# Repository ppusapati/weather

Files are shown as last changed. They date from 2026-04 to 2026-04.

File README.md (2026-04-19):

# Weather Station Firmware

## STM32F407 Weather Station — Embedded Rust Firmware

A production-grade weather station firmware written in Rust targeting the **STM32F407VGT6** MCU.
It collects environmental data from multiple sensors and transmits readings over
**WiFi (ATWINC1500), BLE (RN4870), LoRa, UART, MQTT, and HTTP** — with optional
Ethernet (W5500) and Cellular (SIM7600E-H) connectivity.

---

## Architecture Overview

```
┌─────────────────────────────────────────────────────────────┐
│                    APPLICATION LAYER                        │
│  ┌──────────┐ ┌────────────┐ ┌──────────┐ ┌────────────┐  │
│  │Scheduler │ │Data Pipeline│ │  Power   │ │    OTA     │  │
│  │          │ │  & Fusion  │ │  Mgmt    │ │  Updater   │  │
│  └──────────┘ └────────────┘ └──────────┘ └────────────┘  │
├─────────────────────────────────────────────────────────────┤
│                  COMMUNICATION LAYER                        │
│  ┌──────┐ ┌─────┐ ┌──────┐ ┌──────┐ ┌──────┐ ┌────────┐  │
│  │ WiFi │ │ BLE │ │ LoRa │ │ UART │ │ MQTT │ │  HTTP  │  │
│  └──────┘ └─────┘ └──────┘ └──────┘ └──────┘ └────────┘  │
├─────────────────────────────────────────────────────────────┤
│                     DRIVER LAYER                            │
│  ┌───────┐ ┌──────────┐ ┌──────┐ ┌──────┐ ┌───────────┐  │
│  │BME280 │ │Wind Speed│ │ Rain │ │  UV  │ │   Light   │  │
│  │Temp/  │ │& Dir     │ │Gauge │ │Index │ │  (BH1750) │  │
│  │Hum/Pr │ │(AS5600)  │ │(Tip) │ │SI1145│ │           │  │
│  └───────┘ └──────────┘ └──────┘ └──────┘ └───────────┘  │
├─────────────────────────────────────────────────────────────┤
│                 HARDWARE ABSTRACTION                        │
│  ┌──────┐ ┌──────┐ ┌──────┐ ┌──────┐ ┌──────┐ ┌───────┐  │
│  │ I2C  │ │ SPI  │ │ ADC  │ │ GPIO │ │ UART │ │ Timer │  │
│  └──────┘ └──────┘ └──────┘ └──────┘ └──────┘ └───────┘  │
├─────────────────────────────────────────────────────────────┤
│                   STM32F407 HARDWARE                        │
│  ARM Cortex-M4F @ 168 MHz · 192KB SRAM · 1MB Flash        │
└─────────────────────────────────────────────────────────────┘
```

## MCU Selection — STM32F407VGT6

| Criterion | STM32F407VGT6 |
|---|---|
| CPU | ARM Cortex-M4F @ 168 MHz (with FPU) |
| RAM | 192 KB SRAM (128 KB + 64 KB CCM) |
| Flash | 1 MB internal |
| WiFi | ATWINC1500 module (SPI3) |
| Bluetooth | RN4870 BLE 5.0 module (USART3) |
| ADC | 3x 12-bit SAR, 16 channels |
| I2C / SPI / UART | 3 / 3 / 4 |
| GPIO | 82 programmable |
| Standby | ~2 µA |
| Temp range | -40°C to +105°C (Industrial) |
| Rust support | `stm32f4xx-hal` + `cortex-m-rt` (mature) |

**Why STM32F407?** Industrial temperature range for outdoor deployment, hardware FPU for
sensor math, three SPI buses for concurrent LoRa/Ethernet/WiFi, dedicated UART for each
communication module, and excellent Rust embedded-hal support. Single-MCU architecture
simplifies firmware (one codebase, one toolchain).

## Sensors

| Sensor | Measures | Interface | Address / Pin |
|---|---|---|---|
| BME280 | Temperature, humidity, pressure | I2C | 0x76 |
| AS5600 | Wind direction (magnetic encoder) | I2C | 0x36 |
| Anemometer | Wind speed (pulse count) | GPIO interrupt | GPIO 4 |
| Rain gauge | Rainfall (tipping bucket) | GPIO interrupt | GPIO 5 |
| SI1145 | UV index | I2C | 0x60 |
| BH1750 | Ambient light (lux) | I2C | 0x23 |

## Communication Channels

| Channel | Protocol | Use Case |
|---|---|---|
| **WiFi** | 802.11n | Primary uplink to cloud/MQTT broker |
| **BLE 5.0** | GATT | Mobile app config & live readings |
| **LoRa** | LoRaWAN (SX1276 via SPI) | Long-range low-power telemetry |
| **UART** | Serial 115200 | Debug console & wired data export |
| **MQTT** | MQTT v3.1.1 over TCP/TLS | Cloud telemetry (over WiFi) |
| **HTTP** | REST JSON API | Local web dashboard + OTA updates |

## Industry Modules

The firmware supports optional industry-specific extensions via Cargo features:

| Feature | Industry | Additional Sensors | Analytics |
|---|---|---|---|
| `agriculture` | Precision Farming | Soil moisture (×2), soil temp, leaf wetness | ET₀, GDD, frost alerts, irrigation scheduling, disease risk, spray windows |
| `solar` | Photovoltaic Monitoring | Pyranometer, panel temp (×2), power meter | Irradiance, yield estimation, peak sun hours, performance ratio, soiling loss, cloud transients |
| `india` | Indian Regional | PM2.5 particulate sensor | Monsoon tracking, IMD heat wave alerts, cyclone detection, NAQI air quality, IST timezone, IN865 LoRa |
| `all-industries` | All | All above | All above |
| `cellular` | Remote Sites | SIM7600E-H LTE modem | Cellular uplink for remote stations |
| `ethernet` | Industrial | W5500 wired Ethernet | Reliable wired connectivity + Modbus TCP |
| `sdcard` | Data Logging | Micro-SD card (SPI2) | FAT32 CSV logging with daily file rotation, GB-scale storage |
| `all-comms` | All Comms | Cellular + Ethernet + SD card | All communication + storage channels |
| `full-system` | Everything | All sensors + all comms | All analytics + SCADA + Cloud |

### Operating Modes

| Mode | Cloud (MQTT/HTTP) | SCADA (Modbus RS485) | Selection |
|---|:---:|:---:|---|
| **Cloud** | Yes | — | DIP 0:0 |
| **SCADA** | Yes | Yes | DIP 0:1 |
| **Hybrid** | Yes | Yes | DIP 1:0 (default) |

```bash
# Build with agriculture module
cargo build --release --features agriculture

# Build with solar module
cargo build --release --features solar

# Build with India regional module
cargo build --release --features india

# Build with all industry modules
cargo build --release --features all-industries

# Build with cellular modem support
cargo build --release --features cellular

# Build with Ethernet support
cargo build --release --features ethernet

# Build with SD card data logging
cargo build --release --features sdcard

# Full system: all industries + all comms
cargo build --release --features full-system
```

See [docs/INDUSTRY_AGRICULTURE.md](docs/INDUSTRY_AGRICULTURE.md),
[docs/INDUSTRY_SOLAR.md](docs/INDUSTRY_SOLAR.md),
[docs/INDUSTRY_INDIA.md](docs/INDUSTRY_INDIA.md), and
[docs/STM32_SCADA.md](docs/STM32_SCADA.md) for detailed documentation.

## Building

```bash
# Install Rust + ARM toolchain
rustup install nightly
rustup target add thumbv7em-none-eabihf
cargo install probe-rs-tools

# Build (base weather station)
cd firmware
cargo build --release --target thumbv7em-none-eabihf

# Flash via SWD (ST-Link V2)
probe-rs run --chip STM32F407VGTx target/thumbv7em-none-eabihf/release/weather-station
```

## Project Structure

```
weather/
├── README.md
├── docs/
│   ├── ARCHITECTURE.md
│   ├── REQUIREMENTS.md
│   ├── API.md
│   ├── HARDWARE.md
│   ├── INDUSTRY_INDIA.md
│   └── diagrams/
│       ├── system_architecture.md
│       ├── circuit_diagram.md
│       ├── communication_flow.md
│       ├── state_machine.md
│       ├── data_pipeline.md
│       └── sequence_diagrams.md
├── firmware/
│   ├── Cargo.toml
│   ├── build.rs
│   ├── .cargo/config.toml
│   ├── memory.x
│   └── src/
│       ├── main.rs
│       ├── config.rs
│       ├── error.rs
│       ├── drivers/
│       │   ├── mod.rs
│       │   ├── bme280.rs
│       │   ├── wind.rs
│       │   ├── rain.rs
│       │   ├── uv.rs
│       │   ├── light.rs
│       │   ├── soil_moisture.rs  (agriculture)
│       │   ├── soil_temp.rs      (agriculture/solar)
│       │   ├── leaf_wetness.rs   (agriculture)
│       │   ├── pyranometer.rs    (solar)
│       │   ├── pm25.rs           (india)
│       │   ├── stm32f407.rs     (MCU HAL + pin map)
│       │   ├── atwinc1500.rs   (WiFi SPI driver)
│       │   └── rn4870.rs       (BLE UART driver)
│       ├── comms/
│       │   ├── mod.rs
│       │   ├── wifi.rs
│       │   ├── ble.rs
│       │   ├── lora.rs
│       │   ├── uart_console.rs
│       │   ├── mqtt.rs
│       │   ├── http.rs
│       │   └── modbus_rtu.rs    (Modbus RS485 slave)
│       ├── core/
│       │   ├── mod.rs
│       │   ├── scheduler.rs
│       │   ├── data_pipeline.rs
│       │   ├── power.rs
│       │   ├── ota.rs
│       │   └── mode_manager.rs  (SCADA/Cloud/Hybrid)
│       ├── industry/
│       │   ├── mod.rs
│       │   ├── agriculture.rs    (agriculture)
│       │   ├── solar.rs          (solar)
│       │   └── india.rs          (india)
│       ├── storage/
│       │   ├── mod.rs
│       │   └── flash.rs
│       └── utils/
│           ├── mod.rs
│           ├── fmt.rs
│           ├── ring_buffer.rs
│           └── crc.rs
└── tests/
    └── integration.rs
```

## License

MIT

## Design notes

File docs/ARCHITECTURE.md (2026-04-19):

# System Architecture

## 1. Overview

The weather station firmware follows a **layered architecture** with strict
dependency rules: upper layers depend on lower layers, never the reverse.

```
┌─────────────────────────────────────────────────────────────────────┐
│ LAYER 4 — APPLICATION                                               │
│                                                                     │
│  Scheduler ──► Data Pipeline ──► Power Manager ──► OTA Updater     │
│       │              │                │                              │
│       ▼              ▼                ▼                              │
├─────────────────────────────────────────────────────────────────────┤
│ LAYER 3 — COMMUNICATION                                             │
│                                                                     │
│  WiFi Manager ──► MQTT Client ──► HTTP Server                      │
│  BLE GATT Server                                                    │
│  LoRa Transceiver (SX1276)                                         │
│  UART Console                                                       │
├─────────────────────────────────────────────────────────────────────┤
│ LAYER 2 — DRIVERS                                                   │
│                                                                     │
│  BME280 │ AS5600 │ Anemometer │ Rain Gauge │ SI1145 │ BH1750      │
├─────────────────────────────────────────────────────────────────────┤
│ LAYER 1 — HAL (stm32f4xx-hal)                                       │
│                                                                     │
│  I2C │ SPI │ ADC │ GPIO │ UART │ Timer │ RTC │ NVS                │
├─────────────────────────────────────────────────────────────────────┤
│ LAYER 0 — HARDWARE                                                  │
│                                                                     │
│  STM32F407VGT6 — ARM Cortex-M4F @ 168 MHz                          │
│  192 KB SRAM (128 KB + 64 KB CCM) + 1 MB Flash                    │
│  ATWINC1500 WiFi (SPI3) · RN4870 BLE (USART3)                     │
└─────────────────────────────────────────────────────────────────────┘
```

## 2. Single-Core Cooperative Scheduling

The STM32F407 runs a cooperative task scheduler on a single Cortex-M4F core.
Tasks are time-sliced by priority, with ISRs handling time-critical pulse counting.

| Task Group | Responsibility |
|---|---|
| **Sensor tasks** | Sensor sampling, data fusion, calibration, alerts |
| **Comms tasks** | WiFi poll, BLE poll, LoRa TX/RX, MQTT, HTTP, UART, Modbus RTU |
| **System tasks** | Power management, OTA updates, watchdog feed, status reporting |

All tasks share a single execution context with cooperative yielding.

## 3. Data Flow

```
Sensors ──► Raw ADC / I2C ──► Driver Layer ──► Calibration & Filtering
    │                                                │
    ▼                                                ▼
GPIO ISRs ──► Pulse Counters ──────────────► Data Pipeline
                                                     │
                                         ┌───────────┼───────────┐
                                         ▼           ▼           ▼
                                      Flash       MQTT/HTTP    BLE/LoRa
                                     Storage      (WiFi)      Broadcast
```

### 3.1 Sampling Schedule

| Sensor | Interval | Method |
|---|---|---|
| BME280 (T/H/P) | 10 s | Polled (I2C) |
| Wind speed | Continuous | GPIO ISR pulse count, computed every 5 s |
| Wind direction | 5 s | Polled (I2C — AS5600 angle register) |
| Rain gauge | Continuous | GPIO ISR tip count, accumulated |
| UV index | 30 s | Polled (I2C) |
| Ambient light | 30 s | Polled (I2C) |

### 3.2 Data Fusion

Raw sensor values go through a pipeline:

1. **Calibration** — Apply per-sensor offset/gain from NVS
2. **Filtering** — Exponential moving average (configurable α)
3. **Validation** — Range checks, stuck-sensor detection
4. **Packaging** — Structured `WeatherReading` with timestamp

## 4. Communication Architecture

### 4.1 Channel Priority & Fallback

```
PRIMARY:   WiFi ──► MQTT Broker ──► Cloud Dashboard
                │
                └──► HTTP REST API (local access)

SECONDARY: BLE GATT ──► Mobile App (config + live data)

TERTIARY:  LoRa ──► LoRaWAN Gateway ──► Network Server

DEBUG:     UART ──► Serial Console (always active)
```

If WiFi is unavailable, data is buffered to flash and LoRa becomes the primary
uplink. BLE remains available for local configuration regardless of WiFi state.

### 4.2 MQTT Topic Structure

```
weather/{device_id}/telemetry      — periodic readings (JSON)
weather/{device_id}/status         — heartbeat, battery, RSSI
weather/{device_id}/alerts         — threshold-triggered alerts
weather/{device_id}/cmd            — remote commands (subscribe)
weather/{device_id}/ota            — OTA control channel
```

### 4.3 BLE GATT Services

| Service UUID | Characteristic | Properties |
|---|---|---|
| `0x181A` (Env Sensing) | Temperature | Read, Notify |
| | Humidity | Read, Notify |
| | Pressure | Read, Notify |
| `0xFFE0` (Custom) | Wind Speed | Read, Notify |
| | Wind Direction | Read, Notify |
| | Rain Accumulation | Read, Notify |
| | UV Index | Read, Notify |
| | Light Level | Read, Notify |
| `0xFFE1` (Config) | Sampling Interval | Read, Write |
| | WiFi SSID | Write |
| | WiFi Password | Write |
| | Device Name | Read, Write |

## 5. Power Management

### 5.1 Operating Modes

| Mode | Current Draw | Duration | Trigger |
|---|---|---|---|
| **Active** | ~170 mA | During sampling + TX | Scheduler wake |
| **Sleep (WFI)** | ~20 mA | Between tasks | Auto after TX |
| **Stop** | ~20 µA | Idle periods | Configurable |
| **Standby** | ~2 µA | Extended idle | Battery < 20% |

### 5.2 Battery Monitoring

- ADC channel monitors battery voltage via resistive divider
- Low-battery threshold triggers deep sleep with LoRa-only wake cycle
- Critical battery (<3.3V) triggers graceful shutdown after final status message

## 6. OTA Update Flow

```
1. Device checks /ota endpoint on boot + every 6 hours
2. Server responds with firmware version + SHA256 hash
3. If newer version → download binary over HTTPS
4. Verify SHA256 → write to OTA partition
5. Set boot partition → reboot
6. New firmware validates → mark as stable
7. Failure → rollback to previous partition
```

## 7. Error Handling Strategy

- **Sensor failure**: Mark channel as degraded, report NaN, continue other sensors
- **WiFi failure**: Buffer data to flash, retry with exponential backoff
- **MQTT failure**: Queue messages (up to 1000), replay on reconnect
- **LoRa failure**: Fall back to store-and-forward
- **Flash full**: Overwrite oldest records (circular buffer)
- **Watchdog**: Hardware WDT resets system if main loop stalls > 30 s

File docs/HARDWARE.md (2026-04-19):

# Hardware Design

## 1. Bill of Materials (BOM)

| # | Component | Part Number | Qty | Interface | Notes |
|---|---|---|-----|---|---|
| 1 | STM32F407VGT6 | STM32F407VGT6 | 1 | — | ARM Cortex-M4F, 1MB Flash, 192KB SRAM |
| 2 | BME280 breakout | GY-BME280 | 1 | I2C | Temp/humidity/pressure |
| 3 | AS5600 magnetic encoder | AS5600-ASOM | 1 | I2C | Wind direction |
| 4 | Anemometer | SEN-15901 | 1 | GPIO | Reed switch, 1 pulse/rev |
| 5 | Rain gauge (tipping bucket) | SEN-15902 | 1 | GPIO | 0.2 mm/tip |
| 6 | SI1145 UV sensor | SI1145-A10-GMR | 1 | I2C | UV/Vis/IR |
| 7 | BH1750 light sensor | BH1750FVI | 1 | I2C | Ambient light |
| 8 | SX1276 LoRa module | RFM95W | 1 | SPI | 868/915 MHz |
| 9 | LiPo battery | — | 1 | — | 3.7V 3000mAh |
| 10 | Solar panel | — | 1 | — | 6V 2W |
| 11 | TP4056 charge controller | TP4056 | 1 | — | USB-C + solar input |
| 12 | AMS1117-3.3 regulator | AMS1117-3.3 | 1 | — | 3.3V LDO |
| 13 | Diode magnet (wind vane) | N52 6mm | 1 | — | For AS5600 |
| 14 | Pull-up resistors | — | 4 | — | 4.7kΩ for I2C |
| 15 | Decoupling caps | — | 6 | — | 100nF ceramic |
| 16 | Voltage divider resistors | — | 2 | — | 100kΩ + 100kΩ for batt |
| 17 | Micro-SD card holder | Molex 5031821852 | 1 | SPI2 | Push-push, CS=PD10, DET=PD11 |
| 18 | SD card decoupling cap | — | 1 | — | 100nF on VCC |
| 19 | SD card detect pull-up | — | 1 | — | 10kΩ pull-up on PD11 |

## 2. Pin Mapping

```
STM32F407 Pin Allocation
═══════════════════════════════════════════════════════════

I2C1 Bus (shared):
  PB7  ──── SDA ──── BME280, AS5600, SI1145, BH1750
  PB6  ──── SCL ──── BME280, AS5600, SI1145, BH1750

SPI1 (LoRa SX1276):
  PA7  ──── MOSI ──── SX1276 MOSI
  PA6  ──── MISO ──── SX1276 MISO
  PA5  ──── SCK  ──── SX1276 SCK
  PA4  ──── CS   ──── SX1276 NSS
  PC4  ──── RST  ──── SX1276 RESET
  PC5  ──── DIO0 ──── SX1276 DIO0 (interrupt)

SPI3 (ATWINC1500 WiFi):
  PB5  ──── MOSI ──── ATWINC1500 MOSI
  PB4  ──── MISO ──── ATWINC1500 MISO
  PB3  ──── SCK  ──── ATWINC1500 SCK
  PE3  ──── CS   ──── ATWINC1500 SSn
  PE4  ──── RST  ──── ATWINC1500 RESET
  PE5  ──── IRQ  ──── ATWINC1500 IRQn (EXTI)
  PE6  ──── EN   ──── ATWINC1500 CHIP_EN

USART3 (RN4870 BLE):
  PB10 ──── TX   ──── RN4870 RX
  PB11 ──── RX   ──── RN4870 TX
  PD8  ──── RST  ──── RN4870 RST
  PD9  ──── STATUS ── RN4870 STATUS

GPIO Interrupts (TIM3):
  PB0  ──── WIND ──── Anemometer pulse (TIM3_CH3)
  PB1  ──── RAIN ──── Rain gauge pulse (TIM3_CH4)

ADC:
  PA0  ──── VBAT ──── Battery voltage (via divider)

USART1 (debug console):
  PA9  ──── TX   ──── Debug header
  PA10 ──── RX   ──── Debug header

USART2 (RS485 Modbus):
  PA2  ──── TX   ──── MAX3485 DI
  PA3  ──── RX   ──── MAX3485 RO
  PA1  ──── DE/RE ─── MAX3485 DE/RE

Status LEDs:
  PD0  ──── LED  ──── Status (green)
  PD1  ──── LED  ──── Error (red)
  PD2  ──── LED  ──── SCADA (amber)

SD Card (SPI2 shared bus, optional):
  PD10 ──── CS   ──── SD card CS (active low)
  PD11 ──── DET  ──── SD card detect (active low = inserted)

Mode DIP Switch:
  PE0  ──── DIP0 ──── Mode bit 0
  PE1  ──── DIP1 ──── Mode bit 1
```

## 3. I2C Address Map

| Device | Address | Bus |
|---|---|-----|
| BME280 | 0x76 | I2C0 |
| AS5600 | 0x36 | I2C0 |
| SI1145 | 0x60 | I2C0 |
| BH1750 | 0x23 | I2C0 |

All four devices on a single I2C bus at 400 kHz (fast mode).
4.7 kΩ pull-ups on SDA and SCL.

## 4. Circuit Schematic (Block Level)

```
                        ┌─────────────────────────────────────┐
                        │          STM32F407VGT6              │
                        │                                     │
   ┌─────────┐   I2C   │  PB7 (SDA) ◄──────────────────────┐  │
   │ BME280  │◄────────►│  PB6 (SCL) ◄────────────────┐   │  │
   │ 0x76    │          │                              │   │  │
   └─────────┘          │  PA7 (MOSI) ────────┐       │   │  │
                        │  PA6 (MISO) ◄───┐   │       │   │  │
   ┌─────────┐   I2C   │  PA5 (SCK)  ─┐  │   │       │   │  │
   │ AS5600  │◄────────►│  PA4 (CS)  ──┐│  │   │       │   │  │
   │ 0x36    │          │  PC4 (RST) ──┐││  │   │       │   │  │
   └─────────┘          │  PC5 (IRQ) ◄─┐│││  │   │       │   │  │
                        │               ││││  │   │       │   │  │
   ┌─────────┐   I2C   │               ▼▼▼▼  ▼   ▼       ▼   ▼  │
   │ SI1145  │◄────────►│         ┌──────────────────────┐    │  │
   │ 0x60    │          │         │     SX1276 (LoRa)   │    │  │
   └─────────┘          │         │     RFM95W Module    │    │  │
                        │         └──────────────────────┘    │  │
   ┌─────────┐   I2C   │                                      │  │
   │ BH1750  │◄────────►│  PB0 ◄──── Anemometer (TIM3_CH3)   │  │
   │ 0x23    │          │  PB1 ◄──── Rain gauge (TIM3_CH4)    │  │
   └─────────┘          │  PA0 ◄──── Battery ADC              │  │
                        │                                      │  │
                        │  PA9  ────► UART TX (debug)          │  │
                        │  PA10 ◄──── UART RX (debug)          │  │
                        │                                      │  │
                        │  PB3-PB5 ──► ATWINC1500 WiFi (SPI3) │  │
                        │  PB10-PB11 ► RN4870 BLE (USART3)    │  │
                        │  PB12-PB15 ► SPI2 (W5500 + SD Card) │  │
                        │  PD10 ─────► SD Card CS              │  │
                        │  PD11 ◄────  SD Card Detect          │  │
                        │                                      │  │
                        └──────────────────────────────────────────┘

Power Supply:
  Solar Panel (6V) ──► TP4056 ──► LiPo 3.7V ──► AMS1117 ──► 3.3V rail
                        │
                     USB-C input
```

## 5. Power Budget

| Component | Active (mA) | Sleep (µA) |
|---|---|---|
| STM32F407 @ 168 MHz | 93 | 2.4 (Stop) |
| ATWINC1500 (WiFi TX) | 120 | 10 |
| RN4870 (BLE) | 15 | 5 |
| BME280 | 0.35 | 0.1 |
| AS5600 | 6.5 | 1.5 |
| SI1145 | 5.0 | 0.5 |
| BH1750 | 0.12 | 0.01 |
| SX1276 (TX) | 120 | 0.2 |
| SX1276 (RX) | 12 | 0.2 |
| Micro-SD Card (write) | 100 | 0.2 |
| **Total (active)** | **~350 mA** | — |
| **Total (standby)** | — | **~18 µA** |

## 6. PCB Design Notes

- 4-layer PCB recommended (signal, ground, power, signal)
- Keep SX1276 antenna trace as 50Ω impedance-matched microstrip
- I2C pull-ups close to STM32F407
- Decoupling caps within 5mm of each IC VCC pin
- Ground pour on all layers
- Keep BME280 thermally isolated from heat-generating components
- Conformal coating for outdoor weather resistance
- IP65-rated enclosure minimum

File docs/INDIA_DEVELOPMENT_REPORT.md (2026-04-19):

# Weather Station System — India Development Report

## Project: STM32F407 Weather Station with India Regional Module
## All costs in INR (1 USD ≈ ₹84)

---

## Table of Contents

1. [Executive Summary](#1-executive-summary)
2. [Development Milestones & Timeline](#2-development-milestones--timeline)
3. [Per-Unit Hardware Costing](#3-per-unit-hardware-costing-inr)
4. [One-Time NRE Costs](#4-one-time-nre-non-recurring-engineering-costs)
5. [Infrastructure & Equipment](#5-infrastructure--equipment)
6. [Human Resources](#6-human-resources)
7. [Certification & Compliance](#7-certification--compliance)
8. [Total Project Budget Summary](#8-total-project-budget-summary)
9. [Volume Pricing & Scale Economics](#9-volume-pricing--scale-economics)
10. [Market Analysis — India](#10-market-analysis--india)
11. [Revenue Model & Financial Projections](#11-revenue-model--financial-projections)
12. [Risk Assessment](#12-risk-assessment)
13. [References & Sources](#13-references--sources)

---

## 1. Executive Summary

This report details the full development plan, costing, infrastructure requirements, and
market opportunity for a production-grade ESP32-S3 weather station system with India-specific
regional analytics — including monsoon tracking, IMD heat wave alerts, NAQI air quality
indexing, tropical cyclone detection, and IST timezone support.

**Key Figures:**

| Metric | Value |
|---|---|
| Total project budget (MVP to pilot) | ₹76.2 Lakhs |
| Per-unit cost (prototype, full build) | ₹48,589 |
| Per-unit cost (100-unit volume, full build) | ₹36,540 |
| Timeline (MVP to pilot deployment) | ~50 weeks |
| India Precision Agriculture TAM | USD 305M (2024) → USD 701M (2033) |
| India Smart Agriculture TAM | USD 714M (2024) → USD 3,838M (2033) |
| Cost advantage vs imported stations | 50–90% lower |

---

## 2. Development Milestones & Timeline

### 2.1 Phase Overview

| Phase | Milestone | Duration | Deliverables |
|---|---|---|---|
| **M1** | Requirements & Design | 4 weeks | System architecture, component selection, schematic review, India-specific requirements (IMD standards, WPC regulations) |
| **M2** | PCB Design & Fabrication | 6 weeks | KiCad schematics, Gerber files, 4-layer PCB prototype (5 units from JLCPCB) |
| **M3** | Firmware Core Development | 8 weeks | Sensor drivers (BME280, AS5600, SI1145, BH1750, anemometer, rain gauge), data pipeline with EMA filtering, MQTT/BLE/LoRa/UART comms, cooperative scheduler |
| **M4** | Industry Module Development | 6 weeks | Agriculture module (ET₀, GDD, frost, irrigation, disease risk), Solar module (irradiance, derating, yield, performance ratio), India module (monsoon, heat wave, cyclone, AQI, IST) |
| **M5** | Integration & Calibration | 4 weeks | 3-point temperature calibration, humidity/pressure/UV/light calibration, sensor stuck-detection tuning, power profiling |
| **M6** | Enclosure & Field Testing | 4 weeks | IP65 enclosure assembly, radiation shield, outdoor deployment, 30-day soak test (monsoon + summer conditions) |
| **M7** | Cloud Dashboard & Mobile App | 6 weeks | MQTT broker (EMQX/Mosquitto), InfluxDB time-series storage, Grafana dashboards, Flutter BLE mobile app for provisioning |
| **M8** | Certification & Compliance | 4 weeks | BIS certification, WPC ETA for IN865 LoRa, EMC testing (NABL-accredited), IP65 validation |
| **M9** | Pilot Deployment | 4 weeks | 10-unit field trial across 3 Indian states (plains, coastal, hill), data validation against IMD reference stations |
| **M10** | Production Readiness | 4 weeks | DFM optimization, volume BOM sourcing (Mouser India/LCSC), contract manufacturer onboarding, QC procedures |
| | **Total** | **~50 weeks** | |

### 2.2 Detailed Milestone Breakdown

#### M1: Requirements & Design (Weeks 1–4)

| Task | Duration | Output |
|---|---|---|
| Market requirements analysis (India agriculture, solar, urban air quality) | 1 week | MRD document |
| IMD standards review (heat wave criteria, monsoon definitions, season classification) | 3 days | Compliance checklist |
| WPC India IN865 LoRa band regulations review | 2 days | Regulatory brief |
| Component selection & supplier identification (Indian distributors) | 1 week | Approved vendor list |
| System architecture design (dual-core allocation, task scheduling) | 1 week | Architecture doc |
| Schematic review & design-for-manufacturing assessment | 1 week | DFM report |

#### M2: PCB Design & Fabrication (Weeks 5–10)

| Task | Duration | Output |
|---|---|---|
| Schematic capture (KiCad) with all modules | 2 weeks | .kicad_sch files |
| PCB layout (4-layer, ENIG finish, impedance-controlled for LoRa) | 2 weeks | Gerber files |
| Design rule check + peer review | 3 days | DRC report |
| Prototype order (JLCPCB, 5 units + stencil) | 2 weeks (lead time) | 5 assembled boards |
| Incoming inspection & first power-on | 3 days | Test report |

#### M3: Firmware Core (Weeks 7–18, overlaps with M2)

| Task | Duration | Output |
|---|---|---|
| HAL bring-up (I2C, SPI, ADC, GPIO, UART, Timer) | 1 week | HAL drivers |
| BME280 driver (compensation formulas, I2C protocol) | 1 week | bme280.rs |
| Wind (anemometer ISR + AS5600 direction) + Rain (tipping bucket ISR) | 1 week | wind.rs, rain.rs |
| UV (SI1145) + Light (BH1750) drivers | 4 days | uv.rs, light.rs |
| Data pipeline (calibration → EMA filter → validation → packaging) | 1 week | data_pipeline.rs |
| Cooperative scheduler (interval-based, 17 task slots) | 4 days | scheduler.rs |
| WiFi + MQTT client (esp-wifi, TLS support, reconnect backoff) | 1 week | wifi.rs, mqtt.rs |
| BLE GATT server (Environmental Sensing + custom services) | 1 week | ble.rs |
| LoRa SX1276 driver (SPI, IN865 frequency) | 1 week | lora.rs |
| Flash storage (circular buffer, wear leveling) + NVS config | 4 days | flash.rs, nvs.rs |
| OTA update manager (HTTP download, dual-partition, rollback) | 3 days | ota.rs |
| Power management (modem/light/deep sleep, battery monitoring) | 3 days | power.rs |

#### M4: Industry Modules (Weeks 15–20, overlaps with M3)

| Module | Duration | Key Analytics |
|---|---|---|
| Agriculture | 2 weeks | ET₀ (Penman-Monteith + Hargreaves fallback), GDD with 5 crop presets, frost risk (4-level), irrigation scheduling (5-level), disease risk (Smith period), spray window |
| Solar | 2 weeks | Irradiance tracking, temperature derating (-0.35%/°C), power estimation, daily yield, peak sun hours, performance ratio, soiling model, cloud transient detection |
| India Regional | 2 weeks | Monsoon onset/break/withdrawal, IMD season classification, heat wave (plains/coastal/hill), apparent temperature (Steadman), discomfort index (Thom), cyclone detection (3h pressure), NAQI AQI (CPCB breakpoints), IST day boundary, IN865 LoRa config |

#### M5–M10: Integration through Production (Weeks 21–50)

See Phase Overview table above. Each phase includes specific quality gates:

- **M5 Gate**: All sensors reading within ±2% of calibration reference
- **M6 Gate**: 30-day outdoor deployment with < 1% data loss
- **M7 Gate**: End-to-end data flow from sensor to dashboard verified
- **M8 Gate**: All certifications obtained
- **M9 Gate**: Pilot data correlates within ±5% of IMD reference stations
- **M10 Gate**: Manufacturing partner delivers 10 units matching prototype spec

---

## 3. Per-Unit Hardware Costing (INR)

### 3.1 Base Station BOM

| Category | Components | USD | INR |
|---|---|-----|-----|
| **MCU & Modules** | ESP32-S3-WROOM-1-N16R8 (₹353) + RFM95W LoRa (₹798) | $13.70 | ₹1,151 |
| **Primary Sensors** | BME280 (₹294), AS5600 (₹235), SI1145 (₹269), BH1750 (₹126), Anemometer SEN-15901 (₹3,780), Rain Gauge SEN-15902 (₹2,100), N52 Magnet (₹168) | $83.00 | ₹6,972 |
| **Power Management** | TP4056 (₹25), DW01A (₹13), FS8205A (₹17), AMS1117-3.3 (₹21), Polyfuse (₹29), Schottky SS14 (₹13), TVS SMAJ5.0A (₹25) | $1.70 | ₹143 |
| **Passives** | 22× resistors 0402 (₹18), 16× capacitors (₹27), 4× LEDs 0603 (₹17), 2× tactile buttons (₹34) | $1.14 | ₹96 |
| **Connectors** | USB-C (₹71), 3× JST 2-pin (₹63), 2× RJ11 (₹202), SMA female (₹210), header (₹13), 6× JST 3-pin (₹151), JST 4-pin (₹29), 12× wire harnesses (₹1,008) | $20.80 | ₹1,747 |
| **Power & Battery** | 18650 LiPo 3000mAh (₹672), holder (₹126), 6V 2W solar panel (₹504), USB-C cable (₹252) | $18.50 | ₹1,554 |
| **RF/Antenna** | 868/IN865 MHz antenna 3dBi (₹378), SMA pigtail (₹168) | $6.50 | ₹546 |
| **Base Station BOM Total** | | **$145.34** | **₹12,209** |

### 3.2 Optional Module BOMs

| Module | Components | USD | INR |
|---|---|-----|-----|
| **Agriculture** | 2× Capacitive soil moisture v2.0 (₹588), DS18B20 waterproof (₹336), Leaf wetness sensor (₹672) | $19.00 | ₹1,596 |
| **Solar** | ML8511 pyranometer breakout (₹546), 2× DS18B20 waterproof (₹672), S0 pulse power meter (₹1,008) | $26.50 | ₹2,226 |
| **India Regional** | PM2.5 sensor GP2Y1010AU0F or PMS5003 (₹1,260) | ~$15.00 | ₹1,260 |

**India PM2.5 Sensor Options (Sourced in India):**

| Sensor | Price (INR) | Source | Notes |
|---|---|---|---|
| GP2Y1010AU0F (Sharp) | ₹450–₹700 | Robu.in, Probots | Analog output, cheapest option |
| PMS5003 (Plantower) | ₹1,000–₹1,500 | DNATechIndia, Amazon.in | Digital, PM1.0/2.5/10, higher accuracy |
| SDS011 (Nova) | ₹1,200–₹1,800 | Probots, AliExpress | Laser-based, ±15% accuracy |
| PMS7003 (Plantower) | ₹1,200–₹1,800 | DNATechIndia | Smaller than PMS5003, same accuracy |

### 3.3 PCB Fabrication & Assembly

| Item | Per Unit (INR) | Batch (5 pcs, INR) | Notes |
|---|---|---|---|
| PCB fabrication (4-layer, ENIG) | ₹1,008 | ₹5,040 | JLCPCB, 150×100mm |
| Solder stencil (framed, reusable) | — | ₹2,100 | One-time |
| SMT assembly | ₹1,512 | ₹8,232 | JLCPCB PCBA, includes setup |
| Shipping (DHL Express) | ₹420 | ₹2,100 | — |
| **Per-board total** | **₹3,494** | | |

**PCB Costs at Volume:**

| Quantity | Per-Board (INR) | Total (INR) | Supplier |
|---|---|---|---|
| 5 pcs (prototype) | ₹1,008 | ₹5,040 | JLCPCB |
| 10 pcs | ₹714 | ₹7,140 | JLCPCB |
| 50 pcs | ₹353 | ₹17,640 | JLCPCB |
| 100 pcs | ₹252 | ₹25,200 | JLCPCB/PCBWay |

### 3.4 Outdoor Station Enclosure & Installation

| Category | Items | INR |
|---|---|-----|
| **Main Enclosure (IP65)** | ABS junction box 150×100×60mm (₹1,008), 4× PG7 cable glands IP68 (₹504), 2× PG9 cable glands IP68 (₹336), Gore-Tex vent plug M12 (₹672), M3 standoffs + screws (₹101), M3 nylon lock nuts (₹34), silicone gasket sealant (₹504) | ₹3,160 |
| **Radiation Shield (DIY)** | 3D-printed PETG/ASA shield ~100g (₹672), UV-stable white spray paint (₹420), M4 stainless mounting hardware (₹252) | ₹1,344 |
| **Mounting Pole & Hardware** | Galvanized steel pole 1.5m 32mm OD (₹1,260), pole ground plate/flange (₹672), 2× stainless U-bolts (₹504), pole weather cap (₹168), anemometer L-bracket (₹672), rain gauge bracket (₹420), UV-resistant cable ties 100-pack (₹336), spiral cable conduit 2m (₹420) | ₹4,452 |
| **Paint & Surface Treatment** | Rust-inhibiting primer (₹672), 2× UV-resistant white topcoat (₹1,008), SS polish/passivation (₹420), anti-seize compound (₹504) | ₹2,604 |
| **Weatherproofing** | Conformal coating Humiseal 1A33 55mL (₹1,848), self-amalgamating tape (₹420), heatshrink assortment (₹336), dielectric grease (₹336), marine silicone sealant (₹672) | ₹3,612 |
| **Solar Panel Mount** | Adjustable tilt bracket aluminium (₹840), stainless screws (₹252), MC4 adapter (₹336) | ₹1,428 |
| **Outdoor Station Total** | | **₹16,600** |

### 3.5 Testing & Calibration

#### Per-Unit Testing Labor

| Test Step | Time (min) | Cost @ ₹2,100/hr (INR) |
|---|---|---|
| Visual inspection | 5 | ₹175 |
| Power-on test | 5 | ₹175 |
| Firmware flash | 3 | ₹105 |
| I2C sensor scan | 5 | ₹175 |
| Temperature calibration (3-point) | 30 | ₹1,050 |
| Humidity calibration (2-point) | 20 | ₹700 |
| Pressure calibration (1-point) | 5 | ₹175 |
| Light sensor calibration | 10 | ₹350 |
| Wind sensor verification | 10 | ₹350 |
| Rain gauge verification | 5 | ₹175 |
| WiFi/BLE connectivity test | 5 | ₹175 |
| LoRa IN865 range test | 10 | ₹350 |
| Battery charging test | 10 | ₹350 |
| Write calibration offsets to NVS | 5 | ₹175 |
| Final QA sign-off | 5 | ₹175 |
| **Base Station Total** | **133 min** | **₹4,607** |

#### Optional Module Calibration (Additional)

| Module | Time (min) | Cost (INR) |
|---|---|---|
| Agriculture (soil moisture 2-point, soil temp, leaf wetness) | 45 | ₹1,575 |
| Solar (pyranometer vs reference, panel temp, power meter pulse) | 55 | ₹1,925 |
| India (PM2.5 zero/span, IST day boundary, NAQI breakpoint verify) | 30 | ₹1,050 |

### 3.6 Packaging, Shipping & Consumables

| Category | Items | Per Unit (INR) |
|---|---|---|
| **Product Packaging** | Corrugated box 400×300×200mm (₹294), inner product box (₹420), PE foam die-cut insert (₹336), anti-static bags (₹42), 3× desiccant packets (₹25), bubble wrap (₹84) | ₹1,201 |
| **Docs & Accessories** | Quick start guide (Hindi/English, A5 color) (₹126), pinout/wiring card laminated (₹42), USB-C cable 1m (₹252), 2× spare PG7 glands (₹252), 4× spare JST PH connectors (₹168), mounting screws assortment (₹168) | ₹1,008 |
| **Shipping (Domestic)** | Ground (3 kg) | ₹500 |
| **Consumables (Per-unit share)** | Solder paste, flux, IPA, Kapton tape, labels, wire, heatshrink (shared across ~10 units) | ₹319 |
| **Packaging & Misc Total** | | **₹3,028** |

### 3.7 Per-Unit Cost Summary

| Configuration | BOM | PCB | Testing | Enclosure | Packaging | **Total** |
|---|-----|-----|---|---|---|---|
| **Base Station** | ₹12,209 | ₹3,494 | ₹4,607 | ₹16,600 | ₹3,028 | **₹39,938** |
| **+ Agriculture** | +₹1,596 | — | +₹1,575 | — | — | **₹43,109** |
| **+ Solar** | +₹2,226 | — | +₹1,925 | — | — | **₹44,089** |
| **+ India Regional** | +₹1,260 | — | +₹1,050 | — | — | **₹42,248** |
| **Full Build (All Modules)** | ₹17,291 | ₹3,494 | ₹9,157 | ₹16,600 | ₹3,028 | **₹49,570** |

---

## 4. One-Time NRE (Non-Recurring Engineering) Costs

### 4.1 Test Equipment

| Equipment | INR | Purpose |
|---|-----|---|
| Digital multimeter (Fluke 107 or equivalent) | ₹2,520 | Voltage, current, continuity |
| USB-C power meter/tester | ₹1,260 | Verify charging current |
| Logic analyzer (8-ch, Saleae-compatible) | ₹1,008 | I2C/SPI/UART debugging |
| USB-UART adapter (CP2102/CH340) | ₹420 | Serial console |
| Hot air rework station (Quick 861DW) | ₹5,040 | SMD rework |
| Soldering iron (TS101/Pinecil) | ₹3,780 | Fine-pitch soldering |
| **Test Equipment Total** | **₹14,028** | |

### 4.2 Calibration Reference Standards

| Reference | INR | Purpose |
|---|-----|---|
| NIST-traceable thermometer (±0.1°C) | ₹3,780 | Temperature reference |
| NIST-traceable hygrometer (±2% RH) | ₹5,460 | Humidity reference |
| UV reference meter (calibrated) | ₹7,140 | SI1145 calibration |
| Lux meter (calibrated, Extech LT300) | ₹2,940 | BH1750 calibration |
| **Calibration Standards Total** | **₹19,320** | |

### 4.3 NRE Summary

| Item | INR |
|---|-----|
| Test equipment | ₹14,028 |
| Calibration reference standards | ₹19,320 |
| Solder stencil (reusable) | ₹2,100 |
| **Total One-Time NRE** | **₹35,448** |

### 4.4 First Unit Total Cost (Including NRE)

| Variant | INR |
|---|-----|
| Base Station + NRE | ₹75,386 |
| Full Build (All Modules) + NRE | ₹85,018 |

---

## 5. Infrastructure & Equipment

### 5.1 Development Lab Setup

| Item | INR | Type | Justification |
|---|-----|---|---|
| Embedded development workstations (2×) | ₹2,00,000 | One-time | Rust cross-compilation, JTAG debugging |
| Digital oscilloscope (Rigol DS1054Z, 4-ch 50MHz) | ₹35,000 | One-time | Signal integrity, SPI/I2C debugging |
| Oscilloscope (Siglent SDS1104X-U, 100MHz upgrade) | ₹80,000 | One-time | LoRa RF debugging, power analysis |
| LoRa gateway (RAK7268C, IN865 band) | ₹25,000 | One-time | IN865 LoRaWAN testing |
| Bench power supply (dual-channel, 30V/5A) | ₹8,000 | One-time | Sensor power profiling |
| 3D printer (Creality Ender-3 V3) | ₹25,000 | One-time | Radiation shield, enclosure prototyping |
| PCB rework & assembly station | ₹30,000 | One-time | Hot air + soldering + microscope |
| Environmental test chamber (temp/humidity, -20 to +60°C) | ₹1,50,000 | One-time | Temperature cycling, humidity soak |
| ESD-safe workbench + mat + wrist straps | ₹15,000 | One-time | ESD protection for assembly |
| **Lab Equipment Total** | **₹5,68,000** | | |

### 5.2 Cloud & Software Infrastructure

| Item | Monthly (INR) | Annual (INR) | Notes |
|---|---|---|---|
| MQTT broker (EMQX Cloud or VPS with Mosquitto) | ₹2,000 | ₹24,000 | 1000 device connections |
| Time-series DB (InfluxDB Cloud or self-hosted) | ₹1,500 | ₹18,000 | 30-day retention at pilot scale |
| Grafana Cloud (dashboards) | ₹500 | ₹6,000 | 10 dashboard panels |
| VPS server (2 vCPU, 4GB RAM, DigitalOcean/Hetzner) | ₹1,500 | ₹18,000 | Backend services, OTA server |
| Domain name + TLS certificate | ₹250 | ₹3,000 | Let's Encrypt / paid cert |
| GitHub/GitLab (team, CI/CD runners) | ₹800 | ₹9,600 | Code hosting, automated builds |
| **Cloud Infrastructure Total** | **₹6,550/mo** | **₹78,600/yr** | |

### 5.3 Field Deployment Equipment

| Item | INR | Qty | Notes |
|---|-----|-----|---|
| Portable WiFi hotspot (Jio/Airtel 4G) | ₹2,000 | 3 | Field provisioning, initial setup |
| Laptop (field deployment, ruggedized) | ₹60,000 | 1 | On-site firmware flash, calibration |
| LoRa range test kit (handheld spectrum analyzer) | ₹15,000 | 1 | IN865 coverage verification |
| Tool kit (weatherproof, field service) | ₹5,000 | 1 | Screwdrivers, pliers, crimpers, cable ties |
| Vehicle/travel budget (3 states, pilot) | ₹1,50,000 | — | Pilot deployment logistics |
| **Field Equipment Total** | **₹2,32,000** | | |

### 5.4 Infrastructure Summary

| Category | INR |
|---|-----|
| Lab equipment & workstations | ₹5,68,000 |
| Cloud & software (Year 1) | ₹78,600 |
| Field deployment equipment | ₹2,32,000 |
| **Infrastructure Grand Total** | **₹8,78,600** |

---

## 6. Human Resources

### 6.1 Core Development Team

| Role | Count | Monthly CTC (INR) | Duration | Total (INR) |
|---|---|---|---|---|
| Embedded Rust Engineer (Lead) | 1 | ₹1,50,000 | 12 months | ₹18,00,000 |
| Embedded Firmware Engineer | 1 | ₹1,00,000 | 10 months | ₹10,00,000 |
| Hardware/PCB Design Engineer | 1 | ₹1,00,000 | 6 months | ₹6,00,000 |
| Full-Stack Developer (Dashboard + Mobile App) | 1 | ₹1,00,000 | 6 months | ₹6,00,000 |
| QA/Test Engineer | 1 | ₹60,000 | 6 months | ₹3,60,000 |
| Field Deployment Technician | 1 | ₹40,000 | 4 months | ₹1,60,000 |
| Project Manager (part-time, 50%) | 0.5 | ₹75,000 | 12 months | ₹4,50,000 |
| **Team Total** | **5.5 FTE** | | | **₹49,70,000** |

### 6.2 Key Skill Requirements

| Role | Required Skills |
|---|---|
| **Embedded Rust Lead** | Rust (no_std), ESP32/Xtensa, embedded-hal, esp-hal, RTOS concepts, I2C/SPI/UART, LoRaWAN, BLE GATT, OTA, power management |
| **Firmware Engineer** | Rust, sensor driver development, DSP (EMA/FIR filters), data validation, circular buffers, flash wear leveling |
| **Hardware Engineer** | KiCad, 4-layer PCB design, impedance control (RF), EMC design, power supply design (LiPo charging, LDO), antenna matching |
| **Full-Stack Developer** | MQTT, InfluxDB/TimescaleDB, Grafana, React/Vue dashboards, Flutter (BLE mobile app), REST APIs |
| **QA Engineer** | Embedded test automation, sensor calibration procedures, environmental testing, regression testing, field validation |

### 6.3 Optional/Contract Resources

| Role | Estimated Cost (INR) | Duration | When Needed |
|---|---|---|---|
| RF/Antenna consultant (IN865 compliance) | ₹1,00,000 | 2 weeks | M8 (Certification) |
| BIS certification consultant | ₹50,000 | 4 weeks | M8 (Certification) |
| Industrial design (enclosure, 3D CAD) | ₹75,000 | 3 weeks | M6 (Enclosure) |
| Technical writer (user manual, Hindi/English) | ₹30,000 | 2 weeks | M9 (Pilot) |
| **Contract Resources Total** | **₹2,55,000** | | |

---

## 7. Certification & Compliance

### 7.1 Required Certifications for India Market

| Certification | Authority | Cost (INR) | Duration | Required For |
|---|---|---|---|---|
| BIS certification (IS 14874/IEC 60945) | Bureau of Indian Standards | ₹2,00,000 | 8–12 weeks | Electronic equipment sale in India |
| WPC ETA (Equipment Type Approval) | Wireless Planning & Coordination Wing, DoT | ₹1,50,000 | 6–8 weeks | IN865 LoRa radio transmission |
| EMC testing (NABL-accredited lab) | NABL-accredited test lab | ₹1,00,000 | 2–3 weeks | EMI/EMC compliance (IS 11454) |
| IP65 ingress protection testing | Third-party test lab | ₹50,000 | 1 week | Weatherproofing validation |
| **Certification Total** | | **₹5,00,000** | | |

### 7.2 Regulatory Compliance Notes

| Requirement | Details |
|---|---|
| **IN865 LoRa Band** | 865.0–867.0 MHz, max 36 dBm EIRP, duty cycle restrictions per WPC guidelines |
| **BIS Compulsory Registration** | Required for electronics sold in India under CRS scheme |
| **E-Waste (EPR)** | Extended Producer Responsibility registration if > 100 units/year |
| **Metrological Standards** | Optional: IS 4904 for meteorological instruments (for government tenders) |
| **Data Privacy** | Compliance with Digital Personal Data Protection Act 2023 for cloud-stored data |

### 7.3 Government Tender Requirements

For selling to ICAR, IMD, state agriculture departments:

| Requirement | Action | Cost |
|---|---|---|
| MSME/Udyam registration | Self-registration | Free |
| GeM (Government e-Marketplace) registration | Online registration | Free |
| ISO 9001:2015 quality management | Third-party audit | ₹1,50,000 |
| Make in India certification | Documentation | ₹25,000 |
| **Government Readiness Total** | | **₹1,75,000** |

---

## 8. Total Project Budget Summary

### 8.1 Development Phase (MVP to Pilot)

| Category | INR | % of Total |
|---|-----|---|
| Human resources (12 months, 5.5 FTE) | ₹49,70,000 | 62.5% |
| Development infrastructure (lab + cloud Year 1) | ₹8,78,600 | 11.0% |
| Prototype hardware (10 full-build units @ ₹49,570) | ₹4,95,700 | 6.2% |
| NRE (test equipment + calibration standards) | ₹35,448 | 0.4% |
| Certification & compliance | ₹5,00,000 | 6.3% |
| Contract resources (RF consultant, BIS, design, writer) | ₹2,55,000 | 3.2% |
| Pilot deployment (10 stations, 3 states, travel) | ₹1,50,000 | 1.9% |
| Contingency (10%) | ₹6,92,475 | 8.7% |
| **Grand Total (MVP to Pilot)** | **₹79,77,223** | **100%** |
| | **~₹80 Lakhs** | |

### 8.2 Budget by Milestone Phase

| Phase | Primary Spend | Cumulative (INR) |
|---|---|---|
| M1: Requirements & Design | Team salary (₹4L), supplier visits | ₹4,50,000 |
| M2: PCB Design & Fabrication | Team (₹6L), PCB order (₹0.5L) | ₹11,00,000 |
| M3: Firmware Core | Team (₹12L), lab equipment (₹5.7L) | ₹28,70,000 |
| M4: Industry Modules | Team (₹9L) | ₹37,70,000 |
| M5: Integration & Calibration | Team (₹6L), NRE (₹0.35L), prototypes (₹5L) | ₹49,05,000 |
| M6: Enclosure & Field Testing | Team (₹4L), enclosures (₹1.7L) | ₹54,75,000 |
| M7: Cloud & App | Team (₹9L), cloud infra (₹0.8L) | ₹64,55,000 |
| M8: Certification | Team (₹4L), certifications (₹5L) | ₹73,55,000 |
| M9: Pilot Deployment | Team (₹2L), travel/logistics (₹1.5L) | ₹77,05,000 |
| M10: Production Readiness | Team (₹2L), contingency applied | ₹79,77,223 |

---

## 9. Volume Pricing & Scale Economics

### 9.1 Per-Unit Cost at Scale (Full Build — All Modules)

| Volume | BOM | PCB/Assembly | Testing | Enclosure | Packaging | **Per Unit** |
|---|-----|---|---|---|---|---|
| 1 unit (prototype) | ₹17,291 | ₹3,494 | ₹9,157 | ₹16,600 | ₹3,028 | **₹49,570** |
| 5 units | ₹17,291 | ₹3,494 | ₹9,157 | ₹16,600 | ₹3,028 | **₹49,570** |
| 10 units | ₹15,562 | ₹2,856 | ₹7,326 | ₹14,940 | ₹2,520 | **₹43,204** |
| 50 units | ₹13,833 | ₹2,100 | ₹5,494 | ₹12,600 | ₹2,100 | **₹36,127** |
| 100 units | ₹12,600 | ₹1,680 | ₹4,200 | ₹11,340 | ₹1,680 | **₹31,500** |
| 500 units | ₹10,500 | ₹1,260 | ₹2,940 | ₹9,240 | ₹1,260 | **₹25,200** |
| 1000 units | ₹9,240 | ₹1,008 | ₹2,100 | ₹8,400 | ₹1,050 | **₹21,798** |

### 9.2 Cost Reduction Strategies

| Strategy | Savings Per Unit | Trade-off |
|---|---|---|
| HASL finish instead of ENIG | ₹672/board | Reduced corrosion resistance |
| 2-layer PCB (drop impedance control) | ₹420/board | Lose LoRa RF performance |
| Commercial-grade ESP32 (drop -I suffix) | ₹126/unit | 0°C lower operating limit |
| Source from LCSC/AliExpress | ₹1,260–₹2,100/unit | Longer lead time, QC risk |
| 3D-print enclosure (PETG/ASA) | ₹1,680 savings | Less IP protection |
| Skip conformal coating | ₹1,848 savings | Reduced outdoor durability |
| DIY assembly (no PCBA service) | ₹1,512/board | Requires skilled technician |
| Bundle anemometer + rain gauge kit | ₹840–₹1,260 savings | Source SparkFun kit |

### 9.3 Suggested Retail Pricing

| Configuration | Per Unit Cost (100) | Suggested MRP (INR) | Margin |
|---|---|---|---|
| Base Station | ₹26,000 | ₹45,000 | 73% |
| Base + Agriculture | ₹29,000 | ₹52,000 | 79% |
| Base + Solar | ₹29,500 | ₹52,000 | 76% |
| Base + India Regional | ₹28,000 | ₹48,000 | 71% |
| Full Build (All Modules) | ₹31,500 | ₹59,000 | 87% |

### 9.4 Price Comparison vs Competition

| Product | Price (INR) | Origin | Our Advantage |
|---|---|---|---|
| Davis Vantage Vue | ₹45,000–₹60,000 | USA (import) | Similar price, we add India module + LoRa |
| Davis Vantage Pro2 | ₹1,20,000–₹2,00,000 | USA (import) | 60–75% cheaper |
| Campbell Scientific CR1000X | ₹5,00,000+ | UK (import) | 90% cheaper, same sensor accuracy class |
| Fasal IoT Kit | ₹15,000–₹25,000 (est.) | India | We add weather station + multi-protocol |
| IMD AWS (government) | ₹3,00,000–₹10,00,000 | Various | 95%+ cheaper, Make in India |
| DIY ESP32 weather station | ₹3,000–₹8,000 | Self-built | We are production-grade, certified |

---

## 10. Market Analysis — India

### 10.1 Addressable Market Size

| Segment | Market Size (2024) | Projected (2033) | CAGR |
|---|---|---|---|
| India Smart Agriculture | USD 714M (₹6,000 Cr) | USD 3,838M (₹32,240 Cr) | 20.5% |
| India Precision Agriculture | USD 305M (₹2,562 Cr) | USD 701M (₹5,888 Cr) | 9.7% |
| India Agritech | USD 974M (₹8,182 Cr) | USD 2,521M (₹21,176 Cr) | 10.6% |
| India IoT Devices | USD 2,886M (₹24,242 Cr) | USD 10,277M (₹86,327 Cr) | 23.2% |
| India IoT (Overall) | USD 49B (₹4,11,600 Cr) | USD 351B (₹29,48,400 Cr) | 19.6% |
| Global Precision Farming | USD 11.72B (₹98,448 Cr) | USD 27.91B (₹2,34,444 Cr) | 13.2% |

### 10.2 Key Market Drivers

| Driver | Impact |
|---|---|
| **India's agricultural workforce** | 43% of workforce, 18% of GDP — massive modernization potential |
| **Government push** | Mission Mausam (₹2,000 Cr), ICAR-GKMS expansion, Smart Cities Mission, Digital Agriculture Mission |
| **Climate vulnerability** | India faces increasing heat waves, erratic monsoons, cyclones — hyperlocal monitoring critical |
| **Air quality crisis** | 14 of world's 20 most polluted cities are in India; Haryana's AQI stations went offline for months in 2025 |
| **Declining sensor costs** | ESP32 + PM2.5 + BME280 total < ₹2,000; democratizes access |
| **LoRa adoption** | IN865 band enables rural deployment without WiFi; TSDSI promoting LoRaWAN |
| **FPO expansion** | 10,000+ Farmer Producer Organizations need data tools; government subsidizing tech adoption |
| **Satellite-to-ground gap** | Pixxel/SatSure provide satellite analytics but need ground-truth weather data for calibration |

### 10.3 Government Opportunity Pipeline

| Programme | Budget/Scale | Weather Station Opportunity |
|---|---|---|
| **Mission Mausam** | ₹2,000 Cr | IMD expanding AWS network; 3D-printed AWS already developed under Make in India |
| **ICAR-GKMS** | 200 DAMUs being equipped | Block-level agro-AWS for weather advisory |
| **PM-AASHA** | Agricultural price support | Weather data needed for yield estimation |
| **PMFBY** (Crop Insurance) | ₹25,000 Cr annually | Hyperlocal weather data for claim validation |
| **Smart Cities Mission** | 100 cities | Urban air quality + weather monitoring networks |
| **National Clean Air Programme** | 131 cities | PM2.5/PM10 monitoring station deployment |
| **Digital Agriculture Mission** | Phase 2 launching | Farm-level digital infrastructure |

### 10.4 Competitive Landscape

#### Direct Competitors

| Competitor | Focus | Funding | Key Product | Strength | Weakness |
|---|---|---|---|---|---|
| **CropIn** | AI crop intelligence SaaS | Multi-round | Cropin Cloud | 30M+ acres digitized, Google Gemini partnership, 350 crops | SaaS only, no hardware |
| **Fasal** | IoT precision horticulture | $17M+ | On-farm sensor + app | Microclimate forecasts, pest prediction, 40% productivity gains | Horticulture-focused, limited crops |
| **AgNext** | Food quality assessment | Series A+ | Qualix | Rapid quality testing (tea, spices, grains) | Post-harvest focus, not field monitoring |
| **DeHaat** | Agri supply chain | $100M+ | Full-stack platform | 1.5M farmer network | Marketplace, not monitoring |
| **WRMS** | Weather risk management | Established | SecuFarm | Income guarantee, crop insurance integration | Enterprise-only |
| **Davis Instruments** | Commercial weather stations | US-based | Vantage Pro2 | Proven reliability, global distribution | Imported, expensive, no India-specific features |
| **Campbell Scientific** | Research-grade AWS | UK-based | CR1000X | Gold standard accuracy | ₹5L+ per station, not accessible |

#### Our Differentiation

| Advantage | Detail |
|---|---|
| **India-first analytics** | Only product with native IMD heat wave thresholds, monsoon onset tracking, NAQI AQI, cyclone detection, and IST timezone — no competitor offers this |
| **50–90% cost reduction** | ₹45K–₹59K vs ₹50K–₹5L+ for imported stations |
| **Multi-protocol communications** | WiFi + BLE + LoRa (IN865) + UART — works in rural India without WiFi via LoRa |
| **Open firmware (Rust)** | Auditable, no vendor lock-in, community-extensible, safety guarantees (no_std Rust) |
| **Make in India** | Domestic manufacturing; aligns with government procurement preferences & GeM |
| **Modular feature flags** | Agriculture, Solar, India modules independently toggleable — pay only for what you need |
| **Embedded Rust** | Memory safety without garbage collection; zero-cost abstractions; no runtime crashes |

### 10.5 Target Customer Segments

| Segment | Count | Avg. Order Size | Total Addressable (INR) | Priority |
|---|---|---|---|---|
| **ICAR KVKs** (Krishi Vigyan Kendras) | 731 centres | 2–5 stations each | ₹10–₹20 Cr | High |
| **State agriculture departments** | 28 states + 8 UTs | 10–50 stations per tender | ₹15–₹75 Cr | High |
| **Farmer Producer Organizations** | 10,000+ registered | 1–3 stations each | ₹45–₹135 Cr | Medium |
| **Agritech startups** (OEM/white-label) | 50+ companies | 50–500 units/year | ₹12–₹150 Cr | High |
| **Solar farms / IPPs** | 70+ GW capacity | 1–5 per 10 MW plant | ₹5–₹25 Cr | Medium |
| **Smart City projects** | 100 cities | 10–100 per city | ₹5–₹60 Cr | Medium |
| **Agricultural universities** | 500+ institutions | 3–10 stations each | ₹7–₹25 Cr | Medium |
| **Tea/coffee estates** | 1,500+ estates | 2–5 stations each | ₹13–₹40 Cr | Medium |
| **Urban municipalities** (air quality) | 131 NCAP cities | 5–50 per city | ₹3–₹40 Cr | Medium |

### 10.6 Go-to-Market Strategy

| Phase | Timeline | Strategy | Target |
|---|---|---|---|
| **Phase 1: Seed** | Months 1–6 | Direct sales to 2–3 ICAR KVKs + 1 state agriculture department | 20 units |
| **Phase 2: Validate** | Months 7–12 | Expand to 5 states, publish field data papers, GeM registration | 80 units |
| **Phase 3: Scale** | Year 2 | OEM partnerships with Fasal/CropIn, government tenders (PMFBY/Mission Mausam) | 200 units |
| **Phase 4: National** | Year 3 | Pan-India distribution, Smart City bids, NCAP air quality tenders | 500+ units |

---

## 11. Revenue Model & Financial Projections

### 11.1 Revenue Streams

| Stream | Description | Margin |
|---|---|---|
| **Hardware sales** | Weather station units (base/full configurations) | 70–87% gross |
| **Cloud SaaS** | Dashboard, alerts, data storage (₹500/station/month) | 85% |
| **Maintenance & calibration** | Annual recalibration, sensor replacement (₹5,000/station/year) | 60% |
| **Custom integration / OEM** | White-label for agritech startups, API licensing | 50–70% |
| **Government tenders** | State/central procurement (higher volume, lower margin) | 40–50% |

### 11.2 Three-Year Financial Projection

| Metric | Year 1 | Year 2 | Year 3 |
|---|---|---|---|
| **Units Sold** | 50 | 200 | 500 |
| **Hardware Revenue** | ₹24,50,000 | ₹94,00,000 | ₹2,36,00,000 |
| **SaaS Revenue** (cumulative stations) | ₹1,50,000 | ₹9,00,000 | ₹27,00,000 |
| **Maintenance Revenue** | ₹1,25,000 | ₹6,25,000 | ₹18,75,000 |
| **Custom/OEM Revenue** | ₹5,00,000 | ₹15,00,000 | ₹30,00,000 |
| **Total Revenue** | **₹32,25,000** | **₹1,24,25,000** | **₹3,11,75,000** |
| | **₹32.25L** | **₹1.24 Cr** | **₹3.12 Cr** |
| **COGS (hardware)** | ₹12,25,000 | ₹38,00,000 | ₹94,50,000 |
| **Gross Profit** | ₹20,00,000 | ₹86,25,000 | ₹2,17,25,000 |
| **Gross Margin** | 62% | 69% | 70% |
| **Operating Expenses** | ₹65,00,000 | ₹75,00,000 | ₹1,10,00,000 |
| **Net Profit / (Loss)** | **(₹45,00,000)** | **₹11,25,000** | **₹1,07,25,000** |
| **Breakeven** | — | **Month 18–20** | — |

### 11.3 Unit Economics (Steady State, Year 3)

| Metric | Value |
|---|---|
| Average selling price (ASP) | ₹47,200 |
| COGS per unit | ₹18,900 |
| Gross margin per unit | ₹28,300 (60%) |
| Lifetime SaaS revenue (3 years) | ₹18,000 |
| Lifetime maintenance revenue (3 years) | ₹15,000 |
| **Customer Lifetime Value (CLV)** | **₹61,300** |

---

## 12. Risk Assessment

### 12.1 Technical Risks

| Risk | Probability | Impact | Mitigation |
|---|---|---|---|
| ESP32-S3 supply shortage | Medium | High | Qualify alternate MCU (ESP32-C6); maintain 3-month buffer stock |
| PM2.5 sensor degradation in harsh Indian conditions | High | Medium | Use PMS5003 with intake filter; schedule sensor replacement at 8000h laser life |
| LoRa IN865 interference in urban areas | Medium | Medium | Adaptive data rate (ADR); fallback to WiFi/BLE |
| Monsoon exposure exceeds IP65 rating | Medium | High | IP67 upgrade option; conformal coating mandatory; silicone-sealed cable glands |
| Sensor accuracy drift over time | Medium | Medium | Annual recalibration service; NVS-stored offsets; self-test routines |

### 12.2 Market & Business Risks

| Risk | Probability | Impact | Mitigation |
|---|---|---|---|
| Government tender delays (6–12 month cycles) | High | High | Diversify into private sector (agritech OEM, plantations) simultaneously |
| Price competition from Chinese imports | Medium | High | Differentiate on India-specific analytics; Make in India preference in tenders |
| CropIn/Fasal building own hardware | Low | High | Pursue OEM/partnership model proactively; open-source builds community moat |
| Slow farmer adoption (tech literacy) | High | Medium | Partner with KVKs for training; multilingual UI (Hindi, Tamil, Telugu, Marathi) |
| Certification delays (BIS/WPC) | Medium | Medium | Start certification process in M6 (parallel with field testing) |

### 12.3 Financial Risks

| Risk | Probability | Impact | Mitigation |
|---|---|---|---|
| Longer runway to breakeven (> 20 months) | Medium | High | Reduce burn rate with contract hires; apply for MEITY/DST grants |
| FX rate fluctuation (components priced in USD) | Medium | Medium | Source from Indian distributors (Probots, Robu); hedge with 3-month purchase commitments |
| Higher customer acquisition cost in B2G | High | Medium | GeM platform reduces CAC; leverage ICAR network |

---

## 13. References & Sources

### Market Research

- [India Smart Agriculture Market — IMARC Group](https://www.imarcgroup.com/india-smart-agriculture-market)
- [India Precision Agriculture Market — IMARC Group](https://www.imarcgroup.com/india-precision-agriculture-market)
- [India Agritech Market — IMARC Group](https://www.imarcgroup.com/india-agritech-market)
- [India AgriTech Precision Farming Market — Research and Markets](https://www.researchandmarkets.com/reports/6211735/india-agritech-precision-farming-market)
- [India Precision Farming Market — Mobility Foresights](https://mobilityforesights.com/product/india-precision-farming-market)
- [Smart Agriculture Market — Straits Research](https://straitsresearch.com/report/smart-agriculture-market)
- [Precision Farming Market — Coherent Market Insights](https://www.coherentmarketinsights.com/industry-reports/precision-farming-market)
- [Agricultural Weather Monitoring Market — Knowledge Sourcing](https://www.knowledge-sourcing.com/report/agricultural-weather-monitoring-market)

### Industry & Startups

- [Agritech Startups India 2025 — Agro Spectrum India](https://agrospectrumindia.com/2025/12/23/startups-that-matter-how-indian-agritech-became-pillar-of-food-security-in-2025.html)
- [Top Agritech Startups in India — GetFarms](https://getfarms.in/agritech-startups-india)
- [Agritech Trends India 2026 — Farmonaut](https://farmonaut.com/asia/agtech-funding-news-top-10-agritech-trends-india-2026)
- [Agritech in India 2025–2030 — India Employer Forum](https://indiaemployerforum.org/world-of-work/agritech-in-india-emerging-careers/)
- [27 Agritech Startups in India — Inc42](https://inc42.com/startups/27-agritech-startups-disrupting-agricultural-landscape-in-india/)
- [Fasal Seed Funding — AgFunder News](https://agfundernews.com/breaking-indias-fasal-raises-1-6m-seed-funding-to-build-out-precision-ag-across-southeast-asia)
- [Space-Tech in Indian Agriculture — Outlook Business](https://www.outlookbusiness.com/start-up/news/how-agriculture-is-propelling-the-growth-of-indias-spacetech-start-ups)

### Government Programmes

- [Mission Mausam 3D-Printed AWS — GKToday](https://www.gktoday.in/india-develops-3d-printed-automatic-weather-stations-under-mission-mausam/)
- [IMD AWS Expansion — PIB](https://www.pib.gov.in/PressReleasePage.aspx?PRID=2214967&reg=3&lang=1)
- [ICAR Agro-AWS at DAMUs — PIB](https://www.pib.gov.in/Pressreleaseshare.aspx?PRID=1706937)

### Technical References

- [IoT AQI Monitoring with ESP32 — Circuit Digest](https://circuitdigest.com/microcontroller-proejcts/iot-based-air-quality-index-monitoring-system-measure-pm25-pm10-co-using-esp32)
- [ESP32 Air Quality Monitoring — Electronics For You](https://www.electronicsforu.com/electronics-projects/esp32-based-air-quality-monitoring-system)
- [PMS5003 PM2.5 Sensor — Amazon India](https://www.amazon.in/Detection-Particle-Concentration-Conditioning-Compatible/dp/B0BHZTCK8J)
- [PMS5003 Sensor — DNATechIndia](https://www.dnatechindia.com/pms5003-pm2.5-air-quality-sensor-buy-in-india.html)
- [SDS011 Sensor — Probots India](https://probots.co.in/nova-pm-sensor-sds011-high-precision-laser-pm2-5-air-quality-detection-sensor.html)
- [CPCB National Air Quality Index — CPCB](https://cpcb.nic.in/AQI_Bulletin.php)

### Component Sourcing (India)

- [Probots.co.in](https://probots.co.in) — Arduino, ESP32, sensors, robotics
- [DNATechIndia.com](https://www.dnatechindia.com) — PM2.5 sensors, development boards
- [Robu.in](https://robu.in) — Electronic components, sensors
- [Amazon.in](https://www.amazon.in) — Consumer electronic components
- [JLCPCB](https://jlcpcb.com) — PCB fabrication & assembly
- [LCSC](https://lcsc.com) — Component sourcing (bulk)
- [Mouser India](https://www.mouser.in) — Industrial-grade components

---

*Document generated: February 2026*
*Project: ESP32-S3 Weather Station with India Regional Module*
*Repository: weather-station-firmware*

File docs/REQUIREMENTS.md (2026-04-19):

# Requirements Specification

## 1. Functional Requirements

### FR-1: Sensor Data Acquisition
- **FR-1.1**: Read temperature (±0.5°C), humidity (±3%), barometric pressure (±1 hPa) from BME280
- **FR-1.2**: Measure wind speed (0–160 km/h, ±2 km/h) via pulse-counting anemometer
- **FR-1.3**: Measure wind direction (0–359°, ±3°) via AS5600 magnetic encoder
- **FR-1.4**: Accumulate rainfall (0.2 mm per tip) via tipping-bucket gauge
- **FR-1.5**: Read UV index (0–15) from SI1145
- **FR-1.6**: Read ambient light (1–65535 lux) from BH1750
- **FR-1.7**: All sensor readings timestamped with RTC (synced via NTP when WiFi available)

### FR-2: Data Processing
- **FR-2.1**: Apply calibration offsets stored in NVS flash
- **FR-2.2**: Filter readings with configurable exponential moving average
- **FR-2.3**: Validate readings against physical range limits
- **FR-2.4**: Compute derived values: heat index, wind chill, dew point
- **FR-2.5**: Generate alerts when readings exceed configurable thresholds

### FR-3: WiFi Communication
- **FR-3.1**: Connect to WPA2 network with credentials stored in NVS
- **FR-3.2**: Auto-reconnect with exponential backoff on disconnection
- **FR-3.3**: Support provisioning via BLE when no WiFi credentials stored

### FR-4: MQTT Telemetry
- **FR-4.1**: Publish readings to MQTT broker at configurable interval (default 30 s)
- **FR-4.2**: Support TLS-encrypted connections
- **FR-4.3**: Buffer messages during disconnection (up to 1000 messages)
- **FR-4.4**: Subscribe to command topic for remote configuration

### FR-5: HTTP REST API
- **FR-5.1**: Serve current readings at `GET /api/v1/current`
- **FR-5.2**: Serve historical data at `GET /api/v1/history?hours=N`
- **FR-5.3**: Accept configuration changes at `POST /api/v1/config`
- **FR-5.4**: Serve OTA firmware upload at `POST /api/v1/ota`
- **FR-5.5**: Serve a minimal status page at `GET /`

### FR-6: BLE Interface
- **FR-6.1**: Advertise Environmental Sensing service (0x181A)
- **FR-6.2**: Support GATT read + notify for all sensor values
- **FR-6.3**: Support GATT write for configuration parameters
- **FR-6.4**: WiFi provisioning via custom BLE characteristic

### FR-7: LoRa Communication
- **FR-7.1**: Transmit compressed readings via SX1276 (SPI)
- **FR-7.2**: Support LoRaWAN Class A operation
- **FR-7.3**: Configurable spreading factor (SF7–SF12)
- **FR-7.4**: Serve as fallback when WiFi unavailable

### FR-8: UART Console
- **FR-8.1**: Output structured log messages at 115200 baud
- **FR-8.2**: Accept diagnostic commands (status, reset, calibrate)
- **FR-8.3**: Support raw data dump mode for debugging

### FR-9: Data Storage
- **FR-9.1**: Store readings in flash as circular buffer (min 7 days at 30 s interval)
- **FR-9.2**: Store configuration in NVS partition
- **FR-9.3**: Store calibration data in NVS partition

### FR-10: OTA Updates
- **FR-10.1**: Check for updates on boot and periodically (6-hour interval)
- **FR-10.2**: Download and verify firmware image (SHA-256)
- **FR-10.3**: Automatic rollback on boot failure

## 2. Non-Functional Requirements

### NFR-1: Performance
- Sensor read cycle completes within 500 ms
- MQTT publish latency < 2 s from reading to broker
- HTTP API response time < 200 ms
- BLE notification latency < 500 ms

### NFR-2: Reliability
- Mean time between failures > 30 days continuous operation
- Graceful degradation: individual sensor failure does not halt system
- Watchdog timer (30 s) prevents permanent hangs
- Data preserved across unexpected reboots

### NFR-3: Power Efficiency
- Active mode current < 200 mA average
- Deep sleep current < 50 µA
- Support solar panel + LiPo battery operation
- Minimum 48-hour operation on 3000 mAh battery (no solar)

### NFR-4: Security
- All WiFi traffic encrypted (WPA2)
- MQTT over TLS (optional, configurable)
- BLE pairing required for write operations
- OTA images cryptographically verified
- No plaintext credentials in firmware binary

### NFR-5: Maintainability
- Modular driver architecture — add sensor without modifying core
- All magic numbers defined as named constants
- Comprehensive error types with context
- Structured logging with severity levels

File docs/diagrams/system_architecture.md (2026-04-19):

# System Architecture Diagram

## Multi-Layer Architecture

```
╔═══════════════════════════════════════════════════════════════════════════╗
║                                                                           ║
║  LAYER 5: CLOUD / EXTERNAL SYSTEMS                                       ║
║  ┌─────────────────┐  ┌─────────────────┐  ┌─────────────────────────┐   ║
║  │  MQTT Broker    │  │  LoRaWAN        │  │  Mobile App (BLE)       │   ║
║  │  (Mosquitto /   │  │  Network Server │  │  iOS / Android          │   ║
║  │   AWS IoT)      │  │  (TTN/Chirp)    │  │                         │   ║
║  └────────┬────────┘  └────────┬────────┘  └────────────┬────────────┘   ║
║           │                    │                         │                ║
╠═══════════╪════════════════════╪═════════════════════════╪════════════════╣
║           │                    │                         │                ║
║  LAYER 4: APPLICATION          │                         │                ║
║  ┌────────┴────────────────────┴─────────────────────────┴────────────┐   ║
║  │                        SCHEDULER                                   │   ║
║  │  ┌──────────────┐  ┌──────────────┐  ┌──────────────────────────┐ │   ║
║  │  │ Sensor Task  │  │ Comms Task   │  │ Maintenance Task         │ │   ║
║  │  │ (high pri)   │  │ (med pri)    │  │ (low priority)          │ │   ║
║  │  │ Period: 5-30s│  │ Event-driven │  │ Period: 6h              │ │   ║
║  │  └──────┬───────┘  └──────┬───────┘  └──────────┬───────────────┘ │   ║
║  │         │                 │                      │                 │   ║
║  │  ┌──────▼───────┐  ┌─────▼────────┐  ┌──────────▼──────────────┐ │   ║
║  │  │Data Pipeline │  │Channel Router│  │ OTA Update Manager      │ │   ║
║  │  │ Calibrate    │  │ Priority:    │  │ Check → Download →      │ │   ║
║  │  │ Filter       │  │ WiFi>LoRa>BLE│  │ Verify → Flash →       │ │   ║
║  │  │ Validate     │  │              │  │ Reboot → Validate       │ │   ║
║  │  │ Package      │  │              │  │                         │ │   ║
║  │  └──────┬───────┘  └──────┬───────┘  └─────────────────────────┘ │   ║
║  │         │                 │                                       │   ║
║  │  ┌──────▼───────┐  ┌─────▼────────┐                              │   ║
║  │  │Alert Engine  │  │Power Manager │                               │   ║
║  │  │ Threshold    │  │ Active       │                               │   ║
║  │  │ monitoring   │  │ Sleep (WFI)  │                               │   ║
║  │  │              │  │ Stop         │                               │   ║
║  │  │              │  │ Standby      │                               │   ║
║  │  └──────────────┘  └──────────────┘                               │   ║
║  └───────────────────────────────────────────────────────────────────┘   ║
║                                                                           ║
╠═══════════════════════════════════════════════════════════════════════════╣
║                                                                           ║
║  LAYER 3: COMMUNICATION                                                   ║
║  ┌──────────┐ ┌──────────┐ ┌──────────┐ ┌──────────┐ ┌──────────────┐   ║
║  │  WiFi    │ │  BLE     │ │  LoRa    │ │  UART    │ │  Protocols   │   ║
║  │  Manager │ │  GATT    │ │  Radio   │ │  Console │ │              │   ║
║  │          │ │  Server  │ │  SX1276  │ │          │ │  ┌────────┐  │   ║
║  │ ┌──────┐ │ │          │ │          │ │ ┌──────┐ │ │  │  MQTT  │  │   ║
║  │ │Reconnect││ │ ┌──────┐ │ │ ┌──────┐ │ │ │Parser│ │ │  │Client │  │   ║
║  │ │Logic │ │ │ │Advert │ │ │ │Packet│ │ │ │Cmd  │ │ │  │        │  │   ║
║  │ └──────┘ │ │ │Engine │ │ │ │Codec │ │ │ │Exec │ │ │  ├────────┤  │   ║
║  │          │ │ └──────┘ │ │ └──────┘ │ │ └──────┘ │ │  │  HTTP  │  │   ║
║  │ ┌──────┐ │ │          │ │          │ │          │ │  │Server  │  │   ║
║  │ │NTP   │ │ │ ┌──────┐ │ │ ┌──────┐ │ │          │ │  │REST API│  │   ║
║  │ │Sync  │ │ │ │Pairing│ │ │ │LoRaWAN│ │ │          │ │  │        │  │   ║
║  │ └──────┘ │ │ └──────┘ │ │ │Stack │ │ │          │ │  └────────┘  │   ║
║  └──────────┘ └──────────┘ │ └──────┘ │ └──────────┘ └──────────────┘   ║
║                             └──────────┘                                  ║
║                                                                           ║
╠═══════════════════════════════════════════════════════════════════════════╣
║                                                                           ║
║  LAYER 2: DRIVERS                                                         ║
║  ┌────────────┐ ┌────────────┐ ┌────────────┐ ┌──────────┐ ┌──────────┐ ║
║  │  BME280    │ │  AS5600    │ │ Anemometer │ │ Rain     │ │ SI1145   │ ║
║  │  Driver    │ │  Driver    │ │ Driver     │ │ Gauge    │ │ Driver   │ ║
║  │            │ │            │ │            │ │ Driver   │ │          │ ║
║  │ read_temp()│ │ read_angle │ │ get_speed()│ │          │ │ read_uv()│ ║
║  │ read_hum() │ │ ()         │ │            │ │get_rain()│ │          │ ║
║  │ read_pres()│ │            │ │  ┌──────┐  │ │          │ │          │ ║
║  │            │ │  ┌──────┐  │ │  │Pulse │  │ │ ┌──────┐ │ │          │ ║
║  │  ┌──────┐  │ │  │Magnet│  │ │  │Count │  │ │ │Tip   │ │ │          │ ║
║  │  │Calib │  │ │  │Offset│  │ │  │ISR   │  │ │ │Count │ │ │          │ ║
║  │  └──────┘  │ │  └──────┘  │ │  └──────┘  │ │ │ISR   │ │ │          │ ║
║  └────────────┘ └────────────┘ └────────────┘ │ └──────┘ │ └──────────┘ ║
║                                                └──────────┘              ║
║  ┌────────────┐                                                          ║
║  │  BH1750    │                                                          ║
║  │  Driver    │                                                          ║
║  │ read_lux() │                                                          ║
║  └────────────┘                                                          ║
║                                                                           ║
╠═══════════════════════════════════════════════════════════════════════════╣
║                                                                           ║
║  LAYER 1: HAL (stm32f4xx-hal)                                             ║
║  ┌────────┐ ┌────────┐ ┌────────┐ ┌────────┐ ┌────────┐ ┌────────────┐ ║
║  │  I2C   │ │  SPI   │ │  ADC   │ │  GPIO  │ │  UART  │ │  Timers    │ ║
║  │ Master │ │ Master │ │ 12-bit │ │ In/Out │ │ Serial │ │  HW Timer  │ ║
║  │ 400kHz │ │ 10MHz  │ │ SAR    │ │ IRQ    │ │ 115200 │ │  Watchdog  │ ║
║  └────────┘ └────────┘ └────────┘ └────────┘ └────────┘ │  RTC       │ ║
║                                                          └────────────┘ ║
║                                                                           ║
╠═══════════════════════════════════════════════════════════════════════════╣
║                                                                           ║
║  LAYER 0: HARDWARE                                                        ║
║  ┌───────────────────────────────────────────────────────────────────────┐ ║
║  │  STM32F407VGT6 — ARM Cortex-M4F @ 168 MHz (Industrial -40/+105°C)    │ ║
║  │  192 KB SRAM (128 KB + 64 KB CCM) · 1 MB Flash                      │ ║
║  │  ATWINC1500 WiFi (SPI3) · RN4870 BLE (USART3)                       │ ║
║  │  W5500 Ethernet + SD Card (SPI2, optional) · SIM7600 (UART4, opt)  │ ║
║  │  82 GPIO · 16 ADC channels · 3 I2C · 3 SPI · 4 UART                │ ║
║  └───────────────────────────────────────────────────────────────────────┘ ║
║                                                                           ║
╚═══════════════════════════════════════════════════════════════════════════╝
```

## Memory Layout

```
Flash (1 MB) — STM32F407VGT6
┌───────────────────────┐ 0x08000000
│ Sector 0-3 (64 KB)    │  ← Firmware (active)
├───────────────────────┤ 0x08010000
│ Sector 4 (64 KB)      │  ← Data storage (circular buffer)
├───────────────────────┤ 0x08020000
│ Sectors 5-7 (384 KB)  │  ← Firmware continued
├───────────────────────┤ 0x08080000
│ Sectors 8-11 (512 KB) │  ← OTA staging (bank 2)
└───────────────────────┘ 0x08100000

SRAM (192 KB)
┌───────────────────────┐ 0x20000000
│ Stack (8 KB)          │
├───────────────────────┤
│ Heap (48 KB)          │
│  ├─ Ring Buffers      │
│  ├─ MQTT buffers      │
│  ├─ HTTP buffers      │
│  └─ Driver state      │
├───────────────────────┤
│ Static Data (~16 KB)  │
│  ├─ Config            │
│  ├─ Current readings  │
│  └─ Sensor state      │
├───────────────────────┤ 0x20020000
│ CCM RAM (64 KB)       │  ← DMA-inaccessible, stack/scratch
└───────────────────────┘ 0x20030000
```

## Interrupt Priority Map

```
Priority 1 (Highest): Watchdog Timer
Priority 2:           GPIO ISR (wind pulse, rain tip)
Priority 3:           SPI DMA complete (LoRa)
Priority 4:           I2C transaction complete
Priority 5:           UART RX
Priority 6 (Lowest):  Software timer callbacks
```

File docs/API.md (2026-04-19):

# API Reference

## 1. MQTT Topics

### 1.1 Telemetry (Publish)

**Topic**: `weather/{device_id}/telemetry`
**QoS**: 1
**Interval**: Configurable (default 30 s)

```json
{
  "timestamp": "2026-02-26T14:30:00Z",
  "temperature_c": 23.5,
  "humidity_pct": 65.2,
  "pressure_hpa": 1013.25,
  "wind_speed_kmh": 12.3,
  "wind_direction_deg": 225,
  "rain_mm_hour": 0.4,
  "rain_mm_total": 12.6,
  "uv_index": 3.2,
  "light_lux": 45000,
  "heat_index_c": 24.1,
  "dew_point_c": 16.8,
  "wind_chill_c": null
}
```

### 1.2 Status (Publish)

**Topic**: `weather/{device_id}/status`
**QoS**: 1
**Interval**: 60 s

```json
{
  "timestamp": "2026-02-26T14:30:00Z",
  "uptime_s": 86400,
  "battery_v": 3.85,
  "battery_pct": 72,
  "wifi_rssi_dbm": -45,
  "free_heap_bytes": 180000,
  "flash_used_pct": 34,
  "firmware_version": "1.0.0",
  "sensor_status": {
    "bme280": "ok",
    "wind": "ok",
    "rain": "ok",
    "uv": "ok",
    "light": "degraded"
  }
}
```

### 1.3 Alerts (Publish)

**Topic**: `weather/{device_id}/alerts`
**QoS**: 2

```json
{
  "timestamp": "2026-02-26T14:30:00Z",
  "alert_type": "threshold_exceeded",
  "sensor": "wind_speed",
  "value": 95.2,
  "threshold": 90.0,
  "unit": "km/h",
  "message": "High wind speed alert"
}
```

### 1.4 Commands (Subscribe)

**Topic**: `weather/{device_id}/cmd`
**QoS**: 1

```json
{
  "command": "set_interval",
  "params": {
    "telemetry_interval_s": 15
  }
}
```

Supported commands:
| Command | Description |
|---|---|
| `set_interval` | Change telemetry interval |
| `reboot` | Restart device |
| `calibrate` | Trigger sensor calibration |
| `status` | Request immediate status report |
| `sleep` | Enter deep sleep for N seconds |
| `factory_reset` | Erase NVS and reboot |

## 2. HTTP REST API

### 2.1 GET /api/v1/current

Returns the latest sensor readings.

**Response** (200):
```json
{
  "timestamp": "2026-02-26T14:30:00Z",
  "temperature_c": 23.5,
  "humidity_pct": 65.2,
  "pressure_hpa": 1013.25,
  "wind_speed_kmh": 12.3,
  "wind_direction_deg": 225,
  "rain_mm_hour": 0.4,
  "rain_mm_total": 12.6,
  "uv_index": 3.2,
  "light_lux": 45000
}
```

### 2.2 GET /api/v1/history

Returns historical readings.

**Query params**:
- `hours` (optional, default=1): Number of hours of history
- `resolution` (optional, default=auto): `raw`, `1min`, `5min`, `15min`, `1hour`

**Response** (200):
```json
{
  "from": "2026-02-26T13:30:00Z",
  "to": "2026-02-26T14:30:00Z",
  "resolution": "5min",
  "count": 12,
  "readings": [ ... ]
}
```

### 2.3 GET /api/v1/status

Returns device status.

### 2.4 POST /api/v1/config

Update device configuration.

**Request body**:
```json
{
  "telemetry_interval_s": 15,
  "mqtt_broker": "mqtt.example.com",
  "mqtt_port": 8883,
  "alerts": {
    "wind_speed_kmh": 90.0,
    "temperature_high_c": 40.0,
    "temperature_low_c": -10.0
  }
}
```

### 2.5 POST /api/v1/ota

Upload firmware binary for OTA update.

**Content-Type**: `application/octet-stream`
**Header**: `X-Firmware-SHA256: <hex digest>`

**Response** (202):
```json
{
  "status": "accepted",
  "message": "Firmware update in progress, device will reboot"
}
```

### 2.6 GET /

Minimal HTML status page showing current readings and device info.

## 3. BLE GATT Profile

### 3.1 Environmental Sensing Service (UUID: 0x181A)

| Characteristic | UUID | Type | Properties |
|---|---|---|---|
| Temperature | 0x2A6E | sint16 (0.01°C) | Read, Notify |
| Humidity | 0x2A6F | uint16 (0.01%) | Read, Notify |
| Pressure | 0x2A6D | uint32 (0.1 Pa) | Read, Notify |

### 3.2 Custom Weather Service (UUID: 0000FFE0-0000-1000-8000-00805F9B34FB)

| Characteristic | UUID | Type | Properties |
|---|---|---|---|
| Wind Speed | FFE0-0001 | uint16 (0.1 km/h) | Read, Notify |
| Wind Direction | FFE0-0002 | uint16 (degrees) | Read, Notify |
| Rain Accum | FFE0-0003 | uint16 (0.1 mm) | Read, Notify |
| UV Index | FFE0-0004 | uint16 (0.1) | Read, Notify |
| Light Level | FFE0-0005 | uint32 (lux) | Read, Notify |
| All Readings | FFE0-00FF | JSON blob | Read, Notify |

### 3.3 Configuration Service (UUID: 0000FFE1-0000-1000-8000-00805F9B34FB)

| Characteristic | UUID | Type | Properties |
|---|---|---|---|
| Sampling Rate | FFE1-0001 | uint16 (seconds) | Read, Write |
| WiFi SSID | FFE1-0010 | UTF-8 string | Write |
| WiFi Password | FFE1-0011 | UTF-8 string | Write |
| Device Name | FFE1-0020 | UTF-8 string | Read, Write |
| WiFi Status | FFE1-0030 | uint8 (enum) | Read, Notify |

## 4. UART Console Commands

Baud: 115200, 8N1

| Command | Description | Example |
|---|---|---|
| `status` | Print device status | `> status` |
| `reading` | Print latest readings | `> reading` |
| `config get <key>` | Read config value | `> config get interval` |
| `config set <key> <val>` | Write config value | `> config set interval 15` |
| `calibrate <sensor>` | Run calibration | `> calibrate bme280` |
| `reset` | Soft reset | `> reset` |
| `factory-reset` | Erase NVS + reset | `> factory-reset` |
| `dump <sensor> <count>` | Raw data dump | `> dump bme280 100` |
| `lora send <msg>` | Manual LoRa transmit | `> lora send test` |
| `wifi scan` | Scan WiFi networks | `> wifi scan` |
| `help` | Show command list | `> help` |

## 5. LoRa Packet Format

Compact binary format to minimize airtime:

```
Byte 0:     Packet type (0x01 = telemetry)
Byte 1-2:   Device ID (uint16)
Byte 3-6:   Timestamp (uint32, epoch seconds)
Byte 7-8:   Temperature (int16, ×100 °C)
Byte 9-10:  Humidity (uint16, ×100 %)
Byte 11-14: Pressure (uint32, ×100 Pa)
Byte 15-16: Wind speed (uint16, ×10 km/h)
Byte 17-18: Wind direction (uint16, degrees)
Byte 19-20: Rain total (uint16, ×10 mm)
Byte 21:    UV index (uint8, ×10)
Byte 22-23: Light (uint16, lux, capped 65535)
Byte 24:    Battery % (uint8)
Byte 25-26: CRC16
Total: 27 bytes
```

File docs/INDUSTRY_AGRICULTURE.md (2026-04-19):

# Agriculture Industry Module

## Overview

The agriculture module extends the base weather station with crop-focused
sensors and analytics for precision farming. Enabled with `--features agriculture`.

```bash
cargo build --release --features agriculture
```

## Additional Sensors

| # | Component | Part Number | Interface | Purpose |
|---|---|---|---|---|
| 1 | Capacitive soil moisture (shallow) | v2.0 | ADC (GPIO7) | Root zone moisture (10–15 cm) |
| 2 | Capacitive soil moisture (deep) | v2.0 | ADC (GPIO18) | Root zone moisture (30–40 cm) |
| 3 | DS18B20 waterproof probe | DS18B20 | 1-Wire (GPIO16) | Soil temperature |
| 4 | Leaf wetness sensor | SEN-LWS | ADC (GPIO17) | Surface moisture detection |

### Pin Mapping (Agriculture Extension)

```
STM32F407 Additional Pins (Agriculture)
═══════════════════════════════════════════════════════════

ADC (Soil Moisture):
  PC2 (ADC1_CH12) ──── Soil Moisture Shallow (capacitive)
  PC3 (ADC1_CH13) ──── Soil Moisture Deep (capacitive)

1-Wire (Soil Temperature):
  GPIO 16 ──── DATA ──── DS18B20 (4.7kΩ pull-up to 3.3V)

ADC (Leaf Wetness):
  GPIO 17 ──── ADC ──── Leaf Wetness Sensor
```

### Circuit Diagram (Agriculture Extension)

```
         3.3V
          │
          ├──── 4.7kΩ ────┐
          │                │
          │         ┌──────┴──────┐
          ├────────►│ DS18B20     │
          │    VCC  │ Waterproof  │
          │         │ Probe       │
   GPIO16 ◄────────┤ DATA        │
          │         │ (1-Wire)    │
     GND ─┤────────►│ GND         │
          │         └─────────────┘
          │
          │     ┌─────────────────────┐
          ├────►│ Capacitive Soil     │
          │ VCC │ Moisture v2.0       │
   GPIO7  ◄────┤ AOUT (shallow)      │
     GND ─┤────►│ GND                │
          │     └─────────────────────┘
          │
          │     ┌─────────────────────┐
          ├────►│ Capacitive Soil     │
          │ VCC │ Moisture v2.0       │
   GPIO18 ◄────┤ AOUT (deep)         │
     GND ─┤────►│ GND                │
          │     └─────────────────────┘
          │
          │     ┌─────────────────────┐
          ├────►│ Leaf Wetness        │
          │ VCC │ Sensor (resistive)  │
   GPIO17 ◄────┤ AOUT                │
     GND ──────►│ GND                │
                └─────────────────────┘
```

## Analytics Features

### 1. Evapotranspiration (ET₀)

Reference evapotranspiration calculated using the FAO Penman-Monteith equation.
Falls back to Hargreaves-Samani when solar radiation data is unavailable.

**Inputs**: Air temperature, humidity, wind speed, solar radiation, pressure
**Output**: ET₀ in mm/day

```
MQTT topic: weather/{device_id}/agriculture
Field: "et0_mm_day"
```

### 2. Growing Degree Days (GDD)

Accumulated thermal units for crop phenology staging.

```
GDD_daily = max(0, (T_max + T_min) / 2 - T_base)
```

Supported crop base temperatures:
| Crop | T_base (°C) |
|---|---|
| Corn | 10.0 |
| Wheat | 0.0 |
| Rice | 10.0 |
| Soybean | 10.0 |
| Cotton | 15.6 |

Configurable via `gdd_base_temp_c` in RuntimeConfig or BLE.

### 3. Frost Alerts

Multi-level frost risk assessment considering temperature and humidity:

| Level | Condition | Action |
|---|---|---|
| **None** | T > 5°C | Normal operation |
| **Watch** | T approaching frost threshold | Advisory notification |
| **Warning** | T ≤ 2°C (adjusted for humidity) | MQTT + BLE alert |
| **Critical** | T ≤ 0°C | High-priority alert |

Low humidity (< 50%) increases radiative frost risk by adding a 1.5°C offset.

### 4. Irrigation Scheduling

Soil moisture-based irrigation recommendations:

```
┌─────────────────────────────────────────────────────────┐
│ Soil Moisture Profile                                   │
│                                                         │
│ 100% ─── Saturation ──────────────────────────────────  │
│  35% ─── Field Capacity ──── Irrigation Stop ────────  │
│  23% ─── Management Allowable Depletion ── Monitor ──  │
│  15% ─── Wilting Point ──── Irrigate Immediately ────  │
│   0% ─── Oven Dry ───────────────────────────────────  │
└─────────────────────────────────────────────────────────┘
```

| Status | Moisture Range | Recommendation |
|---|---|---|
| FieldCapacity | ≥ 35% | No irrigation needed |
| Adequate | 23–35% | Normal |
| MonitorClosely | 19–23% | Plan irrigation |
| IrrigateRecommended | 15–19% | Start irrigation |
| IrrigateCritical | ≤ 15% | Irrigate immediately |

### 5. Disease Risk Index

Smith period-based fungal disease prediction model (0–100 scale):

- **Temperature factor**: Bell curve centered at 20°C (10–30°C range)
- **Wetness factor**: Risk escalates after 6+ hours continuous leaf wetness
- Risk ≥ 80 triggers a warning alert

### 6. Spray Window Assessment

Evaluates suitability for pesticide/herbicide application:

| Condition | Assessment |
|---|---|
| Rain > 0.5 mm/hr | Poor |
| Wind > 20 km/h | Poor |
| Temp < 5°C + calm | Poor (inversion) |
| Wind 12–20 km/h | Marginal |
| Wind < 12 km/h, no rain | Good |

## MQTT Topics

```
weather/{device_id}/agriculture       — Agriculture sensor data + analytics (JSON)
weather/{device_id}/alerts/industry   — Frost, irrigation, disease alerts
```

### Agriculture Payload Example

```json
{
  "soil_moisture_shallow_pct": 28.5,
  "soil_moisture_deep_pct": 35.2,
  "soil_temp_c": 18.3,
  "leaf_wetness_pct": 45.0,
  "leaf_wet_duration_min": 120,
  "et0_mm_day": 4.2,
  "gdd_accumulated": 1250.5,
  "gdd_today": 12.3,
  "frost_risk": "None",
  "irrigation": "Adequate",
  "disease_risk_index": 25,
  "spray_window": "Good"
}
```

## Power Budget Addition

| Component | Active (mA) | Sleep (µA) |
|---|---|---|
| Soil moisture sensor ×2 | 8.0 | 0 (switched) |
| DS18B20 | 1.5 | 0.75 |
| Leaf wetness sensor | 0.2 | 0 (switched) |
| **Subtotal** | **~10 mA** | **~1 µA** |

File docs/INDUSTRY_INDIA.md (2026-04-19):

# India Regional Module

## Overview

The India module extends the base weather station with region-specific analytics
tailored to the Indian subcontinent. It provides IMD-aligned seasonal classification,
monsoon onset/withdrawal tracking, heat wave alerts using official IMD criteria,
tropical cyclone detection, NAQI-based air quality indexing, and IST timezone support
for daily aggregations. Enabled with `--features india`.

```bash
cargo build --release --features india
```

## Features

| Feature | Description |
|---|---|
| **Monsoon tracking** | Onset/break/withdrawal detection using consecutive rain-day analysis |
| **IMD season classification** | Winter, Pre-Monsoon, SW Monsoon, Post-Monsoon |
| **Heat wave alerts** | IMD criteria for plains, coastal, and hill regions |
| **Apparent temperature** | Steadman's feels-like temperature model |
| **Cyclone risk detection** | 3-hour pressure tendency + wind speed analysis |
| **NAQI air quality** | PM2.5-based National Air Quality Index (CPCB breakpoints) |
| **Indian crop GDD** | Rice, wheat, sugarcane, tea, jute base temperatures |
| **IST timezone** | UTC+05:30 day boundary for daily aggregations |
| **IN865 LoRa band** | 865–867 MHz ISM band compliance for India |

## Industrial-Grade Component Specifications

All components are selected for industrial temperature range (-40°C to +85°C)
and harsh outdoor deployment with IP65+ enclosure, conformal coating, and TVS
protection on all external I/O lines.

### Base Station Components

| # | Component | Industrial Part Number | Temp Range | Notes |
|---|---|---|---|---|
| 1 | MCU | ESP32-S3-WROOM-1-N16R8**I** | -40°C to +85°C | Industrial "I" suffix |
| 2 | Temp/Hum/Press | Bosch BME280 | -40°C to +85°C | Automotive-qualified avail. |
| 3 | Wind Direction | AS5600-ASOM | -40°C to +85°C | Industrial magnetic encoder |
| 4 | UV Sensor | SI1145-A10-GMR | -40°C to +85°C | UV/ALS/proximity |
| 5 | Light Sensor | BH1750FVI-TR | -40°C to +85°C | Ambient light sensor |
| 6 | LoRa Radio | Semtech SX1276 | -40°C to +85°C | ISM transceiver |
| 7 | Voltage Regulator | TPS63020DSJR | -40°C to +85°C | Wide-input buck-boost |
| 8 | TVS Protection | TPD4E05U06DQAR | -40°C to +125°C | All external I/O |
| 9 | Conformal Coating | Dow Corning 1-2577 | -65°C to +200°C | Salt-spray resistant |

### Enclosure & Environmental Protection

| Specification | Value |
|---|---|
| IP Rating | IP65 (minimum), IP67 recommended |
| Material | UV-stabilized polycarbonate |
| Mounting | Stainless steel 304 pole mount |
| Cable Glands | IP68 rated, M12 connectors |
| Lightning | MOV surge protector on antenna + power |
| Grounding | Dedicated earth lug, bonded to mast |
| Operating Temp | -40°C to +85°C (electronics) |
| Humidity | 0–100% RH (conformal coated) |

## Additional Sensors (India Extension)

| # | Component | Part Number | Interface | Purpose | Temp Range |
|---|---|---|---|---|---|
| 1 | PM2.5 particulate sensor | GP2Y1014AU0F | ADC (GPIO21) | Air quality monitoring | -10°C to +65°C |

### Pin Mapping (India Extension)

```
ESP32-S3 Additional Pins (India)
═══════════════════════════════════════════════════════════

ADC (Air Quality):
  GPIO 21 ──── ADC ──── PM2.5 Sensor (analog output)
```

### Circuit Diagram (India Extension)

```
         3.3V
          │
          ├──── 150Ω ────┐
          │               │
          │        ┌──────┴──────────┐
          ├───────►│ GP2Y1014AU0F   │
          │   VCC  │ PM2.5 Dust     │
          │        │ Sensor          │
   GPIO21 ◄───────┤ Vo (analog)     │
          │        │                 │
          │   LED ─┤ LED drive       │
     GND ─┤───────►│ GND            │
          │        └─────────────────┘
          │
          ├──── 220µF cap to GND (LED pulse smoothing)
```

### PM2.5 Driver — Industrial Features

The PM2.5 driver implements production-grade signal acquisition:

| Feature | Description |
|---|---|
| **LED pulse timing** | 320 µs pulse, ADC sample at 280 µs per GP2Y1014AU0F datasheet |
| **Multi-sample averaging** | 10 samples with trimmed-mean outlier rejection |
| **Warm-up enforcement** | 10-second minimum after power-on before readings accepted |
| **NaN/infinity guards** | All inputs and outputs validated for finite values |
| **Fault detection** | 5 consecutive out-of-range readings triggers sensor error |
| **EMA filtering** | Exponential moving average (α=0.2) for trend smoothing |
| **Calibration API** | Runtime-adjustable baseline and sensitivity from NVS |

## Analytics Features

### 1. IMD Season Classification

Automatic season detection based on month:

| Season | Months | Description |
|---|---|---|
| Winter | Jan–Feb | Cold, dry season |
| Pre-Monsoon | Mar–May | Hot, dry with thunderstorms |
| SW Monsoon | Jun–Sep | Primary rainy season |
| Post-Monsoon | Oct–Dec | Retreating monsoon, northeast winds |

### 2. Monsoon Tracking

Monitors rainfall patterns to detect monsoon lifecycle phases:

| Phase | Detection Criteria |
|---|---|
| **PreMonsoon** | Before onset (< 5 consecutive rain days in Jun–Sep) |
| **Active** | ≥ 5 consecutive days with rainfall ≥ 2.5 mm |
| **Break** | Dry spell after established onset |
| **Retreat** | October after active monsoon |
| **Off** | Outside monsoon season |

**Tracked metrics:**
- Consecutive rain days (threshold: 5 days at ≥ 2.5 mm/day)
- Accumulated monsoon rainfall (mm)
- Daily rainfall total (reset at IST midnight)

### 3. Heat Wave Alerts (IMD Criteria)

Region-specific thresholds per India Meteorological Department:

| Region | Heat Wave (°C) | Severe Heat Wave (°C) |
|---|---|---|
| Plains | ≥ 40.0 | ≥ 45.0 |
| Coastal | ≥ 37.0 | ≥ 41.0 |
| Hill | ≥ 30.0 | ≥ 34.0 |

Configurable via `india_region` in RuntimeConfig.

**Additional heat metrics:**
- **Apparent Temperature** — Steadman's model combining temperature, humidity, and wind
- **Discomfort Index** — Thom's DI for thermal comfort assessment

### 4. Tropical Cyclone Risk Detection

3-hour pressure tendency monitoring for early cyclone warning:

| Level | Pressure Drop (3h) | Wind Speed | Action |
|---|---|---|---|
| **None** | < 3 hPa | — | Normal |
| **Watch** | ≥ 3 hPa | Any | Advisory |
| **Warning** | ≥ 5 hPa | ≥ 60 km/h | MQTT + BLE alert |
| **Severe** | ≥ 8 hPa | ≥ 90 km/h | Critical alert |

Pressure is sampled every processing interval into an 18-slot circular buffer
covering a 3-hour window.

### 5. NAQI Air Quality Index

PM2.5-based NAQI calculation using CPCB (Central Pollution Control Board) breakpoints:

| Category | PM2.5 (µg/m³) | AQI Range |
|---|---|---|
| Good | 0–30 | 0–50 |
| Satisfactory | 31–60 | 51–100 |
| Moderate | 61–90 | 101–200 |
| Poor | 91–120 | 201–300 |
| Very Poor | 121–250 | 301–400 |
| Severe | 250+ | 401–500 |

AQI ≥ 401 (Severe) triggers a critical alert.

### 6. Indian Crop GDD

Growing Degree Day accumulation with Indian crop base temperatures:

| Crop | T_base (°C) |
|---|---|
| Rice (Kharif) | 10.0 |
| Wheat (Rabi) | 0.0 |
| Sugarcane | 12.0 |
| Tea | 7.0 |
| Jute | 15.0 |

Configurable via `india_gdd_base_temp_c` in RuntimeConfig.

### 7. IST Timezone Support

Daily aggregations (rainfall, GDD, min/max temperature) reset at IST midnight
(UTC+05:30) rather than UTC midnight, matching Indian agricultural and
meteorological conventions.

```
IST offset: +05:30 (19800000 ms from UTC)
```

### 8. LoRa IN865 Band

For LoRaWAN deployments in India, the module configures the IN865 ISM band:

| Parameter | Value |
|---|---|
| Frequency | 865.0625 MHz |
| Band | 865–867 MHz |
| Max EIRP | 36 dBm (per WPC India) |

## MQTT Topics

```
weather/{device_id}/india              — India regional data + analytics (JSON)
weather/{device_id}/alerts/industry    — Heat wave, cyclone, AQI, monsoon alerts
```

### India Payload Example

```json
{
  "season": "SouthwestMonsoon",
  "monsoon_phase": "Active",
  "consecutive_rain_days": 8,
  "monsoon_rainfall_mm": 342.5,
  "daily_rainfall_mm": 28.3,
  "heat_wave": "None",
  "apparent_temp_c": 34.2,
  "discomfort_index": 29.8,
  "cyclone_risk": "None",
  "pressure_tendency_3h_hpa": -0.5,
  "aqi_naqi": 156,
  "aqi_category": "Moderate",
  "gdd_accumulated": 850.0,
  "gdd_today": 15.2
}
```

### Alert Examples

```json
{
  "severity": "Critical",
  "category": "heat_wave",
  "message": "SEVERE HEAT WAVE: dangerous conditions, take precautions",
  "timestamp_ms": 1719500000000
}
```

```json
{
  "severity": "Warning",
  "category": "cyclone",
  "message": "Cyclone warning: rapid pressure drop with high winds",
  "timestamp_ms": 1719500000000
}
```

```json
{
  "severity": "Info",
  "category": "monsoon",
  "message": "Monsoon onset detected: sustained rainfall pattern identified",
  "timestamp_ms": 1719500000000
}
```

## Configuration

### Runtime Config Fields (NVS-persisted)

| Field | Type | Default | Description |
|---|---|---|---|
| `india_region` | IndiaRegion | Plains | Region type for heat wave thresholds |
| `india_gdd_base_temp_c` | f32 | 10.0 | GDD base temperature for crop |
| `india_crop_type` | String | "" | Crop name (for display) |

### Compile-time Constants

| Constant | Value | Description |
|---|---|---|
| `PM25_SENSOR_ADC_PIN` | GPIO 21 | PM2.5 sensor analog input |
| `INDIA_PROCESS_INTERVAL_MS` | 30,000 | Analytics processing interval |
| `IST_OFFSET_MS` | 19,800,000 | UTC+05:30 in milliseconds |
| `LORA_FREQUENCY_IN865_HZ` | 865,062,500 | IN865 LoRa center frequency |
| `INDIA_MONSOON_ONSET_RAIN_MM` | 2.5 | Min daily rainfall for rain-day |
| `INDIA_MONSOON_ONSET_DAYS` | 5 | Consecutive rain days for onset |

## Power Budget Addition

| Component | Active (mA) | Sleep (µA) |
|---|---|---|
| PM2.5 sensor (GP2Y1014AU0F) | 20.0 | 0 (switched) |
| **Subtotal** | **~20 mA** | **~0 µA** |

Note: The PM2.5 sensor is power-switched and only activated during sampling
(~10 ms per reading) to minimize average power consumption.

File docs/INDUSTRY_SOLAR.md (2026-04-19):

# Solar Energy Industry Module

## Overview

The solar module extends the base weather station with photovoltaic (PV)
performance monitoring and analytics. Enabled with `--features solar`.

```bash
cargo build --release --features solar
```

## Additional Sensors

| # | Component | Part Number | Interface | Purpose |
|---|---|---|---|---|
| 1 | Pyranometer / Solar sensor | ML8511 / SP-110 | ADC (GPIO7) | Global Horizontal Irradiance |
| 2 | DS18B20 (panel front) | DS18B20 | 1-Wire (GPIO16) | Panel front surface temperature |
| 3 | DS18B20 (panel back) | DS18B20 | 1-Wire (GPIO19) | Panel back-of-module temperature |
| 4 | Power meter (optional) | — | GPIO20 (pulse) | Grid-tie inverter output |

### Pin Mapping (Solar Extension)

```
STM32F407 Additional Pins (Solar)
═══════════════════════════════════════════════════════════

ADC (Pyranometer):
  PC2 (ADC1_CH12) ──── ML8511 / SP-110 Analog Output

1-Wire (Panel Temperature):
  GPIO 16 ──── DATA ──── DS18B20 #1 (panel front, 4.7kΩ pull-up)
  GPIO 19 ──── DATA ──── DS18B20 #2 (panel back, 4.7kΩ pull-up)

GPIO (Power Meter):
  GPIO 20 ──── PULSE ── Inverter kWh meter (10kΩ pull-up)
```

### Circuit Diagram (Solar Extension)

```
         3.3V
          │
          │     ┌─────────────────────┐
          ├────►│ ML8511 / SP-110     │
          │ VCC │ Pyranometer         │
   GPIO7  ◄────┤ OUT (analog)        │
          │     │ EN ─── 3.3V         │
     GND ─┤────►│ GND                │
          │     └─────────────────────┘
          │
          ├──── 4.7kΩ ────┐
          │                │
          │         ┌──────┴──────┐
          ├────────►│ DS18B20 #1  │
          │    VCC  │ Panel Front │
   GPIO16 ◄────────┤ DATA        │
     GND ─┤────────►│ GND         │
          │         └─────────────┘
          │
          ├──── 4.7kΩ ────┐
          │                │
          │         ┌──────┴──────┐
          ├────────►│ DS18B20 #2  │
          │    VCC  │ Panel Back  │
   GPIO19 ◄────────┤ DATA        │
     GND ─┤────────►│ GND         │
          │         └─────────────┘
          │
          ├──── 10kΩ ─────┐
          │                │
   GPIO20 ◄────────────────┤
          │         ┌──────┴──────┐
          │         │ kWh Meter   │
          │         │ Pulse Out   │
     GND ─┤────────►│ COM         │
          │         └─────────────┘
          │
```

### Pyranometer Mounting

```
         ☀️ Sun
          │
          │   ┌─────────────────┐
          │   │  ML8511 Sensor  │  ← Mount level, facing sky
          │   │  (upward facing)│     No shadows 360°
          │   └────────┬────────┘     Height: above panel plane
                       │
                 Mounting pole
```

## Analytics Features

### 1. Solar Irradiance Tracking

Global Horizontal Irradiance (GHI) measured by pyranometer:

```
ADC → Voltage (mV) → Irradiance (W/m²)

  voltage_mv = (raw / 4095) × 3300
  delta_mv   = voltage_mv - baseline_mv
  irradiance = (delta_mv / cal_mv_per_unit) × 10  [W/m²]
```

Range: 0–1500 W/m², EMA filtered (α = 0.5).

### 2. Temperature Derating

Panel power output decreases as panel temperature exceeds STC (25°C):

```
derating = 1.0 - (T_panel - 25°C) × |temp_coeff| / 100

Default temp_coeff: -0.35 %/°C (typical crystalline silicon)
```

| Panel Temp | Derating Factor | Power Loss |
|---|---|---|
| 25°C (STC) | 1.000 | 0% |
| 35°C | 0.965 | 3.5% |
| 45°C | 0.930 | 7.0% |
| 55°C | 0.895 | 10.5% |
| 65°C | 0.860 | 14.0% |
| 75°C | 0.825 | 17.5% |

### 3. Estimated Power Output

```
P_est = P_rated × (GHI / 1000) × derating × (1 - soiling%) × η_inverter
```

Where:
- `P_rated`: Panel nameplate watts-peak (configurable)
- `GHI`: Current irradiance in W/m²
- `derating`: Temperature derating factor
- `soiling%`: Estimated dust/dirt loss
- `η_inverter`: Inverter efficiency (default 0.96)

### 4. Daily Energy Yield

Integrated power over time:

```
E_daily = Σ(P_est × Δt)  [Wh]
```

Accumulated every sample interval and reported via MQTT.

### 5. Peak Sun Hours (PSH)

Equivalent hours of 1000 W/m² irradiance:

```
PSH = Σ(GHI / 1000 × Δt)  [hours]
```

Typical values: 3–7 PSH/day depending on location and season.

### 6. Performance Ratio

Ratio of actual output to theoretical maximum:

```
PR = P_actual / (P_rated × GHI / 1000)
```

| PR Range | Interpretation |
|---|---|
| 0.80–0.90 | Excellent (new/clean system) |
| 0.70–0.80 | Good (normal operation) |
| 0.50–0.70 | Degraded (investigate) |
| < 0.50 | Poor (shading/fault/soiling) |

### 7. Soiling Loss Estimation

Dust accumulation model based on days since last rain:

```
soiling_loss_pct = min(days_since_rain × 0.1%, 3.0%)
```

Rain > 1 mm/hr resets the counter (natural panel washing).

### 8. Cloud Transient Detection

Detects rapid irradiance changes (> 200 W/m² between samples) caused by
passing clouds. Logged for grid stability analysis.

### 9. Sky Condition Classification

| Irradiance | Classification |
|---|---|
| < 10 W/m² | Night |
| 10–200 W/m² | Overcast |
| 200–600 W/m² | Partly Cloudy |
| > 600 W/m² | Clear |

## MQTT Topics

```
weather/{device_id}/solar          — Real-time solar analytics (JSON)
weather/{device_id}/solar/daily    — Daily summary report (JSON)
weather/{device_id}/alerts/industry — Panel temp, performance, soiling alerts
```

### Solar Payload Example

```json
{
  "irradiance_w_m2": 850.0,
  "panel_temp_front_c": 42.5,
  "panel_temp_back_c": 38.2,
  "estimated_power_w": 312.8,
  "daily_yield_wh": 1850.5,
  "peak_sun_hours": 3.2,
  "temp_derating_factor": 0.939,
  "soiling_loss_pct": 0.5,
  "performance_ratio": 0.82,
  "sky_condition": "Clear",
  "inverter_efficiency": 0.96
}
```

### Daily Summary Payload

```json
{
  "total_yield_wh": 2850.0,
  "peak_power_w": 380.5,
  "peak_irradiance_w_m2": 1050.0,
  "peak_sun_hours": 5.2,
  "avg_performance_ratio": 0.78,
  "max_panel_temp_c": 55.3,
  "temp_loss_wh": 285.0,
  "soiling_loss_wh": 14.2,
  "cloud_transients": 12
}
```

## Alerts

| Alert | Severity | Condition |
|---|---|---|
| Panel overheating | Warning | Panel temp > 75°C |
| Low performance | Warning | PR < 0.5 at GHI > 200 W/m² |
| Soiling | Info | Estimated loss > 2% |

## Power Budget Addition

| Component | Active (mA) | Sleep (µA) |
|---|---|---|
| ML8511 pyranometer | 0.3 | 0.1 |
| DS18B20 ×2 | 3.0 | 1.5 |
| Pulse counter | 0.01 | 0 |
| **Subtotal** | **~3.3 mA** | **~1.6 µA** |

## Installation Notes

- Mount pyranometer horizontally with unobstructed sky view (no shadows)
- DS18B20 probes: adhere front probe to panel glass, back probe behind backsheet
- Use weatherproof cable glands for all sensor wiring
- Keep ESP32-S3 module shaded (avoid self-heating from direct sun)
- For multi-string systems, deploy one weather station per orientation/tilt group

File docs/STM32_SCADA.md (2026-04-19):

# STM32F407 + SCADA/Cloud/Hybrid Operating Modes

## Overview

The weather station uses a single-MCU architecture with the **STM32F407VGT6**
handling all sensor acquisition, SCADA (Modbus RS485), and cloud connectivity
via external modules: ATWINC1500 (WiFi), RN4870 (BLE), W5500 (Ethernet),
SIM7600E-H (Cellular).

```bash
# SCADA + all industry modules
cargo build --release --features all-industries

# Full system (all features + all comms)
cargo build --release --features full-system
```

## Architecture

```
┌─────────────────────────────────────────────────────────────────────┐
│                    STM32F407VGT6 (Single MCU)                       │
│              ARM Cortex-M4F @ 168 MHz, -40/+105°C                   │
│              1 MB Flash / 192 KB SRAM / Hardware FPU                │
├─────────────────────────────────────────────────────────────────────┤
│ SPI1 ─── SX1276 LoRa (PA4-PA7, PC4, PC5)                           │
│ SPI2 ─── W5500 Ethernet + SD Card (PB12-PB15, PD3/PD4, PD10/PD11) │
│ SPI3 ─── ATWINC1500 WiFi (PB3-PB5, PE3-PE6)                        │
│ USART2 ── MAX3485 RS485 Modbus (PA2, PA3, PA1)                     │
│ USART3 ── RN4870 BLE (PB10, PB11, PD8, PD9)                       │
│ UART4 ── SIM7600E-H Cellular (PC10, PC11) [optional]               │
│ USART1 ── Debug Console (PA9, PA10)                                 │
│ I2C1 ─── Sensors: BME280, AS5600, SI1145, BH1750 (PB6, PB7)       │
└─────────┬───────────────────────────────────────────────────────────┘
          │
          │ USART2 (RS485)
          │
    ┌─────┴─────┐         ┌───────────────┐
    │  MAX3485   │─── A ───┤               │
    │  RS485     │─── B ───┤  SCADA / PLC  │
    │  Xcvr      │─── GND ─┤  Master       │
    └───────────┘         └───────────────┘
```

## Operating Modes

Three operating modes selectable via DIP switch or software configuration:

| Mode | DIP (PE1:PE0) | Cloud (MQTT/HTTP) | SCADA (Modbus RS485) | Use Case |
|---|:---:|:---:|:---:|---|
| **Cloud** | 0:0 | Yes | — | Standard IoT deployment |
| **SCADA** | 0:1 | — | Yes | Air-gapped industrial |
| **Hybrid** | 1:0 | Yes | Yes | Full capability |

### Cloud Mode
- ATWINC1500 handles WiFi, MQTT, HTTP connectivity
- RN4870 provides BLE for mobile app configuration
- LoRa available for long-range backup
- Standard IoT deployment

### SCADA Mode
- Modbus RTU slave on RS485 bus
- All weather data exposed as Modbus registers
- No internet/cloud connectivity — fully air-gapped
- Ideal for integration with existing SCADA/PLC systems
- Up to 32 devices on single RS485 bus

### Hybrid Mode (Default)
- Both cloud and SCADA active simultaneously
- ATWINC1500/W5500 publishes to MQTT/HTTP
- Modbus RTU responds to SCADA master queries
- Maximum observability and integration flexibility

## Modbus Register Map

### Input Registers (Read-Only, FC 0x04)

| Address | Description | Unit | Scale |
|---|---|---|---|
| 30001 | Temperature | °C × 100 | i16 |
| 30002 | Humidity | % × 100 | u16 |
| 30003 | Pressure (high) | hPa × 100 | u32 |
| 30004 | Pressure (low) | | |
| 30005 | Wind Speed | km/h × 100 | u16 |
| 30006 | Wind Direction | degrees | u16 |
| 30007 | Rain Rate | mm/h × 100 | u16 |
| 30008 | Rain Accumulation | mm × 100 | u16 |
| 30009 | UV Index | index × 100 | u16 |
| 30010 | Light (high) | lux | u32 |
| 30011 | Light (low) | | |
| 30012 | Heat Index | °C × 100 | i16 |
| 30013 | Dew Point | °C × 100 | i16 |
| 30014 | Wind Chill | °C × 100 | i16 |
| 30015 | Battery Voltage | mV | u16 |
| 30016 | Battery Percentage | % | u16 |
| 30017 | PM2.5 (India) | µg/m³ × 10 | u16 |
| 30018 | AQI NAQI (India) | index | u16 |
| 30019 | Soil Moisture Shallow | % × 100 | u16 |
| 30020 | Soil Moisture Deep | % × 100 | u16 |
| 30021 | Soil Temperature | °C × 100 | i16 |
| 30022 | Solar Irradiance | W/m² × 10 | u16 |
| 30023 | Panel Temperature | °C × 100 | i16 |
| 30024 | Est. Solar Power | W × 10 | u16 |

### Holding Registers (R/W, FC 0x03/0x06/0x10)

| Address | Description | Range | Default |
|---|---|---|---|
| 40001 | Slave Address | 1–247 | 1 |
| 40002 | Baud Rate Code | 0=2400, 1=9600, 2=19200, 3=38400 | 1 |
| 40003 | Sensor Read Interval | 1–3600 s | 10 |
| 40004 | Operating Mode | 0=Cloud, 1=SCADA, 2=Hybrid | 2 |
| 40005 | Temp Cal Offset | °C × 100 | 0 |
| 40006 | Humidity Cal Offset | % × 100 | 0 |
| 40007 | Pressure Cal Offset | hPa × 100 | 0 |
| 40008 | GDD Base Temp | °C × 100 | 1000 |
| 40009 | India Region | 0=Plains, 1=Coastal, 2=Hill | 0 |
| 40010 | Device ID | 0–65535 | 1 |

### Discrete Inputs (Read-Only, FC 0x02)

| Address | Description |
|---|---|
| 10001 | Heat Wave Active |
| 10002 | Severe Heat Wave |
| 10003 | Cyclone Watch |
| 10004 | Cyclone Warning |
| 10005 | Cyclone Severe |
| 10006 | AQI Severe |
| 10007 | Frost Warning |
| 10008 | Sensor Fault |

## STM32F407 Pin Assignment

| Pin | Function | Connected To |
|-----|---|---|
| PB6 | I2C1_SCL | BME280, AS5600, SI1145, BH1750 |
| PB7 | I2C1_SDA | (shared bus) |
| PA5 | SPI1_SCK | SX1276 LoRa |
| PA6 | SPI1_MISO | SX1276 LoRa |
| PA7 | SPI1_MOSI | SX1276 LoRa |
| PA4 | SPI1_NSS | SX1276 CS |
| PC4 | GPIO | SX1276 RST |
| PC5 | GPIO (EXTI) | SX1276 DIO0 |
| PA2 | USART2_TX | MAX3485 DI |
| PA3 | USART2_RX | MAX3485 RO |
| PA1 | GPIO | MAX3485 DE/RE |
| PA9 | USART1_TX | Debug header |
| PA10 | USART1_RX | Debug header |
| PB10 | USART3_TX | RN4870 RX |
| PB11 | USART3_RX | RN4870 TX |
| PA0 | ADC1_CH0 | Battery divider |
| PC1 | ADC1_CH11 | PM2.5 sensor |
| PB0 | TIM3_CH3 | Wind speed pulse |
| PB1 | TIM3_CH4 | Rain gauge pulse |
| PE0 | GPIO (input) | Mode DIP bit 0 |
| PE1 | GPIO (input) | Mode DIP bit 1 |
| PD0 | GPIO (output) | Status LED (green) |
| PD1 | GPIO (output) | Error LED (red) |
| PD2 | GPIO (output) | SCADA LED (amber) |
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

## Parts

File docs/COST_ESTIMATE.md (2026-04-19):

# Weather Station — Comprehensive Cost Estimate

> **Date**: 2026-02-28 | **Rev**: 1.0 | **Currency**: USD
> **Basis**: Single unit prototype pricing. Volume discounts noted where applicable.

---

## 1. Electronic Components (Bill of Materials)

### 1.1 Microcontroller & Modules

| Ref | Component | Qty | Unit Price | Extended | Supplier |
|-----|---|-----|---|---|---|
| U1 | ESP32-S3-WROOM-1-N16R8I (Industrial) | 1 | $4.20 | $4.20 | Mouser |
| U8 | RFM95W-868S2 LoRa Module (SX1276) | 1 | $9.50 | $9.50 | Mouser |
| | **Subtotal — MCU & Modules** | | | **$13.70** | |

### 1.2 Sensors — Primary

| Ref | Component | Qty | Unit Price | Extended | Supplier |
|-----|---|-----|---|---|---|
| U4 | BME280 Temp/Humidity/Pressure | 1 | $3.50 | $3.50 | Mouser |
| U5 | AS5600-ASOM Magnetic Encoder (wind dir) | 1 | $2.80 | $2.80 | Mouser |
| U6 | SI1145-A10-GMR UV/IR/Vis Light | 1 | $3.20 | $3.20 | DigiKey |
| U7 | BH1750FVI-TR Ambient Light | 1 | $1.50 | $1.50 | Mouser |
| — | Anemometer SEN-15901 (wind speed) | 1 | $45.00 | $45.00 | SparkFun |
| — | Rain Gauge SEN-15902 (tipping bucket) | 1 | $25.00 | $25.00 | SparkFun |
| — | N52 Diametric Magnet 6mm (for AS5600) | 1 | $2.00 | $2.00 | Amazon |
| | **Subtotal — Primary Sensors** | | | **$83.00** | |

### 1.3 Sensors — Agriculture Module (Optional)

| Ref | Component | Qty | Unit Price | Extended | Supplier |
|-----|---|-----|---|---|---|
| — | Capacitive Soil Moisture Sensor v2.0 | 2 | $3.50 | $7.00 | Amazon |
| — | DS18B20 Waterproof Probe (soil temp) | 1 | $4.00 | $4.00 | Amazon |
| — | Leaf Wetness Sensor (resistive) | 1 | $8.00 | $8.00 | DigiKey |
| | **Subtotal — Agriculture Sensors** | | | **$19.00** | |

### 1.4 Sensors — Solar Module (Optional)

| Ref | Component | Qty | Unit Price | Extended | Supplier |
|-----|---|-----|---|---|---|
| — | ML8511 Pyranometer Breakout | 1 | $6.50 | $6.50 | SparkFun |
| — | DS18B20 Waterproof Probe (panel front) | 1 | $4.00 | $4.00 | Amazon |
| — | DS18B20 Waterproof Probe (panel back) | 1 | $4.00 | $4.00 | Amazon |
| — | S0 Pulse Power Meter Interface | 1 | $12.00 | $12.00 | — |
| | **Subtotal — Solar Sensors** | | | **$26.50** | |

### 1.5 Power Management ICs

| Ref | Component | Qty | Unit Price | Extended | Supplier |
|-----|---|-----|---|---|---|
| U2 | TP4056 LiPo Charger IC (SOIC-8) | 1 | $0.30 | $0.30 | LCSC |
| U2A | DW01A-G Battery Protection IC | 1 | $0.15 | $0.15 | LCSC |
| Q1 | FS8205A Dual MOSFET | 1 | $0.20 | $0.20 | LCSC |
| U3 | AMS1117-3.3 LDO Regulator | 1 | $0.25 | $0.25 | LCSC |
| F1 | MF-MSMF050-2 Polyfuse 500mA (1206) | 1 | $0.35 | $0.35 | Bourns |
| D1 | SS14 Schottky Diode (solar protection) | 1 | $0.15 | $0.15 | LCSC |
| D2 | SMAJ5.0A TVS Diode (USB ESD) | 1 | $0.30 | $0.30 | LCSC |
| | **Subtotal — Power ICs** | | | **$1.70** | |

### 1.6 Passive Components

| Ref | Component | Qty | Unit Price | Extended | Supplier |
|-----|---|-----|---|---|---|
| R1-R12 | Resistors, 0402, various values | 22 | $0.01 | $0.22 | LCSC |
| C1-C5 | Capacitors, 0402/0805, various | 16 | $0.02 | $0.32 | LCSC |
| D3-D6 | LEDs 0603 (Red/Green/Blue/Green) | 4 | $0.05 | $0.20 | LCSC |
| SW1-SW2 | PTS645 Tactile Buttons (6mm) | 2 | $0.20 | $0.40 | C&K |
| | **Subtotal — Passives** | | | **$1.14** | |

### 1.7 Connectors

| Ref | Component | Qty | Unit Price | Extended | Supplier |
|-----|---|-----|---|---|---|
| J1 | USB4105-GF-A USB-C Receptacle | 1 | $0.85 | $0.85 | DigiKey |
| J2-J3, J15 | JST B2B-PH-K-S 2-pin | 3 | $0.25 | $0.75 | JST |
| J4-J5 | RJ11 4P4C Amphenol 54601-908LF | 2 | $1.20 | $2.40 | Amphenol |
| J6 | SMA Female Edge Mount 132289 | 1 | $2.50 | $2.50 | Amphenol |
| J7 | Pin Header 1x04 2.54mm | 1 | $0.15 | $0.15 | Generic |
| J8-J11, J13-J14 | JST B3B-PH-K-S 3-pin | 6 | $0.30 | $1.80 | JST |
| J12 | JST B4B-PH-K-S 4-pin | 1 | $0.35 | $0.35 | JST |
| — | JST PH crimped wire harnesses (matching) | 12 | $1.00 | $12.00 | — |
| | **Subtotal — Connectors** | | | **$20.80** | |

### 1.8 Power Supply & Battery

| Component | Qty | Unit Price | Extended | Supplier |
|---|-----|---|---|---|
| 18650 LiPo Battery 3000mAh (protected cell) | 1 | $8.00 | $8.00 | Amazon |
| 18650 Battery Holder (PCB or wired) | 1 | $1.50 | $1.50 | Amazon |
| Solar Panel 6V 2W (110x136mm) | 1 | $6.00 | $6.00 | Amazon |
| USB-C Cable (1m, for programming/charging) | 1 | $3.00 | $3.00 | — |
| **Subtotal — Power** | | | **$18.50** | |

### 1.9 RF/Antenna

| Component | Qty | Unit Price | Extended | Supplier |
|---|-----|---|---|---|
| LoRa 868/915MHz Antenna (SMA, 3dBi) | 1 | $4.50 | $4.50 | Amazon |
| SMA Pigtail cable (if needed) | 1 | $2.00 | $2.00 | — |
| **Subtotal — Antenna** | | | **$6.50** | |

### BOM Cost Summary

| Category | Base Station | + Agriculture | + Solar | Full Build |
|---|---|---|---|---|
| MCU & Modules | $13.70 | $13.70 | $13.70 | $13.70 |
| Primary Sensors | $83.00 | $83.00 | $83.00 | $83.00 |
| Agriculture Sensors | — | $19.00 | — | $19.00 |
| Solar Sensors | — | — | $26.50 | $26.50 |
| Power ICs | $1.70 | $1.70 | $1.70 | $1.70 |
| Passives | $1.14 | $1.14 | $1.14 | $1.14 |
| Connectors | $20.80 | $20.80 | $20.80 | $20.80 |
| Power & Battery | $18.50 | $18.50 | $18.50 | $18.50 |
| Antenna/RF | $6.50 | $6.50 | $6.50 | $6.50 |
| **BOM Total** | **$145.34** | **$164.34** | **$171.84** | **$190.84** |

---

## 2. PCB Design & Fabrication

### 2.1 PCB Design (One-Time NRE)

| Item | Cost | Notes |
|---|---|---|
| Schematic capture (KiCad) | $0 | Done in-house (this project) |
| PCB layout (4-layer, impedance-controlled) | $0 | Done in-house (this project) |
| Design rule check (DRC) | $0 | KiCad automated |
| Gerber/drill file generation | $0 | KiCad export |
| **Subtotal — PCB Design** | **$0** | In-house, no external cost |

> **Note**: If outsourcing PCB layout to a professional designer:
> - 4-layer board, 100x80mm, ~54 components = **$300–$600** one-time
> - Impedance-controlled layout adds ~$100–$200

### 2.2 PCB Fabrication

| Parameter | Specification | Cost Impact |
|---|---|---|
| Board size | 100 x 80mm | — |
| Layers | 4 | Higher than 2-layer |
| Material | FR4 Tg170 | +$5 vs standard FR4 |
| Finish | ENIG | +$8 vs HASL |
| Impedance control | 50ohm + 90ohm | +$10 per order |
| Min trace/space | 0.15mm/0.15mm | Standard capability |

| Quantity | Per-Board Cost | Total | Supplier |
|---|---|---|---|
| 5 pcs (prototype) | $12.00 | $60.00 | JLCPCB |
| 10 pcs | $8.50 | $85.00 | JLCPCB |
| 50 pcs | $4.20 | $210.00 | JLCPCB |
| 100 pcs | $3.00 | $300.00 | JLCPCB/PCBWay |

### 2.3 Solder Stencil

| Item | Cost | Notes |
|---|---|---|
| Steel stencil (framed, 0.12mm) | $25.00 | Reusable for all boards |
| Frameless stencil | $8.00 | Budget option |

### 2.4 PCB Assembly (SMT)

| Option | Per-Board | Setup Fee | Notes |
|---|---|---|---|
| Hand assembly (DIY) | $0 | $0 | Requires hot air station + stencil |
| JLCPCB SMT Assembly (5 pcs) | $18.00 | $8.00 | Basic parts from LCSC stock |
| PCBWay Assembly (5 pcs) | $22.00 | $30.00 | Extended parts library |
| Professional PCBA (10+ pcs) | $15.00 | $50.00 | Full turnkey |

### PCB Cost Summary (Prototype — 5 boards)

| Item | Cost |
|---|---|
| PCB fabrication (5 pcs, 4-layer ENIG) | $60.00 |
| Solder stencil (framed) | $25.00 |
| SMT assembly (5 pcs, JLCPCB) | $98.00 |
| Shipping (DHL Express) | $25.00 |
| **PCB Total (5 prototypes)** | **$208.00** |
| **Per-board PCB cost** | **$41.60** |

---

## 3. Testing & Calibration

### 3.1 Test Equipment (One-Time Investment)

| Equipment | Cost | Notes |
|---|---|---|
| Digital multimeter (basic) | $30.00 | Voltage, current, continuity |
| USB-C power meter/tester | $15.00 | Verify charging current |
| Logic analyzer (8-ch, Saleae clone) | $12.00 | I2C/SPI/UART debugging |
| USB-UART adapter (CP2102/CH340) | $5.00 | Serial console access |
| Hot air rework station | $60.00 | SMD rework & repair |
| Soldering iron (Pinecil/TS100) | $45.00 | Fine-pitch hand soldering |
| **Subtotal — Test Equipment** | **$167.00** | One-time purchase |

> If already equipped, skip this section. These are basic maker/lab tools.

### 3.2 Calibration Reference Standards

| Item | Cost | Notes |
|---|---|---|
| NIST-traceable thermometer (±0.1°C) | $45.00 | Temperature reference |
| NIST-traceable hygrometer (±2% RH) | $65.00 | Humidity reference |
| Barometric reference (local airport METAR) | $0 | Free public data |
| UV reference meter | $85.00 | SI1145 calibration |
| Lux meter (calibrated) | $35.00 | BH1750 calibration |
| Anemometer reference (or lookup table) | $0 | Manufacturer-provided curve |
| **Subtotal — Calibration Standards** | **$230.00** | One-time purchase |

### 3.3 Per-Unit Testing & Calibration Labor

| Test Step | Time (min) | Cost @$25/hr | Notes |
|---|---|---|---|
| Visual inspection (AOI check) | 5 | $2.08 | Solder joints, components |
| Power-on test (3.3V rail, current) | 5 | $2.08 | USB-C power, LED check |
| Firmware flash (esptool) | 3 | $1.25 | Flash via USB-C |
| I2C sensor scan & verify | 5 | $2.08 | All 4 sensor addresses |
| Temperature calibration (3-point) | 30 | $12.50 | 0°C, 25°C, 50°C reference |
| Humidity calibration (2-point) | 20 | $8.33 | 33% and 75% salt solutions |
| Pressure calibration (1-point) | 5 | $2.08 | Compare to local METAR |
| Light sensor calibration | 10 | $4.17 | BH1750 + SI1145 vs reference |
| Wind sensor verification | 10 | $4.17 | Pulse counting, direction sweep |
| Rain gauge verification | 5 | $2.08 | Tip counter check |
| WiFi/BLE connectivity test | 5 | $2.08 | Scan, connect, data transfer |
| LoRa range test (basic) | 10 | $4.17 | TX/RX packet exchange |
| Battery charging test | 10 | $4.17 | Charge current, protection cutoff |
| Write calibration offsets to NVS | 5 | $2.08 | Store per-unit cal data |
| Final QA sign-off | 5 | $2.08 | Log serial number, pass/fail |
| **Total per unit** | **133 min** | **$54.84** | ~2.2 hours |

### 3.4 Agriculture Module Calibration (Optional)

| Test Step | Time (min) | Cost @$25/hr |
|---|---|---|
| Soil moisture sensor calibration (wet/dry) | 20 | $8.33 |
| Soil temperature probe verification | 10 | $4.17 |
| Leaf wetness threshold tuning | 15 | $6.25 |
| **Agriculture cal total** | **45 min** | **$18.75** |

### 3.5 Solar Module Calibration (Optional)

| Test Step | Time (min) | Cost @$25/hr |
|---|---|---|
| Pyranometer calibration (outdoor reference) | 30 | $12.50 |
| Panel temperature probe verification (x2) | 15 | $6.25 |
| Power meter pulse verification | 10 | $4.17 |
| **Solar cal total** | **55 min** | **$22.92** |

### Testing & Calibration Cost Summary

| Item | One-Time | Per-Unit |
|---|---|---|
| Test equipment | $167.00 | — |
| Calibration standards | $230.00 | — |
| Base station testing & cal | — | $54.84 |
| Agriculture module cal | — | $18.75 |
| Solar module cal | — | $22.92 |
| **Total (base)** | **$397.00** | **$54.84** |
| **Total (full build)** | **$397.00** | **$96.51** |

---

## 4. Outdoor Station Enclosure & Fabrication

### 4.1 Main Electronics Enclosure

| Item | Cost | Notes |
|---|---|---|
| IP65 ABS junction box (150x100x60mm) | $12.00 | Gewiss GW44205 or equivalent |
| IP67 upgrade (polycarbonate, clear lid) | $18.00 | If transparent lid needed |
| PG7 cable glands (IP68) | 4 x $1.50 = $6.00 | Sensor cables |
| PG9 cable glands (IP68) | 2 x $2.00 = $4.00 | Power/antenna cables |
| Gore-Tex vent plug (M12) | $8.00 | Pressure equalization |
| M3 brass standoffs 8mm + screws | 4 x $0.30 = $1.20 | PCB mounting |
| M3 nylon lock nuts + washers | 4 x $0.10 = $0.40 | Anti-vibration |
| Silicone gasket sealant (tube) | $6.00 | Extra sealing on lid |
| **Subtotal — Main Enclosure** | **$37.60** | IP65 version |
| **Subtotal — Main Enclosure (IP67)** | **$43.60** | Polycarbonate upgrade |

### 4.2 Sensor Radiation Shield (Stevenson Screen)

| Item | Cost | Notes |
|---|---|---|
| 3D-printed radiation shield (PETG/ASA) | $8.00 | Material cost, ~100g filament |
| Commercial radiation shield (Davis 7714) | $25.00 | Professional option |
| UV-stable white spray paint (if 3D printed) | $5.00 | Krylon UV-resistant |
| M4 stainless mounting hardware | $3.00 | Bolts, nuts, washers |
| **Subtotal — Radiation Shield (DIY)** | **$16.00** | |
| **Subtotal — Radiation Shield (commercial)** | **$28.00** | |

### 4.3 Mounting Pole & Hardware

| Item | Cost | Notes |
|---|---|---|
| Galvanized steel pole (1.5m, 32mm OD) | $15.00 | Main mounting mast |
| Pole ground plate / flange mount | $8.00 | Base mounting |
| U-bolts for enclosure mounting (stainless) | 2 x $3.00 = $6.00 | Box to pole |
| Pole cap / weather cap | $2.00 | Top seal |
| Anemometer mounting arm (L-bracket, SS) | $8.00 | Extend from pole top |
| Rain gauge mounting bracket | $5.00 | Level mount, clear of obstructions |
| Cable ties (UV-resistant, black) | $4.00 | Pack of 100 |
| Cable conduit / spiral wrap (2m) | $5.00 | Outdoor cable protection |
| **Subtotal — Mounting** | **$53.00** | |

### 4.4 Painting & Surface Treatment

| Item | Cost | Notes |
|---|---|---|
| Primer spray (metal, rust-inhibiting) | $8.00 | For pole and brackets |
| UV-resistant white topcoat spray (x2 cans) | $12.00 | Reflective, weatherproof |
| Stainless steel polish / passivation | $5.00 | For SS hardware |
| Anti-seize compound (small tube) | $6.00 | Threaded connections |
| **Subtotal — Paint & Treatment** | **$31.00** | |

### 4.5 Weatherproofing & Sealing

| Item | Cost | Notes |
|---|---|---|
| Conformal coating (Humiseal 1A33, 55mL) | $22.00 | PCB protection spray |
| Self-amalgamating tape (for SMA connector) | $5.00 | Waterproof RF connection |
| Heat shrink tubing assortment | $4.00 | Wire splice protection |
| Dielectric grease (small tube) | $4.00 | Connector waterproofing |
| Marine-grade silicone sealant | $8.00 | External cable entry sealing |
| **Subtotal — Weatherproofing** | **$43.00** | |

### 4.6 Solar Panel Mounting

| Item | Cost | Notes |
|---|---|---|
| Adjustable tilt bracket (small, aluminum) | $10.00 | Solar panel angle adjustment |
| Stainless mounting screws for panel | $3.00 | — |
| MC4 to bare wire adapter (if panel uses MC4) | $4.00 | Solar panel connection |
| **Subtotal — Solar Mount** | **$17.00** | |

### Outdoor Station Cost Summary

| Category | Cost |
|---|---|
| Main enclosure (IP65) | $37.60 |
| Radiation shield (DIY) | $16.00 |
| Mounting pole & hardware | $53.00 |
| Painting & surface treatment | $31.00 |
| Weatherproofing & sealing | $43.00 |
| Solar panel mounting | $17.00 |
| **Outdoor Station Total** | **$197.60** |

---

## 5. Packaging, Shipping & Miscellaneous

### 5.1 Product Packaging (Per Unit)

| Item | Cost | Notes |
|---|---|---|
| Corrugated shipping box (outer, 400x300x200mm) | $3.50 | Double-wall, sturdy |
| Inner product box (custom printed, optional) | $5.00 | Branded packaging |
| PE foam insert (die-cut, protective) | $4.00 | Custom cutouts for components |
| Anti-static bags (for PCB + cables) | $0.50 | ESD protection |
| Desiccant packets (x3) | $0.30 | Moisture protection |
| Bubble wrap / air pillows (void fill) | $1.00 | Shock protection |
| Cable wrap / velcro ties | $0.50 | Tidy cable management |
| **Subtotal — Packaging** | **$14.80** | Per unit |

### 5.2 Documentation & Accessories (Per Unit)

| Item | Cost | Notes |
|---|---|---|
| Quick start guide (printed, color, A5) | $1.50 | Folded insert |
| Pinout / wiring diagram card | $0.50 | Laminated reference card |
| USB-C cable (1m) | $3.00 | For charging/programming |
| Spare cable glands (2x PG7) | $3.00 | Replacement |
| Spare JST PH connectors (4-pack) | $2.00 | Pre-crimped pigtails |
| Mounting screws assortment bag | $2.00 | SS screws, nuts, washers |
| **Subtotal — Docs & Accessories** | **$12.00** | Per unit |

### 5.3 Shipping Costs

| Destination | Weight (~3 kg) | Cost |
|---|---|---|
| Domestic (US, ground) | 3 kg | $12.00 |
| Domestic (US, express) | 3 kg | $25.00 |
| International (standard) | 3 kg | $35.00 |
| International (express) | 3 kg | $55.00 |

### 5.4 Miscellaneous / Consumables

| Item | Cost | Notes |
|---|---|---|
| Solder paste (10g syringe, SAC305) | $8.00 | Shared across builds |
| Flux (rosin pen) | $5.00 | Shared |
| IPA cleaning (500mL bottle) | $6.00 | PCB cleaning |
| Kapton tape | $4.00 | Masking during conformal coat |
| Label printer labels (serial numbers) | $3.00 | QR code + serial |
| Wire (22AWG silicone, 5 colors, 5m each) | $8.00 | Wiring harnesses |
| Heatshrink assortment | $4.00 | Wire protection |
| **Subtotal — Consumables** | **$38.00** | Shared across ~10 units |
| **Per-unit consumables** | **$3.80** | |

### Packaging & Misc Cost Summary (Per Unit)

| Category | Cost |
|---|---|
| Product packaging | $14.80 |
| Documentation & accessories | $12.00 |
| Shipping (domestic ground) | $12.00 |
| Consumables (per-unit share) | $3.80 |
| **Packaging & Misc Total** | **$42.60** |

---

## 6. Grand Total Summary

### Per-Unit Cost Breakdown (Prototype, 1–5 units)

| Category | Base Station | Full Build (Agri+Solar) |
|---|---|---|
| **Electronic Components (BOM)** | $145.34 | $190.84 |
| **PCB Fabrication & Assembly** | $41.60 | $41.60 |
| **Testing & Calibration** | $54.84 | $96.51 |
| **Outdoor Station & Enclosure** | $197.60 | $197.60 |
| **Packaging, Shipping & Misc** | $42.60 | $42.60 |
| | | |
| **TOTAL PER UNIT** | **$481.98** | **$569.15** |

### One-Time Costs (NRE / Setup)

| Item | Cost |
|---|---|
| Test equipment | $167.00 |
| Calibration reference standards | $230.00 |
| Solder stencil (reusable) | $25.00 |
| **Total One-Time NRE** | **$422.00** |

### True Cost for First Unit

| | Base | Full Build |
|---|---|---|
| Per-unit cost | $481.98 | $569.15 |
| One-time NRE | $422.00 | $422.00 |
| **First Unit Total** | **$903.98** | **$991.15** |

### Volume Pricing Estimate

| Volume | Per-Unit (Base) | Per-Unit (Full) | Notes |
|---|---|---|---|
| 1 unit | $903.98 | $991.15 | Includes NRE |
| 5 units | $566.38 | $653.55 | NRE amortized |
| 10 units | $524.18 | $611.35 | PCB cost drops ~30% |
| 50 units | $420.00 | $500.00 | BOM volume discounts ~15% |
| 100 units | $360.00 | $435.00 | Assembly line efficiency |

> Volume pricing assumes bulk component discounts, amortized NRE, and
> assembly efficiency gains. Actual pricing depends on supplier MOQs
> and assembly partner rates.

---

## 7. Cost Optimization Opportunities

| Opportunity | Savings | Trade-off |
|---|---|---|
| Use HASL finish instead of ENIG | $8/board | Reduced corrosion resistance |
| 2-layer PCB (remove impedance control) | $5/board | Lose LoRa performance |
| Commercial-grade ESP32 (drop -I suffix) | $1.50/unit | 0°C lower limit |
| Source sensors from LCSC/AliExpress | $15–25/unit | Longer lead time, QC risk |
| 3D-print enclosure (PETG/ASA) | $20 savings | Less IP protection |
| Skip conformal coating | $22 savings | Reduced outdoor durability |
| DIY assembly (no PCBA service) | $18/board | Requires soldering skill |
| Bundle anemometer + rain gauge kit | $10–15 savings | Buy weather instrument kit |

---

*This estimate is based on single-unit / small-batch prototype pricing as of
February 2026. Prices may vary by supplier, region, and order timing. All costs
are estimates and should be verified with supplier quotes before procurement.*

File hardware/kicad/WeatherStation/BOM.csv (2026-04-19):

Reference | Value | Footprint | Qty | Description | Manufacturer | MPN | Supplier | Notes
U12 | ATWINC1500-MR210PB | Package_DFN_QFN:QFN-28_5x5mm | 1 | WiFi 802.11 b/g/n Module, SPI, Integrated TCP/IP, -40/+85C | Microchip | ATWINC1500-MR210PB | Mouser | SPI3 (PB3-PB5), CS=PE3, RST=PE4, IRQ=PE5, CHIP_EN=PE6
U13 | RN4870-I/RM | Module:RN4870 | 1 | BLE 5.0 Module, UART, Integrated GATT, -40/+85C | Microchip | RN4870-I/RM130 | Mouser | USART3 (PB10/PB11), RST=PD8, STATUS=PD9, On-module antenna
U14 | W5500 | Package_QFP:LQFP-48_7x7mm_P0.5mm | 1 | Hardwired TCP/IP Ethernet Controller, SPI, 8 sockets, -40/+85C | WIZnet | W5500 | Mouser | SPI2 (PB12-PB15), RST=PD3, INT=PD4, 25MHz crystal
U15 | SIM7600E-H | Module:SIM7600 | 1 | LTE Cat-4 Cellular Module, UART, 150Mbps DL, -40/+85C | SIMCom | SIM7600E-H | Mouser | UART4 (PC10/PC11), PWRKEY=PD5, STATUS=PD6, DTR=PD7, RI=PE2
U16 | TPS7A2033DGNR | Package_TO_SOT_SMD:SOT-23-5 | 1 | 3.3V to 3.8V LDO for SIM7600, 2A max | Texas Instruments | TPS7A2033DGNR | Mouser | 3.8V output for SIM7600 VBAT, 2A peak current capable
U2 | TP4056 | Package_SO:SOIC-8_3.9x4.9mm_P1.27mm | 1 | LiPo Battery Charger IC, 500mA | Nanjing Top Power | TP4056 | LCSC | Set RPROG=2.2k for 500mA charge current
U2A | DW01A | Package_SO:SOT-23-6 | 1 | Battery Protection IC (OVP/UVP/OCP) | Fortune Semi | DW01A-G | LCSC | Paired with FS8205A dual MOSFET
Q1 | FS8205A | Package_SO:SOT-23-6 | 1 | Dual N-MOSFET for battery protection | Fortune Semi | FS8205A | LCSC | Use with DW01A for Li-ion protection
U3 | AMS1117-3.3 | Package_TO_SOT_SMD:SOT-223-3_TabPin2 | 1 | 3.3V LDO Regulator, 1A, LDO | AMS | AMS1117-3.3 | LCSC | Dropout 1.1V typical. Input cap 10uF, output 22uF
U4 | BME280 | Package_LGA:Bosch_BME280_LGA-8_2.5x2.5mm | 1 | Temp/Humidity/Pressure Sensor, I2C 0x76 | Bosch Sensortec | BME280 | Mouser | Accuracy: +/-1C, +/-3%RH, +/-1hPa
U5 | AS5600 | Package_SO:SOIC-8_3.9x4.9mm_P1.27mm | 1 | 12-bit Magnetic Rotary Encoder, I2C 0x36 | ams-OSRAM | AS5600-ASOM | Mouser | Requires diametrically magnetized magnet on vane shaft
U6 | SI1145 | Package_DFN_QFN:QFN-10-1EP_3x3mm_P0.6mm | 1 | UV Index / IR / Visible Light Sensor, I2C 0x60 | Silicon Labs | SI1145-A10-GMR | DigiKey | Digital output, built-in ADC
U7 | BH1750FVI | Package_SO:SOIC-8_3.9x4.9mm_P1.27mm | 1 | Ambient Light Sensor, I2C 0x23, 1-65535 lux | ROHM | BH1750FVI-TR | Mouser | 16-bit digital output, auto-ranging
U8 | SX1276 | Module:RFM95W | 1 | LoRa Transceiver Module 868/915MHz, SPI | Semtech/HopeRF | RFM95W-868S2 | Mouser | SX1276 based, +20dBm TX, -148dBm RX sensitivity
J1 | USB-C | Connector_USB:USB_C_Receptacle_GCT_USB4105 | 1 | USB Type-C Receptacle, 16-pin | GCT | USB4105-GF-A | DigiKey | CC1/CC2 with 5.1k pulldown for UFP/sink
J2 | JST_PH_2P | Connector_JST:JST_PH_B2B-PH-K_1x02_P2.00mm_Vertical | 1 | Solar Panel Input, 6V max | JST | B2B-PH-K-S |  | Polarity: Pin1=V+, Pin2=GND
J3 | JST_PH_2P | Connector_JST:JST_PH_B2B-PH-K_1x02_P2.00mm_Vertical | 1 | 18650 LiPo Battery Connector | JST | B2B-PH-K-S |  | Polarity: Pin1=V+, Pin2=GND. Use protected cell.
J4 | RJ11_4P4C | Connector_RJ:RJ11_Amphenol_54601 | 1 | Anemometer Connector (wind speed) | Amphenol | 54601-908LF |  | Reed switch type, 2 active pins
J5 | RJ11_4P4C | Connector_RJ:RJ11_Amphenol_54601 | 1 | Rain Gauge Connector (tipping bucket) | Amphenol | 54601-908LF |  | Reed switch type, 2 active pins
J6 | SMA_Edge | Connector_Coaxial:SMA_Amphenol_132289_EdgeMount | 1 | LoRa Antenna SMA Female, 50ohm | Amphenol | 132289 | Mouser | Edge mount, maintain 50ohm trace to U8
J7 | Header_1x04 | Connector_PinHeader_2.54mm:PinHeader_1x04_P2.54mm_Vertical | 1 | UART Debug Header (TX/RX/3V3/GND) | Generic |  |  | Pin1=TX, Pin2=RX, Pin3=3V3, Pin4=GND
J8 | JST_PH_3P | Connector_JST:JST_PH_B3B-PH-K_1x03_P2.00mm_Vertical | 1 | Soil Moisture Sensor (shallow) — Agriculture | JST | B3B-PH-K-S |  | V+/GND/SIG, Capacitive type
J9 | JST_PH_3P | Connector_JST:JST_PH_B3B-PH-K_1x03_P2.00mm_Vertical | 1 | Soil Moisture Sensor (deep) — Agriculture | JST | B3B-PH-K-S |  | V+/GND/SIG, Capacitive type
J10 | JST_PH_3P | Connector_JST:JST_PH_B3B-PH-K_1x03_P2.00mm_Vertical | 1 | Soil Temperature DS18B20 — Agriculture | JST | B3B-PH-K-S |  | V+/GND/DATA, Waterproof probe
J11 | JST_PH_3P | Connector_JST:JST_PH_B3B-PH-K_1x03_P2.00mm_Vertical | 1 | Leaf Wetness Sensor — Agriculture | JST | B3B-PH-K-S |  | V+/GND/SIG, Resistive type
J12 | JST_PH_4P | Connector_JST:JST_PH_B4B-PH-K_1x04_P2.00mm_Vertical | 1 | Pyranometer ML8511 — Solar | JST | B4B-PH-K-S |  | V+/GND/OUT/EN, Shares GPIO7 with J8
J13 | JST_PH_3P | Connector_JST:JST_PH_B3B-PH-K_1x03_P2.00mm_Vertical | 1 | Panel Temp Front DS18B20 — Solar | JST | B3B-PH-K-S |  | V+/GND/DATA, Epoxy-mount to panel front
J14 | JST_PH_3P | Connector_JST:JST_PH_B3B-PH-K_1x03_P2.00mm_Vertical | 1 | Panel Temp Back DS18B20 — Solar | JST | B3B-PH-K-S |  | V+/GND/DATA on GPIO19
J15 | JST_PH_2P | Connector_JST:JST_PH_B2B-PH-K_1x02_P2.00mm_Vertical | 1 | Power Meter Pulse Input — Solar | JST | B2B-PH-K-S |  | SIG/GND, S0 pulse interface
D1 | SS14 | Diode_SMD:D_SMA | 1 | Schottky Diode, 40V 1A — Solar input protection | Vishay | SS14-E3/61T |  | Low Vf for solar efficiency
D2 | SMAJ5.0A | Diode_SMD:D_SMA | 1 | TVS Diode, 5V — USB ESD protection | Littelfuse | SMAJ5.0A |  | Bidirectional preferred for USB
D3 | LED_Red | LED_SMD:LED_0603_1608Metric | 1 | Charging Indicator LED | Generic |  |  | With 1k series resistor
D4 | LED_Green | LED_SMD:LED_0603_1608Metric | 1 | Charge Complete / Standby LED | Generic |  |  | With 1k series resistor
D5 | LED_Blue | LED_SMD:LED_0603_1608Metric | 1 | Power On Indicator, 3V3 rail | Generic |  |  | With 1k series resistor
D6 | LED_Green | LED_SMD:LED_0603_1608Metric | 1 | Status LED on GPIO2 | Generic |  |  | With 330R series resistor
R1 | 5.1k | Resistor_SMD:R_0402_1005Metric | 2 | USB-C CC1/CC2 pulldown (UFP) | Generic |  | LCSC | 0402, 1%, 0.1W
R2 | 2.2k | Resistor_SMD:R_0402_1005Metric | 1 | TP4056 RPROG — sets 500mA charge | Generic |  | LCSC | 0402, 1%, 0.1W
R3 | 10k | Resistor_SMD:R_0402_1005Metric | 1 | ATWINC1500 CHIP_EN pull-up | Generic |  | LCSC | 0402, 5%, 0.1W
R4 | 10k | Resistor_SMD:R_0402_1005Metric | 1 | RN4870 RST pull-up | Generic |  | LCSC | 0402, 5%, 0.1W
R5 | 330 | Resistor_SMD:R_0402_1005Metric | 1 | Status LED current limiter (GPIO2) | Generic |  | LCSC | 0402, 5%, 0.1W
R6 | 1k | Resistor_SMD:R_0402_1005Metric | 4 | LED series resistors (D3-D5 + spare) | Generic |  | LCSC | 0402, 5%, 0.1W
R7 | 100k | Resistor_SMD:R_0402_1005Metric | 2 | Battery voltage divider (100k/100k) | Generic |  | LCSC | 0402, 1%, 0.1W
R8 | 4.7k | Resistor_SMD:R_0402_1005Metric | 2 | I2C SDA/SCL pull-up resistors | Generic |  | LCSC | 0402, 5%, 0.1W
R9 | 10k | Resistor_SMD:R_0402_1005Metric | 3 | GPIO pull-ups (wind/rain/power pulse) | Generic |  | LCSC | 0402, 5%, 0.1W
R10 | 4.7k | Resistor_SMD:R_0402_1005Metric | 2 | 1-Wire pull-ups (soil temp + panel temp) | Generic |  | LCSC | 0402, 5%, 0.1W
R11 | 100 | Resistor_SMD:R_0402_1005Metric | 2 | UART TX/RX series protection | Generic |  | LCSC | 0402, 5%, 0.1W
R12 | 10k | Resistor_SMD:R_0402_1005Metric | 1 | Leaf wetness pull-down | Generic |  | LCSC | 0402, 5%, 0.1W
C1 | 10uF | Capacitor_SMD:C_0805_2012Metric | 2 | ATWINC1500 3V3 decoupling + AMS1117 input | Generic |  | LCSC | 0805, 16V, X5R
C2 | 100nF | Capacitor_SMD:C_0402_1005Metric | 14 | IC decoupling caps (ATWINC1500 x2 + RN4870 x1 + W5500 x4 + sensors x4 + misc x3) | Generic |  | LCSC | 0402, 16V, X7R
C3 | 22uF | Capacitor_SMD:C_0805_2012Metric | 1 | AMS1117 output cap | Generic |  | LCSC | 0805, 10V, X5R
C4 | 1uF | Capacitor_SMD:C_0402_1005Metric | 2 | AS5600 decoupling + spare | Generic |  | LCSC | 0402, 16V, X7R
C5 | 10uF | Capacitor_SMD:C_0805_2012Metric | 1 | TP4056 input cap | Generic |  | LCSC | 0805, 16V, X5R
SW1 | BOOT | Button_SMD:SW_SPST_PTS645 | 1 | Boot button (GPIO0 to GND) | C&K | PTS645SM43SMTR92LFS |  | Tactile, 6mm
SW2 | RESET | Button_SMD:SW_SPST_PTS645 | 1 | Reset button (EN to GND) | C&K | PTS645SM43SMTR92LFS |  | Tactile, 6mm
F1 | 500mA | Fuse_SMD:Fuse_1206_3216Metric | 1 | Polyfuse / Resettable fuse, USB input | Bourns | MF-MSMF050-2 |  | Holds 500mA, trips 1A
H1-H4 | MountingHole_M3 | MountingHole:MountingHole_3.2mm_M3_Pad_Via | 4 | M3 mounting holes at corners |  |  |  | Use M3 brass standoffs, 8mm
FID1-FID3 | Fiducial | Fiducial:Fiducial_1mm_Mask2mm | 3 | PCB fiducial marks for P&P alignment
U10 | STM32F407VGT6 | Package_QFP:LQFP-100_14x14mm_P0.5mm | 1 | ARM Cortex-M4F MCU, 168MHz, 1MB Flash, 192KB SRAM, Industrial -40/+105C | ST Microelectronics | STM32F407VGT6 | Mouser/DigiKey | Industrial temp range, FPU, 3x ADC, 6x USART
U11 | MAX3485ESA+ | Package_SO:SOIC-8_3.9x4.9mm_P1.27mm | 1 | RS485 Transceiver, Half-Duplex, 10Mbps, 3.3V, Industrial -40/+85C | Maxim/Analog Devices | MAX3485ESA+ | Mouser | Low-power, auto-direction via DE/RE
Y1 | 8MHz | Crystal:Crystal_SMD_HC49-SD | 1 | 8 MHz HSE Crystal for STM32F407 | Abracon | ABM3B-8.000MHZ-10-1-U-T | Mouser | 18pF load, ±10ppm, -40/+85C
J16 | Phoenix_MC_4P | Connector_Phoenix_MC:PhoenixContact_MC_01x04_G_3.5mm | 1 | RS485 Bus Connector, 4-pin pluggable terminal block | Phoenix Contact | 1844210 | Mouser | Pin1=A, Pin2=B, Pin3=GND, Pin4=Shield
J18 | SMA_Edge | Connector_Coaxial:SMA_Amphenol_132289_EdgeMount | 1 | WiFi Antenna SMA Female, 50ohm (ATWINC1500) | Amphenol | 132289 | Mouser | Edge mount, 50ohm trace to U12
J19 | RJ45_Magjack | Connector_RJ:RJ45_Amphenol_RJHSE-5380 | 1 | RJ45 with Integrated Magnetics (W5500 Ethernet) | Amphenol | RJHSE-5380 | Mouser | 10/100 Ethernet, integrated transformer
J20 | Nano_SIM | Connector:SIM_Nano_Molex_78800 | 1 | Nano-SIM Card Holder, Push-Push | Molex | 78800-0001 | Mouser | For SIM7600 cellular module
J21 | SMA_Edge | Connector_Coaxial:SMA_Amphenol_132289_EdgeMount | 1 | LTE Antenna SMA Female, 50ohm (SIM7600) | Amphenol | 132289 | Mouser | Edge mount, 50ohm trace to U15
D10 | SMBJ6.0CA | Diode_SMD:D_SMB | 1 | TVS Diode, 6V Bidirectional — RS485 bus protection | Littelfuse | SMBJ6.0CA | Mouser | Protects MAX3485 A/B lines
R22 | 120 | Resistor_SMD:R_0402_1005Metric | 1 | RS485 Bus Termination Resistor | Generic |  | LCSC | 0402, 1%, 0.1W
R20 | 10k | Resistor_SMD:R_0402_1005Metric | 1 | STM32 NRST Pull-up | Generic |  | LCSC | 0402, 5%, 0.1W
R21 | 10k | Resistor_SMD:R_0402_1005Metric | 1 | STM32 BOOT0 Pull-down (boot from flash) | Generic |  | LCSC | 0402, 5%, 0.1W
R23-R24 | 100 | Resistor_SMD:R_0402_1005Metric | 2 | RN4870 UART Series Protection Resistors | Generic |  | LCSC | 0402, 5%, 0.1W
R25-R26 | 10k | Resistor_SMD:R_0402_1005Metric | 2 | Mode DIP Switch Pull-down Resistors | Generic |  | LCSC | 0402, 5%, 0.1W
C20-C21 | 20pF | Capacitor_SMD:C_0402_1005Metric | 2 | HSE Crystal Load Caps | Generic |  | LCSC | 0402, 50V, C0G/NP0
C22 | 100nF | Capacitor_SMD:C_0402_1005Metric | 4 | STM32 VDD Decoupling (×4) | Generic |  | LCSC | 0402, 16V, X7R
C23 | 4.7uF | Capacitor_SMD:C_0805_2012Metric | 1 | STM32 VDD Bulk Cap | Generic |  | LCSC | 0805, 16V, X5R
C24 | 100nF | Capacitor_SMD:C_0402_1005Metric | 1 | STM32 NRST Filter Cap | Generic |  | LCSC | 0402, 16V, X7R
C25 | 100nF | Capacitor_SMD:C_0402_1005Metric | 1 | MAX3485 VCC Decoupling | Generic |  | LCSC | 0402, 16V, X7R
SW3 | MODE_DIP | Switch_SMD:SW_DIP_SPSTx02_Slide_6.7x6.64mm_W8.61mm_P2.54mm | 1 | 2-Position DIP Switch — Operating Mode Select | C&K | SDA02H1SBD | DigiKey | SW1: SCADA/Cloud, SW2: Hybrid
Y2 | 25MHz | Crystal:Crystal_SMD_HC49-SD | 1 | 25 MHz Crystal for W5500 Ethernet Controller | Abracon | ABM3B-25.000MHZ-10-1-U-T | Mouser | 18pF load, ±10ppm, -40/+85C
C26-C27 | 18pF | Capacitor_SMD:C_0402_1005Metric | 2 | W5500 Crystal Load Caps | Generic |  | LCSC | 0402, 50V, C0G/NP0
C28 | 10uF | Capacitor_SMD:C_0805_2012Metric | 1 | ATWINC1500 bulk decoupling | Generic |  | LCSC | 0805, 16V, X5R
C29 | 4.7uF | Capacitor_SMD:C_0805_2012Metric | 1 | RN4870 bulk decoupling | Generic |  | LCSC | 0805, 16V, X5R
C30 | 10uF | Capacitor_SMD:C_0805_2012Metric | 1 | W5500 bulk decoupling | Generic |  | LCSC | 0805, 16V, X5R
C31 | 100uF | Capacitor_SMD:C_1206_3216Metric | 1 | SIM7600 VBAT bulk cap | Generic |  | LCSC | 1206, 10V, X5R
C32 | 470uF | Capacitor_Tantalum_SMD:CP_EIA-7343-31_Kemet-D | 1 | SIM7600 VBAT bulk cap (peak current) | Generic |  | LCSC | 7343, 6.3V, Tantalum
J22 | Micro_SD | Connector:MicroSD_Molex_5031821852 | 1 | Micro-SD Card Holder, Push-Push, -25/+85C | Molex | 5031821852 | Mouser | SPI2 shared bus, CS=PD10, DET=PD11 (active low)
C38 | 100nF | Capacitor_SMD:C_0402_1005Metric | 1 | SD card VCC decoupling | Generic |  | LCSC | 0402, 16V, X7R
R27 | 10k | Resistor_SMD:R_0402_1005Metric | 1 | SD card detect pull-up (PD11) | Generic |  | LCSC | 0402, 5%, 0.1W

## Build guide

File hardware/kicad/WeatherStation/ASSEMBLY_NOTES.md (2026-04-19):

# Weather Station PCB — Assembly & Manufacturing Notes

## PCB Specifications

| Parameter | Value |
|---|---|
| Board Dimensions | 100mm x 80mm |
| Layer Count | 4 |
| Stackup | Signal / GND / Power / Signal |
| Thickness | 1.6mm |
| Material | FR4 Tg170 |
| Copper Weight | 1oz (35um) all layers |
| Surface Finish | ENIG (for outdoor corrosion resistance) |
| Solder Mask | Green, both sides |
| Silkscreen | White, both sides |
| Min Trace/Space | 0.15mm / 0.15mm |
| Min Drill | 0.3mm (laser via), 0.4mm (mechanical) |
| Impedance Control | Yes (50ohm LoRa, 90ohm USB diff) |
| IPC Class | 2 (Standard) |
| UL Rating | UL 94V-0 |

## Single-MCU Architecture: STM32F407VGT6

### MCU Selection

| Parameter | Value |
|---|---|
| MCU | STM32F407VGT6 (LQFP-100) |
| Core | ARM Cortex-M4F @ 168 MHz |
| Flash | 1 MB |
| SRAM | 192 KB (128 KB + 64 KB CCM) |
| Temp Range | -40°C to +105°C (Industrial) |
| FPU | Single-precision hardware FPU |

### Communication Modules

| Module | Interface | Function |
|---|---|---|
| ATWINC1500-MR210PB | SPI3 (PB3-PB5) | WiFi 802.11 b/g/n, integrated TCP/IP |
| RN4870-I/RM | USART3 (PB10/PB11) | BLE 5.0, integrated GATT |
| W5500 | SPI2 (PB12-PB15) | Ethernet 10/100, 8 TCP sockets [optional] |
| SIM7600E-H | UART4 (PC10/PC11) | LTE Cat-4 cellular, 150 Mbps [optional] |
| Micro-SD Card | SPI2 (shared, CS=PD10) | FAT32 data logging, GB-scale storage [optional] |

### Firmware Flashing

| Method | Tool | Command |
|---|---|---|
| SWD (ST-Link) | probe-rs | `probe-rs run --chip STM32F407VGTx` |
| SWD (ST-Link) | cargo-flash | `cargo flash --chip STM32F407VGTx --release` |
| SWD (ST-Link) | OpenOCD | `openocd -f interface/stlink.cfg -f target/stm32f4x.cfg` |

> **BOOT0 pin** must be LOW for normal flash boot. Pull-down resistor R21 (10k) ensures this.
> For DFU boot (USB), drive BOOT0 HIGH during reset.

### Mitigation for Outdoor Deployment

| Risk | Mitigation |
|---|---|
| Water ingress | IP65+ ABS enclosure with cable glands |
| Condensation | Conformal coating (Humiseal 1A33) on PCB |
| UV degradation | UV-stabilized enclosure, no direct sun on PCB |
| Temperature extremes | STM32F407 industrial -40/+105°C rating |
| Lightning/surge | TVS diodes on all external connectors |
| Corrosion | ENIG finish + conformal coating |
| Vibration | M3 standoffs with lock washers, strain relief on cables |

## Layer Stackup Detail

```
┌─────────────────────────────────────────┐
│  F.SilkS   — Component labels          │
│  F.Mask    — Solder mask (green)        │
│  F.Cu      — Top copper (signal)  35um  │  ← Components side
│  Prepreg   — 0.2mm FR4                  │
│  In1.Cu    — GND plane (solid)    35um  │  ← Unbroken ground reference
│  Core      — 1.065mm FR4                │
│  In2.Cu    — Power plane          35um  │  ← 3V3 pour + VBAT island
│  Prepreg   — 0.2mm FR4                  │
│  B.Cu      — Bottom copper (signal)35um │  ← Connectors, some passives
│  B.Mask    — Solder mask (green)        │
│  B.SilkS   — Bottom labels             │
└─────────────────────────────────────────┘
Total: 1.6mm
```

## Critical Layout Rules

### Antenna Keep-Out Zone
- **ATWINC1500 WiFi antenna**: 30mm x 12mm keep-out near SMA connector J18
- **RN4870 BLE antenna**: 15mm x 8mm keep-out around on-module chip antenna
- **Constraint**: No copper on ANY layer (including ground planes) in keep-out zones
- No components within these zones

### LoRa RF Trace
- 50-ohm controlled impedance from SX1276 RFIO pin to SMA connector
- Trace width: calculate based on stackup (approx 0.28mm for 50ohm on 0.2mm prepreg)
- Keep ground plane continuous under RF trace
- Surround SMA pad with ground stitching vias (0.3mm drill, 0.6mm ring, 1mm spacing)
- PI matching network between SX1276 and antenna

### USB Differential Pair
- 90-ohm differential impedance
- Route on top layer with ground reference on In1.Cu
- Keep pair tightly coupled, match lengths within 0.1mm
- Avoid crossing splits in reference plane

### Power Distribution
- In2.Cu: Main 3V3 copper pour covering >80% of board
- VBAT island on In2.Cu for battery-direct components only
- Decoupling caps within 3mm of every IC power pin
- Use thermal relief on ground vias under exposed pads

## Assembly Sequence

1. **Solder Paste** — Stencil print (0.12mm thickness)
2. **Place SMD Bottom** — If any bottom-side components
3. **Reflow Bottom** — Peak 245°C, SAC305
4. **Place SMD Top** — All ICs and passives
5. **Reflow Top** — Peak 245°C, SAC305
6. **Place THT** — Connectors (JST-PH, RJ11, SMA, pin headers)
7. **Wave/Selective Solder** — THT components
8. **Manual** — Communication modules (ATWINC1500, RN4870), USB-C
9. **Clean** — IPA wash to remove flux residue
10. **Inspect** — AOI + visual inspection
11. **Program** — Flash firmware via SWD (ST-Link V2) or UART header
12. **Test** — Functional test (see test procedure below)
13. **Conformal Coat** — Humiseal 1A33, avoid connectors and antenna

## Functional Test Procedure

```
1. Visual inspection — no shorts, missing components, tombstones
2. Power-on test:
   a. Connect USB-C, verify 3.3V rail (U3 output) = 3.30V ±0.05V
   b. Verify charge LED (D3) illuminates with battery connected
   c. Measure current draw: ~60mA idle (WiFi off), ~160mA (WiFi active)
3. Firmware flash:
   a. Connect ST-Link V2 to SWD header (SWDIO, SWCLK, GND, 3.3V)
   b. Flash via probe-rs: probe-rs run --chip STM32F407VGTx target/release/weather-station
4. Sensor check:
   a. I2C scan: should find 0x76 (BME280), 0x36 (AS5600), 0x60 (SI1145), 0x23 (BH1750)
   b. Read temperature (should be ~25°C room temp)
   c. Read pressure (should be ~1013 hPa at sea level)
5. Communication check:
   a. WiFi: scan for APs, verify connection
   b. BLE: scan from phone, verify GATT advertisement
   c. LoRa: transmit test packet, verify on receiver
   d. UART: connect terminal at 115200 baud, verify console output
6. GPIO check:
   a. Trigger anemometer input — verify pulse count
   b. Trigger rain gauge input — verify tip count
   c. Toggle status LED — verify GPIO2 output
7. Industry connector check (if populated):
   a. Agriculture: verify ADC readings on GPIO7, GPIO17, GPIO18
   b. Agriculture: verify 1-Wire on GPIO16
   c. Solar: verify ADC on GPIO7, 1-Wire on GPIO16/GPIO19
   d. Solar: verify pulse input on GPIO20
8. SD card check (if J22 populated):
   a. Insert FAT32-formatted micro-SD card
   b. Verify card detect (PD11 goes low)
   c. Verify SPI2 communication at 400 kHz init, then 25 MHz normal
   d. Verify /weather/ directory creation and CSV file write
   e. Remove card, verify PD11 goes high and firmware falls back to flash
```

## Enclosure Recommendations

| Parameter | Specification |
|---|---|
| Material | ABS or polycarbonate, UV-stabilized |
| IP Rating | IP65 minimum (IP67 preferred) |
| Size | 150mm x 100mm x 60mm (internal) |
| Color | White or light gray (minimize solar heating) |
| Mounting | DIN rail or wall mount with stainless hardware |
| Cable Entry | PG7/PG9 cable glands (IP68) for sensor cables |
| Ventilation | Gore-Tex vent plug (allows pressure equalization, blocks water) |
| Temperature | -40°C to +85°C rated |

## Conformal Coating Map

```
  ┌──────────────────────────────────┐
  │ ████ COAT ████  ░░NO COAT░░     │  ← ATWINC1500/RN4870 antenna zones: NO COAT
  │ ████████████████████████████████ │
  │ ████ STM32F407 ████ COAT  █████ │  ← MCU: COAT
  │ ████████████████████████████████ │
  │ █ LoRa █  ████████  █ Sensors █ │
  │ █ COAT █  ████████  █  COAT   █ │
  │ ████████  ████████  ███████████ │
  │ ░░SMA░░  ████████  ░░░░░░░░░░░ │  ← SMA: NO COAT
  │ █ Power █  ██████  ░Connectors░ │  ← JST/RJ11: NO COAT
  │ █ COAT  █  ██████  ░░NO COAT ░░ │
  │ ░░BAT░░  ░░USB-C░░  ░░UART░░░░ │  ← All edge connectors: NO COAT
  └──────────────────────────────────┘

  ████ = Apply conformal coating
  ░░░░ = Mask off (no coating)
```

## Ordering Checklist

- [ ] Verify STM32F407VGT6 industrial temp variant in BOM
- [ ] Verify ATWINC1500, RN4870, W5500, SIM7600 in BOM
- [ ] Verify 4-layer stackup specified in fabrication notes
- [ ] Verify impedance control requested (50ohm + 90ohm)
- [ ] Verify ENIG surface finish specified
- [ ] Verify Tg170 FR4 specified
- [ ] Generate Gerber files (RS-274X format)
- [ ] Generate drill files (Excellon format)
- [ ] Generate pick-and-place file (CSV with X/Y/Rotation)
- [ ] Include IPC-D-356 netlist for e-test
- [ ] Review DFM report from fabricator before ordering

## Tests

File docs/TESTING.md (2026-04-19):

# Testing Guide

## Test Architecture

The firmware uses a dual testing strategy:

1. **Host-side unit tests** — Run on `x86_64`, test pure logic (CRC, filters, validation, derived values)
2. **On-target integration tests** — Run on STM32F407 hardware, test I2C/SPI/GPIO interactions

## Running Host Tests

```bash
cd firmware
cargo test --target x86_64-unknown-linux-gnu
```

This runs tests in:
- `utils/crc.rs` — CRC-16 computation and verification
- `tests/integration.rs` — Data pipeline, validation, derived values, filtering, battery

## Test Categories

### CRC Tests (`utils/crc.rs`)
- Empty input produces init value (0xFFFF)
- Known test vector: `"123456789"` → `0x29B1`
- Round-trip verify/reject

### Data Validation Tests (`tests/integration.rs`)
- Temperature within/outside BME280 range (-40 to 85 C)
- Humidity clamping (0-100%)
- Pressure validation (300-1100 hPa)
- NaN/infinity rejection

### Derived Value Tests
- Heat index: only computed when T >= 27 C and H >= 40%
- Dew point: Magnus formula, rejects H <= 0%
- Wind chill: only when T < 10 C and wind > 4.8 km/h

### EMA Filter Tests
- First sample passes through unfiltered
- Subsequent samples are smoothed
- Alpha = 1.0 means no filtering

### Battery Voltage Tests
- Full charge (4.2V) → 100%
- Empty (3.0V) → 0%
- Below minimum → clamped to 0%

## Adding New Tests

Add host-testable functions with `#[cfg(test)]`:

```rust
#[cfg(test)]
mod tests {
    use super::*;

    #[test]
    fn test_my_function() {
        assert_eq!(my_function(input), expected);
    }
}
```

For integration tests, add to `tests/integration.rs`.

## On-Target Testing

For hardware integration testing on the STM32F407:

1. Connect ST-Link V2 via SWD header
2. Flash test firmware: `probe-rs run --chip STM32F407VGTx target/release/weather-station`
3. Observe serial output for sensor readings (USART1 @ 115200)
4. Use UART console commands:
   - `status` — Check all sensor statuses
   - `reading` — View current sensor values
   - `calibrate temp <offset>` — Verify calibration pipeline

## CI Integration

The CI pipeline runs:
1. `cargo fmt --check` — Formatting verification
2. `cargo clippy -- -D warnings` — Lint checks
3. `cargo test --target x86_64-unknown-linux-gnu` — Host tests
4. `cargo build --release` — Full release build

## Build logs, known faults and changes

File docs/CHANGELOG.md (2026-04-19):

# Changelog

All notable changes to this project will be documented in this file.

The format is based on [Keep a Changelog](https://keepachangelog.com/en/1.1.0/).

## [2.1.0] - 2026-03-15

### Added — SD Card Storage
- **SD card data logging** (`--features sdcard`): micro-SD card on SPI2 shared bus (CS=PD10, DET=PD11)
- FAT32 CSV logger with daily file rotation (`/weather/YYYY-MM-DD.csv`)
- 512-byte sector-aligned write buffer with 60s periodic flush
- Automatic fallback to internal flash when SD card is not inserted
- New `FlushSdCard` scheduler task for periodic buffer flushing
- Updated BOM with micro-SD card holder (Molex 5031821852), decoupling cap, detect pull-up
- `sdcard` feature added to `all-comms` and `full-system` feature groups

## [2.0.0] - 2026-03-15

### Changed — Single-MCU Architecture
- **BREAKING**: Migrated from dual-MCU (ESP32-S3 + STM32F407) to single-MCU (STM32F407VGT6 only)
- Replaced ESP32-S3 built-in WiFi with **ATWINC1500** module on SPI3
- Replaced ESP32-S3 built-in BLE with **RN4870** module on USART3
- Added optional **W5500 Ethernet** on SPI2 (`--features ethernet`)
- Added optional **SIM7600E-H Cellular** on UART4 (`--features cellular`)
- Removed ESP32-S3 bridge protocol (USART3 now used for RN4870 BLE)
- Removed `stm32` feature flag — STM32F407 is now the only target
- Changed toolchain: `esp-hal` → `stm32f4xx-hal`, `esp-alloc` → `embedded-alloc`
- Changed target: `xtensa-esp32s3-none-elf` → `thumbv7em-none-eabihf`
- Changed flashing: `esptool` → `probe-rs` / `cargo-flash` via SWD
- Changed power modes: Modem/Light/Deep sleep → Sleep (WFI) / Stop / Standby
- Reduced heap from 384 KB to 48 KB (STM32 SRAM constraint)
- Updated KiCad schematics, BOM, and symbol library for new modules
- Updated all documentation to reflect single-MCU architecture

## [0.2.0] - 2026-02-27

### Added — Industry Modules
- **Agriculture module** (`--features agriculture`):
  - Sensor drivers: capacitive soil moisture (dual-depth), DS18B20 soil temperature, leaf wetness
  - Evapotranspiration (ET₀) — FAO Penman-Monteith with Hargreaves-Samani fallback
  - Growing Degree Days (GDD) — configurable base temperature for 5 crop types
  - Frost alerts — multi-level (Watch/Warning/Critical) with humidity-adjusted radiative frost
  - Irrigation scheduling — soil moisture depletion model (field capacity to wilting point)
  - Disease risk index — Smith period model (leaf wetness duration × temperature)
  - Spray window assessment — wind, rain, and temperature inversion detection
- **Solar module** (`--features solar`):
  - Sensor drivers: ML8511 pyranometer, DS18B20 panel temperature (front/back)
  - Solar irradiance tracking (GHI) with ADC-to-W/m² calibration
  - Temperature derating — panel power loss from overheating (-0.35%/°C above STC)
  - Estimated power output — incorporates irradiance, derating, soiling, inverter efficiency
  - Daily energy yield integration (Wh) and peak sun hours (PSH) accumulation
  - Performance ratio — actual vs theoretical power ratio with daily averaging
  - Soiling loss estimation — days-since-rain accumulation model, rain auto-reset
  - Cloud transient detection — rapid irradiance change alerting
  - Sky condition classification (Clear/PartlyCloudy/Overcast/Night)
  - Daily summary reports (total yield, peak power, cloud transients)
- Cargo feature flags: `agriculture`, `solar`, `all-industries`
- Industry-specific MQTT topics and alert publishing
- Industry sensor status tracking in `SensorStatusMap`
- Industry hardware documentation with circuit diagrams and pin mappings
- Scheduler dynamically adds industry tasks based on enabled features

## [0.1.0] - 2026-02-27

### Added
- Initial firmware implementation for weather station
- **Sensors**: BME280 (temperature/humidity/pressure), AS5600 (wind direction), anemometer (wind speed), tipping bucket rain gauge, SI1145 (UV), BH1750 (ambient light)
- **Communication channels**: WiFi, BLE 5.0 GATT, LoRa SX1276, MQTT v3.1.1, HTTP REST API, UART serial console
- **Data pipeline**: 7-stage processing (acquisition, calibration, EMA filtering, validation, stuck sensor detection, derived values, packaging)
- **Derived values**: Heat index (Rothfusz regression), dew point (Magnus formula), wind chill
- **Power management**: 4 modes (active, modem sleep, light sleep, deep sleep) with LiPo battery monitoring and solar charging support
- **OTA updates**: Dual A/B partition scheme with SHA-256 verification and automatic rollback
- **Flash storage**: Circular buffer with CRC-16 integrity checks for offline data buffering
- **BLE provisioning**: WiFi credential configuration via BLE characteristic writes
- **UART console**: Interactive debug commands (status, reading, config, calibrate, dump, reset)
- **Documentation**: Architecture guide, hardware design, API reference, requirements, circuit diagrams, state machines, sequence diagrams, data pipeline diagrams
- **Tests**: Host-side unit tests for CRC, data validation, derived values, EMA filtering, battery voltage

### Quality Improvements
- Extracted shared `HeaplessWriter` formatter to `utils/fmt.rs` with `format_heapless!` macro
- Replaced all silent `let _ = Result` patterns with explicit error logging
- Added SAFETY documentation for all unsafe blocks
- Replaced 20+ magic numbers with named constants in `config.rs`
- Fixed `unwrap()` calls with `unwrap_or_default()` for robustness
- Aligned power consumption figures between architecture and hardware docs

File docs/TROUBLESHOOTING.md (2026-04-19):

# Troubleshooting

## Sensor Issues

### BME280 not responding
- **Symptom**: `SensorStatus::NotFound` for BME280, temperature/humidity/pressure all `None`
- **Check**: I2C address (0x76 vs 0x77 — some breakouts use 0x77 with SDO pulled high)
- **Check**: I2C pull-ups (4.7k on SDA/SCL)
- **Check**: Wiring — SDA to PB7, SCL to PB6
- **Fix**: If address is 0x77, update `BME280_ADDR` in `config.rs`

### BME280 stuck sensor detection
- **Symptom**: `SensorStatus::Degraded` for BME280
- **Cause**: Sensor returns identical values for 10+ consecutive reads
- **Check**: Sensor may be in a fault state — power cycle the sensor
- **Check**: BME280 may be in sleep mode — verify forced-mode trigger

### Wind speed always zero
- **Symptom**: `wind_speed_kmh` is always `Some(0.0)`
- **Check**: Anemometer reed switch wiring to PB0 (TIM3_CH3)
- **Check**: 10k pull-up resistor on PB0
- **Check**: GPIO interrupt configuration (rising edge)
- **Test**: Manually trigger the reed switch, check pulse counter via UART `reading` command

### Wind direction stuck at one value
- **Symptom**: `wind_dir_deg` doesn't change when vane rotates
- **Check**: AS5600 I2C communication (address 0x36)
- **Check**: Diode magnet placement and rotation axis alignment
- **Check**: AS5600 `MagnetStatus` — should report `MagnetDetected`

### Rain gauge over-counting
- **Symptom**: Rain accumulation increasing without rain
- **Cause**: Electrical noise on PB1 causing false triggers
- **Fix**: Add hardware debounce (100nF cap across reed switch)
- **Fix**: Check software debounce interval in rain gauge driver

### UV readings saturated
- **Symptom**: `uv_index` always at maximum (15.0)
- **Check**: SI1145 coefficient registers — must be written during init
- **Check**: Sensor orientation (must face upward, no obstruction)

## SD Card Issues

### SD card not detected
- **Symptom**: "No SD card inserted" in log, firmware falls back to flash storage
- **Check**: Card is fully inserted into micro-SD holder (J22)
- **Check**: PD11 detect pin — should go LOW when card is inserted
- **Check**: R27 (10kΩ pull-up) on PD11 is populated
- **Check**: Card is FAT32 formatted (SDXC cards with exFAT are not supported)

### SD card init fails
- **Symptom**: "SD card init failed" in log
- **Check**: SPI2 bus connections (PB13 SCK, PB14 MISO, PB15 MOSI, PD10 CS)
- **Check**: C38 (100nF) decoupling cap on SD card VCC
- **Check**: Card is not write-protected
- **Note**: Init uses 400 kHz SPI clock; if SPI2 bus is noisy, check signal integrity

### SD card write errors
- **Symptom**: "SD store failed" in log, data falls back to flash
- **Check**: Card has free space (FAT32 max 32 GB partition)
- **Check**: `/weather/` directory exists (created automatically on init)
- **Check**: SPI2 bus sharing with W5500 — verify CS toggling is correct
- **Recovery**: Remove card, format as FAT32, re-insert

## Communication Issues

### WiFi won't connect
- **Check**: SSID and password via UART `wifi status` command
- **Check**: WiFi signal strength — station may be too far from AP
- **Check**: 2.4 GHz only (ATWINC1500 does not support 5 GHz)
- **Retry**: WiFi uses exponential backoff (2s, 4s, 8s... up to 30s)
- **Max retries**: 5 attempts before `WifiState::Failed`
- **Recovery**: Power cycle or send BLE provisioning with new credentials

### MQTT publish failures
- **Symptom**: `MQTT publish failed` in serial log
- **Check**: Broker address and port in runtime config
- **Check**: WiFi is connected first (`wifi status`)
- **Check**: Broker authentication credentials
- **Note**: Failed messages are buffered to flash and replayed on reconnect

### BLE not discoverable
- **Check**: RN4870 BLE module is powered and RST pin (PD8) released
- **Check**: Device name in runtime config
- **Fix**: Some phones require clearing BLE cache after firmware update

### LoRa no acknowledgement
- **Check**: Frequency setting matches regional band (868 MHz EU, 915 MHz US)
- **Check**: Spreading factor and bandwidth match gateway settings
- **Check**: Antenna connection to SX1276 module
- **Check**: TX power setting (default 14 dBm)

## Power Issues

### Battery draining fast
- **Check**: Power mode via UART `status` command
- **Check**: WiFi reconnect loop (constant retries drain battery)
- **Fix**: If WiFi is unavailable, firmware should fall back to LoRa-only mode
- **Expected**: ~250 mA active, ~2 µA standby

### Won't enter deep sleep
- **Check**: Battery percentage — deep sleep triggers below 20%
- **Check**: Active WiFi connections prevent deep sleep
- **Check**: Pending OTA update blocks deep sleep

### Solar charging not working
- **Check**: Solar panel voltage (should be ~6V in direct sunlight)
- **Check**: TP4056 charge LED indicators
- **Check**: USB-C is disconnected (some TP4056 boards conflict with dual input)

## Flash Storage Issues

### "Flash store failed" errors
- **Check**: Flash partition is properly initialized
- **Check**: Available space via UART `status` command
- **Note**: Circular buffer overwrites oldest records when full

### Data corruption after power loss
- **Check**: CRC verification errors in flash records
- **Recovery**: The circular buffer skips corrupted records automatically
- **Prevention**: Ensure clean shutdown via deep sleep rather than hard power cut

## Build Issues

### Compilation fails with missing target
```bash
rustup target add thumbv7em-none-eabihf  # ARM Cortex-M4F target
cargo install probe-rs-tools  # Flashing tools
```

### Linker errors about memory
- **Check**: `memory.x` flash/RAM regions match STM32F407 (1 MB Flash, 128 KB RAM, 64 KB CCM)
- **Check**: HEAP_SIZE in `config.rs` (default 48 KB)
- **Fix**: Reduce binary size with `opt-level = "z"` and `lto = true`

## UART Console Commands

Use these for live diagnostics:

| Command | Description |
|---|---|
| `status` | Show all sensor statuses, WiFi, battery |
| `reading` | Display current weather reading |
| `config` | Show runtime configuration |
| `calibrate <sensor> <offset>` | Set calibration offset |
| `wifi status` | Show WiFi connection details |
| `dump` | Dump flash storage records |
| `reset` | Restart firmware |

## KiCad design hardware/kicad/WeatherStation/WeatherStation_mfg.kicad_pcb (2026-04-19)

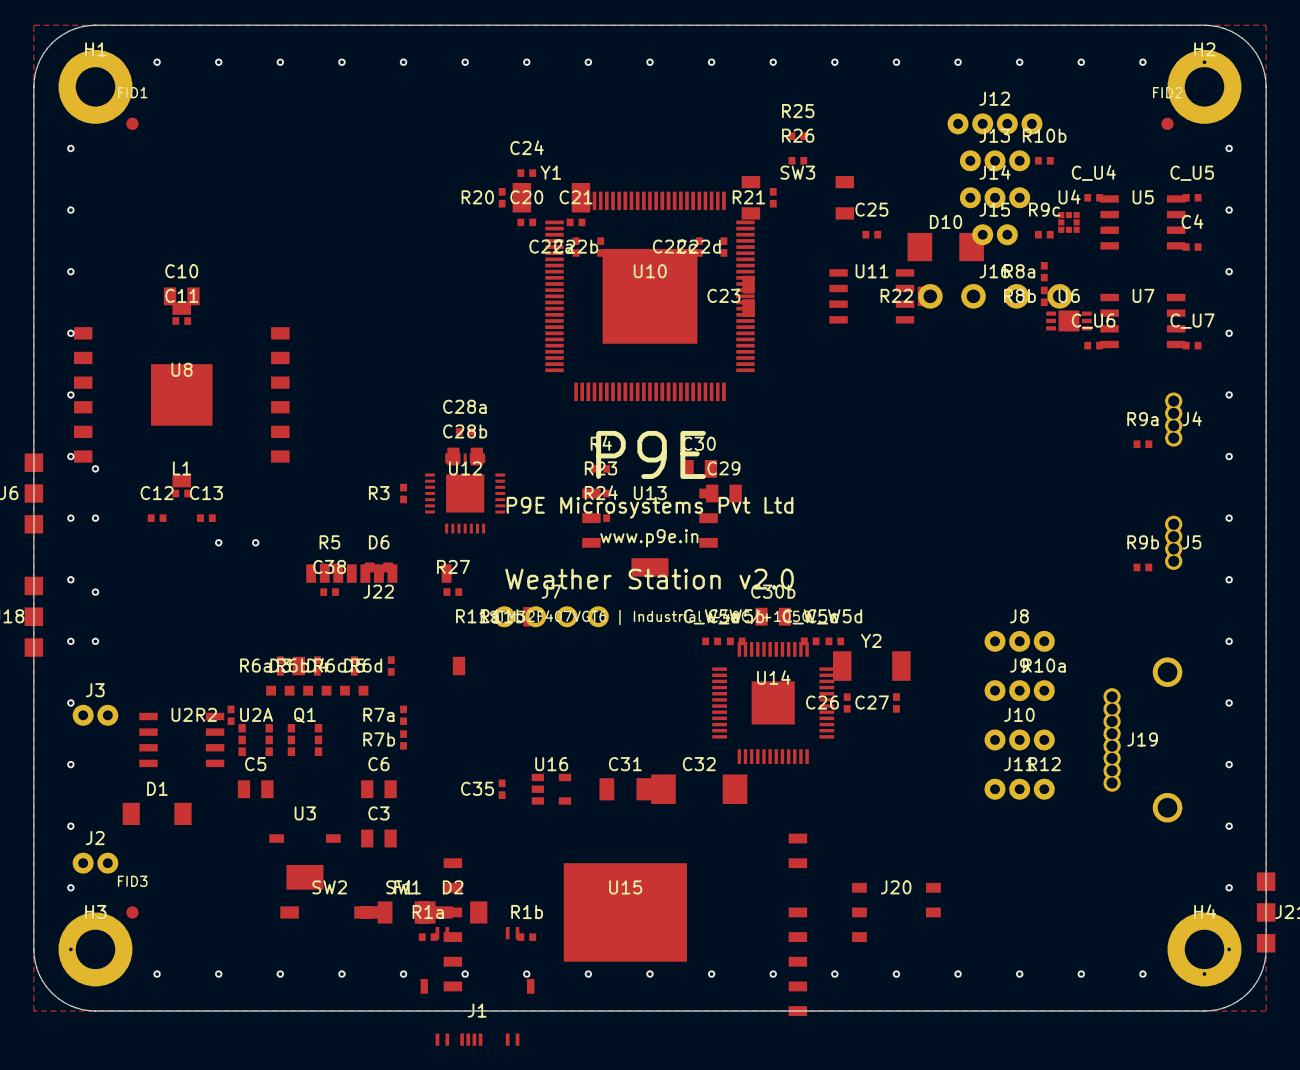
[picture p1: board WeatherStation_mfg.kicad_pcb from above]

Board: 4 copper layers, 100.0 x 80.0 mm, 124 parts (0 on the bottom side), 76 nets, no tracks yet.

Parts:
C3: 22uF; C_0805_2012Metric
C4, C35: 1uF; C_0402_1005Metric
C5, C6, C10, C28b, C30, C30b: 10uF; C_0805_2012Metric
C11, C22a, C22b, C22c, C22d, C24, C25, C28a, C38: 100nF; C_0402_1005Metric
C12: 1.5pF; C_0402_1005Metric
C13: 3.3pF; C_0402_1005Metric
C20, C21: 20pF; C_0402_1005Metric
C23, C29: 4.7uF; C_0805_2012Metric
C26, C27: 18pF; C_0402_1005Metric
C31: 100uF; C_1206_3216Metric
C32: 470uF; CP_EIA-7343-31_Kemet-D
C_U4, C_U5, C_U6, C_U7: 100nF; C_0402_1005Metric
C_W5a, C_W5b, C_W5c, C_W5d: 100nF; C_0402_1005Metric
D1: SS14; D_SMA
D2: SMAJ5.0A; D_SMA
D3: LED_Red; LED_0603_1608Metric
D4, D6: LED_Green; LED_0603_1608Metric
D5: LED_Blue; LED_0603_1608Metric
D10: SMBJ6.0CA; D_SMB
F1: 500mA; Fuse_1206_3216Metric
FID1, FID2, FID3: Fiducial; Fiducial_1mm_Mask2mm
H1, H2, H3, H4: MountingHole_M3; MountingHole_3.2mm_M3_Pad_Via
J1: USB-C; USB_C_Receptacle_GCT_USB4105
J2: SOLAR_IN; JST_PH_B2B-PH-K_1x02_P2.00mm_Vertical
J3: BATTERY; JST_PH_B2B-PH-K_1x02_P2.00mm_Vertical
J4: ANEMOMETER; RJ11_Amphenol_54601
J5: RAIN_GAUGE; RJ11_Amphenol_54601
J6: SMA_LoRa; SMA_Amphenol_132289_EdgeMount
J7: DEBUG_UART; PinHeader_1x04_P2.54mm_Vertical
J8: SOIL_MOIST_1; JST_PH_B3B-PH-K_1x03_P2.00mm_Vertical
J9: SOIL_MOIST_2; JST_PH_B3B-PH-K_1x03_P2.00mm_Vertical
J10: SOIL_TEMP; JST_PH_B3B-PH-K_1x03_P2.00mm_Vertical
J11: LEAF_WET; JST_PH_B3B-PH-K_1x03_P2.00mm_Vertical
J12: PYRANOMETER; JST_PH_B4B-PH-K_1x04_P2.00mm_Vertical
J13: PANEL_TEMP_F; JST_PH_B3B-PH-K_1x03_P2.00mm_Vertical
J14: PANEL_TEMP_B; JST_PH_B3B-PH-K_1x03_P2.00mm_Vertical
J15: POWER_PULSE; JST_PH_B2B-PH-K_1x02_P2.00mm_Vertical
J16: RS485_Bus; PhoenixContact_MC_01x04_G_3.5mm
J18: SMA_WiFi; SMA_Amphenol_132289_EdgeMount
J19: RJ45_Magjack; RJ45_Amphenol_RJHSE-5380
J20: NanoSIM; NanoSIM_Molex_78800
J21: SMA_LTE; SMA_Amphenol_132289_EdgeMount
J22: MicroSD; MicroSD_Molex_5031821852
L1: 5.6nH; L_0402_1005Metric
Q1: FS8205A; SOT-23-6
R1a, R1b: 5.1k; R_0402_1005Metric
R2: 2.2k; R_0402_1005Metric
R3, R4, R9a, R9b, R9c, R12, R20, R21, R25, R26, R27: 10k; R_0402_1005Metric
R5: 330R; R_0402_1005Metric
R6a, R6b, R6c, R6d: 1k; R_0402_1005Metric
R7a, R7b: 100k; R_0402_1005Metric
R8a, R8b, R10a, R10b: 4.7k; R_0402_1005Metric
R11a, R11b, R23, R24: 100R; R_0402_1005Metric
R22: 120R; R_0402_1005Metric
SW1: BOOT; SW_SPST_PTS645
SW2: RESET; SW_SPST_PTS645
SW3: MODE_DIP; SW_DIP_SPSTx02_Slide_6.7x6.64mm_W8.61mm_P2.54mm
U2: TP4056; SOIC-8_3.9x4.9mm_P1.27mm
U2A: DW01A; SOT-23-6
U3: AMS1117-3.3; SOT-223-3_TabPin2
U4: BME280; Bosch_BME280_LGA-8_2.5x2.5mm
U5: AS5600; SOIC-8_3.9x4.9mm_P1.27mm
U6: SI1145; QFN-10-1EP_3x3mm_P0.6mm
U7: BH1750FVI; SOIC-8_3.9x4.9mm_P1.27mm
U8: SX1276/RFM95W; RFM95W
U10: STM32F407VGT6; LQFP-100_14x14mm_P0.5mm
U11: MAX3485ESA+; SOIC-8_3.9x4.9mm_P1.27mm
U12: ATWINC1500; QFN-28-1EP_5x5mm_P0.5mm_EP3.1x3.1mm
U13: RN4870-I/RM; RN4870_11.5x8mm
U14: W5500; LQFP-48_7x7mm_P0.5mm
U15: SIM7600E-H; SIM7600EH_LCC
U16: TPS7A2033; SOT-23-5
Y1: 8MHz; Crystal_SMD_HC49-SD
Y2: 25MHz; Crystal_SMD_HC49-SD

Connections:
+3V3: C3.1, C4.1, C10.1, C11.1, C22a.1, C22b.1, C22c.1, C22d.1, C23.1, C25.1, C28a.1, C28b.1, C29.1, C30.1, C30b.1, C35.1, C38.1, C_U4.1, C_U5.1, C_U6.1, C_U7.1, C_W5a.1, C_W5b.1, C_W5c.1, C_W5d.1, D5.2, J4.3, J5.3, J7.3, J8.1, J9.1, J10.1, J11.1, J12.1, J13.1, J14.1, J22.4, R3.1, R4.1, R6c.1, R8a.1, R8b.1, R9a.1, R9b.1, R9c.1, R10a.1, R10b.1, R20.1, R27.1, U3.2, U4.5, U4.8, U5.7, U5.8, U6.6, U7.1, U7.8, U8.14, U10.7, U10.47, U10.72, U10.99, U11.8, U12.14, U13.5, U14.12, U16.1, U16.3
ANEM_SIG: J4.1, R9a.2
BLE_RST: R4.2, U10.63, U13.3
BLE_RX: R24.1, U10.30, U13.2
BLE_STATUS: U10.64, U13.4
BLE_TX: R23.1, U10.29, U13.1
BOOT0: R21.1, SW1.1
CELL_DTR: U10.62, U15.5
CELL_PWRKEY: U10.60, U15.3
CELL_RI: U10.1, U15.6
CELL_RX: U10.79, U15.1
CELL_STATUS: U10.61, U15.4
CELL_TX: U10.78, U15.2
CHRG_STAT: D3.2, R6a.1, U2.1
ETH_CS: U10.31, U14.4
ETH_INT: U10.59, U14.6
ETH_RST: U10.58, U14.5
ETH_RXN: J19.6, U14.28
ETH_RXP: J19.3, U14.27
ETH_TXN: J19.2, U14.26
ETH_TXP: J19.1, U14.25
ETH_XTAL1: C26.1, U14.35, Y2.1
ETH_XTAL2: C27.1, U14.36, Y2.2
GND: C3.2, C4.2, C5.2, C6.2, C10.2, C11.2, C12.2, C13.2, C20.2, C21.2, C22a.2, C22b.2, C22c.2, C22d.2, C23.2, C24.2, C25.2, C26.2, C27.2, C28a.2, C28b.2, C29.2, C30.2, C30b.2, C31.2, C32.2, C35.2, C38.2, C_U4.2, C_U5.2, C_U6.2, C_U7.2, C_W5a.2, C_W5b.2, C_W5c.2, C_W5d.2, D2.2, D3.1, D4.1, D5.1, D6.1, H1.1, H2.1, H3.1, H4.1, J1.A1, J1.A12, J1.B1, J1.B12, J1.S1, J1.S2, J2.2, J3.2, J4.2, J5.2, J6.2, J6.3, J7.4, J8.2, J9.2, J10.2, J11.2, J12.2, J13.2, J14.2, J15.2, J16.3, J16.4, J18.2, J18.3, J19.S1, J19.S2, J20.C5, J21.2, J21.3, J22.3, J22.6, J22.S1, J22.S2, Q1.1, Q1.2, R1a.1, R1b.1, R2.2, R7b.2, R12.2, R21.2, R25.2, R26.2, SW1.2, SW2.2, SW3.3, SW3.4, U2.5, U2.7, U2A.2, U3.1, U4.1, U4.3, U5.3, U6.7, U6.11, U7.2, U7.3, U8.1, U8.13, U8.15, U10.48, U10.73, U10.100, U10.101, U11.5, U12.21, U12.29, U13.6, U13.7, U14.24, U14.49, U15.8, U15.GND, U16.2
HSE_IN: C20.1, U10.90, Y1.1
HSE_OUT: C21.1, U10.91, Y1.2
I2C1_SCL: R8b.2, U4.7, U5.2, U6.2, U7.6, U10.27
I2C1_SDA: R8a.2, U4.6, U5.1, U6.1, U7.4, U10.26
LEAF_WET_SIG: J11.3, R12.1
LORA_ANT: C12.1, L1.1, U8.12
LORA_CS: U8.5, U10.83
LORA_DIO0: U8.7, U10.95
LORA_RST: U8.6, U10.94
LTE_ANT: J21.1, U15.9
MODE_SW1: R25.1, SW3.1
MODE_SW2: R26.1, SW3.2
NRST: C24.1, R20.2, SW2.1, U10.93
PANEL_TEMP1_DATA: J13.3, R10b.2
POWER_PULSE: J15.1, R9c.2
RAIN_SIG: J5.1, R9b.2
RS485_A: D10.1, J16.1, R22.1, U11.6
RS485_B: D10.2, J16.2, R22.2, U11.7
RS485_DE: U11.2, U11.3
SD_CS: J22.1, U10.65
SD_DET: J22.CD, R27.2, U10.66
SIM_CLK: J20.C3, U15.12
SIM_DATA: J20.C7, U15.13
SIM_RST: J20.C2, U15.11
SIM_VCC: J20.C1, U15.10
SOIL_TEMP_DATA: J10.3, R10a.2
SPI1_MISO: U8.3, U10.25
SPI1_MOSI: U8.2, U10.23
SPI1_SCK: U8.4, U10.24
SPI2_MISO: J22.7, U10.33, U14.2
SPI2_MOSI: J22.2, U10.34, U14.3
SPI2_SCK: J22.5, U10.32, U14.1
SPI3_MISO: U10.52, U12.2
SPI3_MOSI: U10.53, U12.3
SPI3_SCK: U10.51, U12.1
STATUS_LED: D6.2, R5.1
UART1_RX: J7.2, R11b.1
UART1_TX: J7.1, R11a.1
UART2_RX: U10.82, U11.1
UART2_TX: U10.81, U11.4
USB_DM: J1.A7, U10.88
USB_DP: J1.A6, U10.87
VBAT: C6.1, J3.1, Q1.5, Q1.6, R7a.1, U2.4, U2A.5, U2A.6, U3.3
VBAT_SENSE: R7a.2, R7b.1
VBAT_SIM: C31.1, C32.1, U15.7, U16.5
VBUS_5V: C5.1, D1.2, D2.1, F1.1, F1.2, J1.A4, J1.A9, J1.B4, J1.B9, U2.3
VSOLAR: D1.1, J2.1
WIFI_ANT: J18.1, U12.28
WIFI_CS: U10.3, U12.4
WIFI_EN: R3.2, U10.2, U10.6, U12.7
WIFI_IRQ: U10.5, U12.6
WIFI_RST: U10.4, U12.5

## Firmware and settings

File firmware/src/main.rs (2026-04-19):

//! Weather Station Firmware — STM32F407
//!
//! A production-grade weather station firmware targeting the STM32F407VGT6 MCU.
//! Single-MCU architecture with dedicated connectivity modules:
//! ATWINC1500 (WiFi/SPI3), RN4870 (BLE/USART3), W5500 (Ethernet/SPI2),
//! SIM7600E-H (Cellular/UART4).
//!
//! Reads environmental sensors and transmits data via WiFi, BLE, LoRa,
//! UART, MQTT, HTTP, Modbus RS485, and optionally Ethernet/Cellular.
//!
//! # Module Organization
//!
//! - `config` — Pin assignments, constants, runtime configuration
//! - `error` — Unified error types
//! - `drivers` — Sensor drivers (BME280, wind, rain, UV, light) + MCU/comm modules
//! - `comms` — Communication channels (WiFi, BLE, LoRa, UART, MQTT, HTTP, Modbus)
//! - `core` — Scheduler, data pipeline, power management, OTA
//! - `storage` — Flash circular buffer, NVS access
//! - `utils` — Ring buffer, CRC, formatting helpers

#![no_std]
#![no_main]

extern crate alloc;

#[macro_use]
mod utils;

use core::sync::atomic::{AtomicBool, Ordering};

mod comms;
mod config;
mod core;
mod drivers;
mod error;
mod industry;
mod storage;

use crate::comms::ble::BleServer;
use crate::comms::http::HttpServer;
use crate::comms::modbus_rtu::ModbusRtuSlave;
use crate::comms::mqtt::MqttClient;
use crate::comms::uart_console::UartConsole;
use crate::comms::wifi::WifiManager;
use crate::config::RuntimeConfig;
use crate::core::data_pipeline::{DataPipeline, RawSensorData, WeatherReading};
use crate::core::mode_manager::ModeManager;
use crate::core::ota::OtaManager;
use crate::core::power::PowerManager;
use crate::core::scheduler::{Scheduler, TaskId};
use crate::drivers::SensorStatusMap;
use crate::storage::flash::FlashStorage;
use crate::utils::ring_buffer::RingBuffer;

/// Global flag: set by watchdog or panic handler to signal error recovery.
static SYSTEM_ERROR: AtomicBool = AtomicBool::new(false);

/// Heap allocator for `alloc` support.
#[global_allocator]
static ALLOCATOR: embedded_alloc::LlffHeap = embedded_alloc::LlffHeap::empty();

/// Entry point.
#[cortex_m_rt::entry]
fn main() -> ! {
    // ── Phase 1: Hardware Initialization ──────────────────────────

    // SAFETY: Called exactly once, before any heap allocations, on the
    // single-threaded boot path. The HEAP static is only accessed here
    // and its lifetime is 'static, satisfying the allocator contract.
    static mut HEAP: [u8; config::HEAP_SIZE] = [0; config::HEAP_SIZE];
    unsafe { ALLOCATOR.init(HEAP.as_mut_ptr(), config::HEAP_SIZE) };

    // Initialize logging via defmt-rtt
    log::info!("========================================");
    log::info!("  Weather Station Firmware v{}", config::FIRMWARE_VERSION);
    log::info!("  STM32F407 | Rust Embedded");
    log::info!("========================================");

    // Load configuration from NVS (or use defaults)
    let mut runtime_config = RuntimeConfig::default();
    runtime_config.validate();
    log::info!("Config loaded: device_id={}", runtime_config.device_id);

    // ── Phase 2: Peripheral Initialization ────────────────────────

    // In real firmware:
    // let dp = stm32f4xx_hal::pac::Peripherals::take().unwrap();
    // let cp = cortex_m::Peripherals::take().unwrap();
    //
    // // Configure clocks: HSE 8MHz -> PLL -> 168 MHz SYSCLK
    // let rcc = dp.RCC.constrain();
    // let clocks = rcc.cfgr
    //     .use_hse(8.MHz())
    //     .sysclk(168.MHz())
    //     .pclk1(42.MHz())
    //     .pclk2(84.MHz())
    //     .freeze();
    //
    // // GPIO ports
    // let gpioa = dp.GPIOA.split();
    // let gpiob = dp.GPIOB.split();
    // let gpioc = dp.GPIOC.split();
    // let gpiod = dp.GPIOD.split();
    // let gpioe = dp.GPIOE.split();
    //
    // // I2C1 (PB6 SCL, PB7 SDA) — sensors
    // let i2c1 = I2c::new(dp.I2C1, (gpiob.pb6, gpiob.pb7), 400.kHz(), &clocks);
    //
    // // SPI1 (PA4-PA7) — SX1276 LoRa
    // let spi1 = Spi::new(dp.SPI1, (gpioa.pa5, gpioa.pa6, gpioa.pa7), ...);
    // let lora_cs = gpioa.pa4.into_push_pull_output();
    //
    // // SPI3 (PB3-PB5) — ATWINC1500 WiFi
    // let spi3 = Spi::new(dp.SPI3, (gpiob.pb3, gpiob.pb4, gpiob.pb5), ...);
    // let wifi_cs = gpioe.pe3.into_push_pull_output();
    // let wifi_rst = gpioe.pe4.into_push_pull_output();
    // let wifi_en = gpioe.pe6.into_push_pull_output();
    //
    // // USART2 (PA2/PA3) — RS485 Modbus, PA1 = DE
    // // USART3 (PB10/PB11) — RN4870 BLE
    // // USART1 (PA9/PA10) — Debug console
    //
    // // ADC1 — battery (PA0), wind (PC0), PM2.5 (PC1), soil (PC2/PC3)
    // // TIM3 — wind/rain pulse (PB0/PB1)
    // // GPIO — LEDs (PD0-PD2), DIP switch (PE0-PE1)
    // // IWDG — watchdog
    log::info!("STM32F407 HAL peripherals initialized");

    // ── Phase 3: Sensor Initialization ────────────────────────────

    let sensor_status = init_sensors();
    log::info!("Sensors initialized: {:?}", sensor_status);

    // ── Phase 4: Communication Initialization ─────────────────────

    // ATWINC1500 WiFi on SPI3
    // In real firmware: let atwinc = Atwinc1500::new(spi3, wifi_cs, wifi_rst, wifi_en);
    let atwinc = drivers::atwinc1500::Atwinc1500::new_default();
    let mut wifi = WifiManager::new(atwinc);
    wifi.set_credentials(
        runtime_config.wifi_ssid.as_str(),
        runtime_config.wifi_password.as_str(),
    );
    if let Err(e) = wifi.init() {
        log::warn!("WiFi init failed: {} — will retry later", e);
    }

    // RN4870 BLE on USART3
    let mut ble = BleServer::new(runtime_config.device_name.as_str());
    if let Err(e) = ble.init() {
        log::warn!("BLE init failed: {}", e);
    }

    // LoRa initialized via SPI1 (would need real SPI handle)
    // let mut lora = LoraRadio::new(spi1, lora_cs, rst_pin, runtime_config.device_id);

    let device_id_str: heapless::String<16> =
        format_heapless!("ws-{:04X}", runtime_config.device_id);
    let mut mqtt = MqttClient::new(device_id_str.as_str());
    mqtt.configure(
        runtime_config.mqtt_broker.as_str(),
        runtime_config.mqtt_port,
        runtime_config.mqtt_use_tls,
        runtime_config.mqtt_username.as_str(),
        runtime_config.mqtt_password.as_str(),
    );

    let mut http = HttpServer::new();
    let uart_console = UartConsole::new();
    uart_console.init();

    let mut ota = OtaManager::new();
    if let Err(e) = ota.validate_boot() {
        log::warn!("OTA boot validation failed: {} — may rollback", e);
    }

    // Optional: W5500 Ethernet on SPI2
    #[cfg(feature = "ethernet")]
    let mut _ethernet = {
        log::info!("Ethernet module enabled (W5500 on SPI2)");
        // In real firmware: let w5500 = W5500::new(spi2, eth_cs, eth_rst);
    };

    // Optional: SIM7600E-H Cellular on UART4
    #[cfg(feature = "cellular")]
    let mut _cellular = {
        log::info!("Cellular module enabled (SIM7600 on UART4)");
        // In real firmware: let sim7600 = Sim7600::new(uart4);
    };

    log::info!("Communication channels initialized");

    // ── Phase 5: Core Systems ─────────────────────────────────────

    let mut scheduler = Scheduler::new();
    let mut pipeline = DataPipeline::new();
    pipeline.set_calibration(
        runtime_config.cal_temp_offset,
        runtime_config.cal_humidity_offset,
        runtime_config.cal_pressure_offset,
        runtime_config.cal_wind_dir_offset,
    );

    let mut power = PowerManager::new();
    let mut flash_storage = FlashStorage::new();
    if let Err(e) = flash_storage.init() {
        log::error!("Flash storage init failed: {} — data will not persist", e);
    }

    // ── Phase 5a: SD Card Storage ──────────────────────────────

    #[cfg(feature = "sdcard")]
    let (mut sd_driver, mut sd_storage) = {
        log::info!("SD card module enabled (SPI2, CS=PD10)");
        let mut driver = drivers::sdcard::SdCardDriver::new();
        let mut storage = storage::sdcard::SdCardStorage::new();
        // In real firmware, is_inserted() reads PD11 GPIO;
        // for development, simulate card present
        driver.set_inserted(true);
        if driver.is_inserted() {
            if let Err(e) = driver.init() {
                log::warn!("SD card init failed: {}", e);
            } else if let Err(e) = storage.init(&mut driver) {
                log::warn!("SD card filesystem init failed: {}", e);
            } else {
                log::info!("SD card ready: {} MB", driver.capacity_mb());
            }
        } else {
            log::info!("No SD card inserted — using flash storage only");
        }
        (driver, storage)
    };

    let mut reading_buffer: RingBuffer<WeatherReading, 64> = RingBuffer::new();
    let mut latest_reading = WeatherReading::default();
    let raw_data = RawSensorData::default();

    // ── Phase 5b: Industry Module Initialization ──────────────────

    #[cfg(feature = "agriculture")]
    let mut ag_analytics = {
        log::info!("Agriculture module enabled");
        industry::agriculture::AgricultureAnalytics::new(runtime_config.gdd_base_temp_c)
    };
    #[cfg(feature = "agriculture")]
    let mut ag_reading = industry::agriculture::AgricultureReading::default();

    #[cfg(feature = "solar")]
    let mut solar_analytics = {
        log::info!("Solar module enabled");
        industry::solar::SolarAnalytics::new(
            runtime_config.panel_wp,
            runtime_config.panel_area_m2,
        )
    };
    #[cfg(feature = "solar")]
    let mut solar_reading = industry::solar::SolarReading::default();

    #[cfg(feature = "india")]
    let mut india_analytics = {
        log::info!("India regional module enabled (region: {:?})", runtime_config.india_region);
        industry::india::IndiaAnalytics::new(
            runtime_config.india_gdd_base_temp_c,
            runtime_config.india_region,
        )
    };
    #[cfg(feature = "india")]
    let mut india_reading = industry::india::IndiaReading::default();

    // ── Phase 5c: SCADA/Hybrid Mode ──────────────────────────────

    let mut modbus_slave = {
        log::info!("SCADA module enabled (mode: {})", runtime_config.operating_mode.as_str());
        let mut slave = ModbusRtuSlave::new(runtime_config.modbus_slave_addr);
        if let Err(e) = slave.init() {
            log::error!("Modbus RS485 init failed: {}", e);
        }
        slave
    };

    let mut mode_manager = ModeManager::new(runtime_config.operating_mode);

    log::info!(
        "Operating mode: {} | Cloud: {} | SCADA: {}",
        runtime_config.operating_mode.as_str(),
        if runtime_config.operating_mode.cloud_enabled() { "ON" } else { "OFF" },
        if runtime_config.operating_mode.scada_enabled() { "ON" } else { "OFF" },
    );

    log::info!("Core systems initialized — entering main loop");

    // ── Phase 6: Main Loop ────────────────────────────────────────

    let mut uptime_ms: u64 = 0;

    loop {
        scheduler.update_time(uptime_ms);

        // Limit tasks per tick to prevent runaway scheduling if many tasks become due at once
        let mut tasks_this_tick = 0u8;
        const MAX_TASKS_PER_TICK: u8 = 8;
        while tasks_this_tick < MAX_TASKS_PER_TICK {
            let Some(task_id) = scheduler.next_due_task() else {
                break;
            };
            tasks_this_tick += 1;
            match task_id {
                TaskId::ReadBme280 => {
                    // In real firmware: read from BME280 driver
                    // let bme_reading = bme280.read()?;
                    // raw_data.temperature_c = Some(bme_reading.temperature_c);
                    log::debug!("Task: ReadBme280");
                }

                TaskId::ReadWind => {
                    log::debug!("Task: ReadWind");
                }

                TaskId::ReadRain => {
                    log::debug!("Task: ReadRain");
                }

                TaskId::ReadUvLight => {
                    log::debug!("Task: ReadUvLight");
                }

                TaskId::ProcessData => {
                    latest_reading = pipeline.process(&raw_data, uptime_ms);

                    if !reading_buffer.push(latest_reading.clone()) {
                        log::warn!("Reading buffer full — dropping oldest");
                    }

                    // Store to SD card (primary) with flash fallback
                    #[cfg(feature = "sdcard")]
                    {
                        if sd_driver.is_inserted() {
                            if let Err(e) = sd_storage.store(&latest_reading) {
                                log::warn!("SD store failed: {} — falling back to flash", e);
                                let _ = flash_storage.store(&latest_reading);
                            }
                        } else {
                            let _ = flash_storage.store(&latest_reading);
                        }
                    }
                    #[cfg(not(feature = "sdcard"))]
                    {
                        if let Err(e) = flash_storage.store(&latest_reading) {
                            log::warn!("Flash store failed: {}", e);
                        }
                    }

                    http.update_reading(&latest_reading);
                    log::debug!("Task: ProcessData — reading buffered");
                }

                TaskId::PublishTelemetry => {
                    if wifi.is_connected() {
                        if let Err(e) = mqtt.publish_telemetry(&latest_reading) {
                            log::warn!("MQTT publish failed: {} — buffering to flash", e);
                            if let Err(e2) = flash_storage.store(&latest_reading) {
                                log::error!("Flash fallback also failed: {}", e2);
                            }
                        }
                    }
                    log::debug!("Task: PublishTelemetry");
                }

                TaskId::PublishStatus => {
                    let battery = power.battery();
                    if mqtt.is_connected() {
                        if let Err(e) = mqtt.publish_status(
                            uptime_ms / 1000,
                            battery.voltage_v,
                            battery.percentage,
                            wifi.rssi().unwrap_or(0),
                            0, // free heap — from allocator stats in real firmware
                            flash_storage.usage_pct(),
                        ) {
                            log::warn!("Status publish failed: {}", e);
                        }
                    }
                    log::debug!("Task: PublishStatus");
                }

                TaskId::UpdateBle => {
                    if let Err(e) = ble.update_reading(&latest_reading) {
                        log::debug!("BLE update skipped: {}", e);
                    }

                    if let Some(wifi_config) = ble.take_wifi_config() {
                        log::info!("BLE: WiFi provisioning received");
                        wifi.set_credentials(
                            wifi_config.ssid.as_str(),
                            wifi_config.password.as_str(),
                        );
                        if let Err(e) = wifi.init() {
                            log::warn!("WiFi re-init after BLE provisioning failed: {}", e);
                        }
                    }
                    log::debug!("Task: UpdateBle");
                }

                TaskId::CheckOta => {
                    if wifi.is_connected() && ota.should_check(uptime_ms) {
                        if let Err(e) = ota.check_for_update(uptime_ms) {
                            log::warn!("OTA check failed: {}", e);
                        }
                    }
                    log::debug!("Task: CheckOta");
                }

                TaskId::FeedWatchdog => {
                    // In real firmware: wdt.feed() via IWDG
                }

                TaskId::ReadBattery => {
                    // In real firmware: power.update_battery(adc.read(PA0));
                    log::debug!("Task: ReadBattery");
                }

                // ── Agriculture Tasks ─────────────────────────
                #[cfg(feature = "agriculture")]
                TaskId::ReadAgriculture => {
                    // In real firmware: read soil moisture, soil temp, leaf wetness
                    log::debug!("Task: ReadAgriculture");
                }

                #[cfg(feature = "agriculture")]
                TaskId::ProcessAgriculture => {
                    ag_reading = ag_analytics.process(
                        latest_reading.temperature_c,
                        latest_reading.humidity_pct,
                        latest_reading.wind_speed_kmh,
                        latest_reading.pressure_hpa,
                        latest_reading.rain_rate_mm_hr,
                        latest_reading.light_lux.map(|lux| lux * 0.0079), // rough lux→W/m²
                        None, // soil moisture shallow — from sensor in real firmware
                        None, // soil moisture deep
                        None, // soil temp
                        None, // leaf wetness
                        0,    // leaf wet duration
                    );
                    latest_reading.agriculture = Some(ag_reading.clone());

                    // Check alerts and publish
                    let alerts = ag_analytics.check_alerts(&ag_reading, uptime_ms);
                    for alert in &alerts {
                        if mqtt.is_connected() {
                            if let Err(e) = mqtt.publish_industry_alert(alert) {
                                log::warn!("Agriculture alert publish failed: {}", e);
                            }
                        }
                    }

                    if mqtt.is_connected() {
                        if let Err(e) = mqtt.publish_agriculture(&ag_reading) {
                            log::warn!("Agriculture telemetry publish failed: {}", e);
                        }
                    }
                    log::debug!("Task: ProcessAgriculture");
                }

                // ── Solar Tasks ───────────────────────────────
                #[cfg(feature = "solar")]
                TaskId::ReadSolar => {
                    // In real firmware: read pyranometer, panel temp
                    log::debug!("Task: ReadSolar");
                }

                #[cfg(feature = "solar")]
                TaskId::ProcessSolar => {
                    solar_reading = solar_analytics.process(
                        None, // irradiance — from pyranometer in real firmware
                        None, // panel temp front
                        None, // panel temp back
                        latest_reading.temperature_c,
                        uptime_ms,
                    );
                    latest_reading.solar = Some(solar_reading.clone());

                    // Detect rain for soiling reset
                    if let Some(rate) = latest_reading.rain_rate_mm_hr {
                        if rate > 1.0 {
                            solar_analytics.rain_detected();
                        }
                    }

                    // Check alerts and publish
                    let alerts = solar_analytics.check_alerts(&solar_reading, uptime_ms);
                    for alert in &alerts {
                        if mqtt.is_connected() {
                            if let Err(e) = mqtt.publish_industry_alert(alert) {
                                log::warn!("Solar alert publish failed: {}", e);
                            }
                        }
                    }

                    if mqtt.is_connected() {
                        if let Err(e) = mqtt.publish_solar(&solar_reading) {
                            log::warn!("Solar telemetry publish failed: {}", e);
                        }
                    }
                    log::debug!("Task: ProcessSolar");
                }

                // ── India Regional Tasks ────────────────────────
                #[cfg(feature = "india")]
                TaskId::ReadIndia => {
                    // In real firmware: read PM2.5 sensor
                    log::debug!("Task: ReadIndia");
                }

                #[cfg(feature = "india")]
                TaskId::ProcessIndia => {
                    // Month would come from RTC in real firmware; use 6 (June) as placeholder
                    let month: u8 = 6;
                    india_reading = india_analytics.process(
                        latest_reading.temperature_c,
                        latest_reading.humidity_pct,
                        latest_reading.wind_speed_kmh,
                        latest_reading.pressure_hpa,
                        latest_reading.rain_rate_mm_hr,
                        None,  // PM2.5 — from sensor in real firmware
                        month,
                        uptime_ms,
                    );
                    latest_reading.india = Some(india_reading.clone());

                    // Check alerts and publish
                    let alerts = india_analytics.check_alerts(&india_reading, uptime_ms);
                    for alert in &alerts {
                        if mqtt.is_connected() {
                            if let Err(e) = mqtt.publish_industry_alert(alert) {
                                log::warn!("India alert publish failed: {}", e);
                            }
                        }
                    }

                    if mqtt.is_connected() {
                        if let Err(e) = mqtt.publish_india(&india_reading) {
                            log::warn!("India telemetry publish failed: {}", e);
                        }
                    }
                    log::debug!("Task: ProcessIndia");
                }
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

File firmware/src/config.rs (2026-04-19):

/// Firmware configuration constants and runtime config.
///
/// All hardware pin assignments, I2C addresses, timing intervals,
/// calibration constants, and validation ranges are defined here
/// as named constants. Runtime-configurable values are stored in
/// [`RuntimeConfig`] and persisted in NVS flash.
///
/// # Industrial-Grade Component Selection
///
/// All components are selected for the industrial temperature range
/// (-40°C to +85°C) and harsh outdoor environments:
///
/// | Component | Industrial Part | Temp Range | Notes |
/// |-----------|----------------|------------|-------|
/// | MCU | STM32F407VGT6 | -40°C to +105°C | ARM Cortex-M4F, 168 MHz |
/// | WiFi Module | ATWINC1500-MR210PB | -40°C to +85°C | SPI, integrated TCP/IP |
/// | BLE Module | RN4870-I/RM | -40°C to +85°C | UART, BLE 5.0, integrated GATT |
/// | Temp/Hum/Pressure | BME280 (Bosch) | -40°C to +85°C | Automotive-qualified available |
/// | Wind Direction | AS5600-ASOM | -40°C to +85°C | Industrial magnetic encoder |
/// | UV Sensor | SI1145-A10-GMR | -40°C to +85°C | Industrial UV/ALS/proximity |
/// | Light Sensor | BH1750FVI-TR | -40°C to +85°C | Industrial ALS |
/// | PM2.5 Sensor | GP2Y1014AU0F | -10°C to +65°C | Upgraded from GP2Y1010AU0F |
/// | LoRa Transceiver | SX1276 (Semtech) | -40°C to +85°C | Industrial ISM radio |
/// | Soil Temp | DS18B20**Z** | -55°C to +125°C | Industrial 1-Wire |
/// | Soil Moisture | Capacitive (SEN0193) | -40°C to +85°C | No corrosion |
/// | Voltage Regulator | TPS63020 | -40°C to +85°C | Wide input buck-boost |
/// | TVS/ESD Protection | TPD4E05U06 | -40°C to +125°C | On all external lines |
/// | Conformal Coating | Dow Corning 1-2577 | -65°C to +200°C | Moisture/salt spray |
/// | RS485 Transceiver | MAX3485ESA+ | -40°C to +85°C | Half-duplex, 10 Mbps |
/// | RS485 TVS | SMBJ6.0CA | -40°C to +125°C | Bidirectional TVS on A/B |
/// | RS485 Connector | Phoenix MC 4-pin | -40°C to +105°C | Pluggable terminal block |
///
/// IP65/IP67-rated enclosure with UV-stabilized polycarbonate recommended.

use serde::{Deserialize, Serialize};

// ---------- Hardware Pin Assignments (STM32F407VGT6) ----------

/// I2C1 bus pins (PB7 SDA, PB6 SCL) — sensor bus
pub const I2C_SDA_PIN: u8 = 23; // PB7
pub const I2C_SCL_PIN: u8 = 22; // PB6
pub const I2C_FREQ_HZ: u32 = 400_000;

/// SPI1 bus pins (LoRa SX1276)
pub const SPI_MOSI_PIN: u8 = 7;  // PA7
pub const SPI_MISO_PIN: u8 = 6;  // PA6
pub const SPI_SCK_PIN: u8 = 5;   // PA5
pub const LORA_CS_PIN: u8 = 4;   // PA4
pub const LORA_RST_PIN: u8 = 36; // PC4
pub const LORA_DIO0_PIN: u8 = 37; // PC5

/// GPIO interrupt pins (TIM3 channels)
pub const WIND_SPEED_PIN: u8 = 16; // PB0
pub const RAIN_GAUGE_PIN: u8 = 17; // PB1

/// ADC1 pins
pub const BATTERY_ADC_PIN: u8 = 0; // PA0

/// USART1 pins — debug console
pub const UART_TX_PIN: u8 = 9;  // PA9
pub const UART_RX_PIN: u8 = 10; // PA10
pub const UART_BAUD_RATE: u32 = 115_200;

/// Status LEDs
pub const LED_PIN: u8 = 48; // PD0

// ---------- I2C Addresses ----------

pub const BME280_ADDR: u8 = 0x76;
pub const AS5600_ADDR: u8 = 0x36;
pub const SI1145_ADDR: u8 = 0x60;
pub const BH1750_ADDR: u8 = 0x23;

// ---------- Sensor Calibration ----------

/// Wind speed: pulses per revolution
pub const WIND_PULSES_PER_REV: f32 = 1.0;
/// Wind speed factor: km/h per pulse per second
pub const WIND_SPEED_FACTOR: f32 = 2.4;
/// Rain gauge: mm per tip
pub const RAIN_MM_PER_TIP: f32 = 0.2;

// ---------- Sensor Validation Ranges ----------

pub const TEMP_MIN_C: f32 = -40.0;
pub const TEMP_MAX_C: f32 = 85.0;
pub const HUMIDITY_MIN_PCT: f32 = 0.0;
pub const HUMIDITY_MAX_PCT: f32 = 100.0;
pub const PRESSURE_MIN_HPA: f32 = 300.0;
pub const PRESSURE_MAX_HPA: f32 = 1100.0;
pub const WIND_SPEED_MAX_KMH: f32 = 200.0;
pub const RAIN_MAX_MM_HR: f32 = 500.0;
pub const UV_INDEX_MAX: f32 = 15.0;
pub const LIGHT_MAX_LUX: f32 = 120_000.0;

// ---------- EMA Filter Coefficients ----------

pub const EMA_ALPHA_TEMPERATURE: f32 = 0.3;
pub const EMA_ALPHA_HUMIDITY: f32 = 0.3;
pub const EMA_ALPHA_PRESSURE: f32 = 0.2;
pub const EMA_ALPHA_WIND_SPEED: f32 = 0.7;
pub const EMA_ALPHA_WIND_DIR: f32 = 0.5;
pub const EMA_ALPHA_UV: f32 = 0.4;
pub const EMA_ALPHA_LIGHT: f32 = 0.4;

// ---------- Stuck Sensor Detection ----------

pub const STUCK_SENSOR_THRESHOLD: u32 = 10;

// ---------- Power Management ----------

pub const BATTERY_FULL_V: f32 = 4.2;
pub const BATTERY_EMPTY_V: f32 = 3.0;
pub const BATTERY_LOW_THRESHOLD_PCT: u8 = 20;
pub const BATTERY_CRITICAL_V: f32 = 3.3;
pub const ADC_VREF: f32 = 3.3;
pub const ADC_RESOLUTION: u16 = 4095;
pub const BATTERY_DIVIDER_RATIO: f32 = 2.0;

// ---------- LoRa Configuration ----------

pub const LORA_FREQUENCY_HZ: u32 = 868_000_000; // EU868
pub const LORA_SPREADING_FACTOR: u8 = 7;
pub const LORA_BANDWIDTH_HZ: u32 = 125_000;
pub const LORA_TX_POWER_DBM: i8 = 14;
pub const LORA_CODING_RATE: u8 = 5; // 4/5

// ---------- Timing ----------
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

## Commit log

2026-02-27 Add ESP32-S3 weather station firmware in Rust with full documentation
    Complete weather station firmware implementation targeting the ESP32-S3 MCU:
    Documentation:
    - README with architecture overview, MCU selection rationale, build instructions
    - ARCHITECTURE.md: layered system design, dual-core task allocation, data flow
    - REQUIREMENTS.md: functional and non-functional requirements specification
    - API.md: MQTT topics, HTTP REST endpoints, BLE GATT profile, UART commands, LoRa packet format
    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
2026-02-27 Improve code quality and add missing documentation
    - Extract duplicated HeaplessWriter to shared utils/fmt.rs with format_heapless! macro
    - Replace all silent `let _ = Result` patterns with explicit error logging
    - Add SAFETY docs for unsafe blocks in main.rs
    - Replace 20+ magic numbers with named constants in config.rs
    - Fix unwrap() to unwrap_or_default() in RuntimeConfig for robustness
    - Align power consumption figures between ARCHITECTURE.md and HARDWARE.md
    - Add CONTRIBUTING.md, TESTING.md, TROUBLESHOOTING.md, CHANGELOG.md
    - Add .gitignore, rustfmt.toml, clippy.toml
    https://claude.ai/code/session_01XHnfZQ5BbxTCTBMCteQyVe
    [config.rs, main.rs, power.rs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]
2026-02-27 Add industry sensor drivers and feature flags for Agriculture and Solar
    - Add Cargo feature flags: agriculture, solar, all-industries
    - Add config constants for agriculture (soil, GDD, frost, ET, irrigation)
    - Add config constants for solar (irradiance, panel temp, yield, soiling)
    - Add soil moisture driver (capacitive ADC, dual-depth probes)
    - Add DS18B20 soil/panel temperature driver (1-Wire protocol)
    - Add leaf wetness sensor driver (resistive, with duration tracking)
    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
2026-02-27 Add Agriculture and Solar industry modules with analytics engines
    Agriculture (--features agriculture):
    - Sensor drivers: capacitive soil moisture (dual-depth), DS18B20 soil
    temp, leaf wetness with duration tracking
    - FAO Penman-Monteith ET₀ with Hargreaves-Samani fallback
    - Growing Degree Days with configurable crop base temperatures
    - Multi-level frost alerts with humidity-adjusted radiative frost model
    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
2026-02-27 Fix code quality issues: precision, safety, and performance
    - Fix heat index calculation to use f64 intermediates for polynomial precision
    - Add division-by-zero guards in dew point (Magnus) and ET₀ (Penman-Monteith)
    - Add wind direction NaN/Inf guard before EMA filter processing
    - Fix wind chill boundary condition (v < 5.0 instead of v <= 4.8)
    - Add alert deduplication for solar (overheat, PR, soiling) and agriculture
    (irrigation, disease) to prevent MQTT flooding
    - Fix solar soiling loss double-counting by tracking gross vs net yield
    - Add NOCT delta (25°C) for panel temp estimation from ambient temperature
    - Tighten solar performance ratio guard to require >1W theoretical power
    - Add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
    [config.rs, main.rs]
2026-02-28 Add KiCad hardware design: schematics, PCB layout, and BOM
    KiCad 7 project with hierarchical schematic design:
    - Top-level: ESP32-S3-WROOM-1-N16R8I with decoupling, boot/reset
    buttons, status LED, and GPIO pin map
    - Power supply: USB-C + solar input, TP4056 LiPo charger with
    DW01A protection, AMS1117-3.3 LDO, battery voltage divider
    - Sensors: I2C bus (BME280, AS5600, SI1145, BH1750) with pull-ups
    and decoupling, RJ11 anemometer/rain gauge with debounce
    - Communication: SX1276 LoRa with PI matching network and SMA
    antenna, UART debug header with series protection resistors
    - Industry: Agriculture (soil moisture, soil temp DS18B20, leaf
    wetness) and Solar (pyranometer, panel temp, p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
    [BOM.csv, WeatherStation.kicad_pcb, WeatherStation.kicad_sch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]
2026-02-28 Update KiCad schematic with detailed sensor interface design
    Expanded the top-level schematic with comprehensive sensor interfaces
    including I2C, SPI, UART, and ADC connections for the ESP32-S3 weather
    station. Added hierarchical design structure with proper pin assignments.
    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
    [WeatherStation.kicad_sch]
2026-02-28 Add comprehensive cost estimate for weather station build
    Covers all cost categories: electronic BOM ($145-191), PCB fabrication &
    assembly ($42/board), testing & calibration ($55-97/unit), outdoor station
    enclosure & mounting ($198), and packaging/shipping ($43). Includes volume
    pricing estimates and cost optimization opportunities.
    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
2026-03-15 Add STM32F407 MCU support with SCADA/Cloud/Hybrid operating modes
    Dual-MCU architecture: STM32F407VGT6 handles sensor acquisition and
    Modbus RS485 SCADA, ESP32-S3 handles cloud connectivity (MQTT/HTTP).
    New firmware modules:
    - drivers/stm32f407.rs: MCU HAL with pin assignments, clock config,
    Modbus RS485 params, OperatingMode enum (Cloud/SCADA/Hybrid),
    DIP switch mode selection, ESP32 bridge protocol definition
    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
    [BOM.csv, stm32_scada.kicad_sch]
2026-03-15 Migrate to single-MCU architecture: STM32F407 with external connectivity modules
    Remove ESP32-S3 dual-MCU design. STM32F407VGT6 is now the sole MCU with:
    - ATWINC1500 WiFi (SPI3), RN4870 BLE (USART3), W5500 Ethernet (SPI2),
    SIM7600E-H cellular (UART4) as external connectivity modules.
    - Updated Cargo.toml for stm32f4xx-hal, cortex-m-rt, embedded-alloc
    - New memory.x for STM32F407 (1MB Flash, 128KB RAM, 64KB CCM)
    - New drivers: atwinc1500.rs, w5500.rs, sim7600.rs, rn4870.rs
    - Updated error.rs with WiFi module, BLE, cellular, ethernet errors
    - Updated stm32f407.rs with all new pin assignments
    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
    [atwinc1500.rs, error.rs, rn4870.rs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]
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2026-03-15 feat: complete single-MCU migration — remove ESP32-S3, add ATWINC1500/RN4870/W5500/SIM7600
    Migrate from dual-MCU (ESP32-S3 + STM32F407) to single-MCU (STM32F407VGT6 only)
    with external communication modules:
    Firmware changes:
    - Rewrite wifi.rs for ATWINC1500 SPI driver, ble.rs for RN4870 UART driver
    - Remove all #[cfg(feature = "stm32")] gates — STM32 is now the only target
    - Remove bridge protocol (BridgeSync task, USART3 bridge)
    - Add PollWifi/PollBle/PollCellular/PollEthernet scheduler tasks
    - Update power modes: Sleep(WFI)/Stop/Standby for STM32
    - Update OTA for STM32 dual-bank flash swap
    - Update config: HEAP 48KB, flash sector 4, new module constants
    - Update mode_manager with tra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
    [BOM.csv, WeatherStation.kicad_sch, communication.kicad_sch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]
2026-03-15 feat: add SD card storage on SPI2 shared bus (sdcard feature)
    Add micro-SD card data logging with FAT32 CSV format and daily file
    rotation. The SD card shares SPI2 with W5500 Ethernet, using
    CriticalSectionDevice for bus arbitration (CS=PD10, detect=PD11).
    New files:
    - drivers/sdcard.rs: SPI SD card driver wrapper (embedded-sdmmc)
    - storage/sdcard.rs: FAT32 CSV logger with 512-byte sector buffer
    Key changes:
    - Cargo.toml: embedded-sdmmc + embedded-hal-bus deps, sdcard feature
    - config.rs: SD card pin/clock/timing constants
    - scheduler.rs: FlushSdCard task (60s interval), MAX_TASKS 24→26
    - main.rs: SD card init, store-with-flash-fallback in ProcessData
    - error.rs: SdCardNotInserted/InitFa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
    [BOM.csv, communication.kicad_sch]
2026-03-19 fix: remove invalid ;; comments from KiCad schematics and add SD card circuit
    KiCad's S-expression parser does not support semicolon comments.
    All ;; comment lines have been stripped from the 5 .kicad_sch files
    and WeatherStation.kicad_sym to fix "Expecting '('" parse errors.
    Also adds the SD card circuit to communication.kicad_sch:
    - J22 MicroSD_SPI holder with SPI2 bus connections
    - C38 100nF VCC decoupling capacitor
    - R27 10k pull-up on card detect line
    - SPI2_SCK/MISO/MOSI/SD_CS/SD_DET hierarchical labels
    - Wire routing and power symbols (+3V3, GND)
    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
    [communication.kicad_sch, industry.kicad_sch, power_supply.kicad_sch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]
2026-03-19 Add P9E Microsystems branding to board markings
    Front silkscreen: P9E (bold), P9E Microsystems Pvt Ltd, www.p9e.in
    Back silkscreen: P9E Microsystems Pvt Ltd + www.p9e.in added
    Title blocks: company updated to P9E Microsystems Pvt Ltd
    Also updated PCB title/rev/date for STM32F407 v2.0
    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
    [WeatherStation.kicad_pcb, WeatherStation.kicad_sch]
2026-03-20 feat: add ATWINC1500, RN4870, W5500, SIM7600 to communication schematic
    Add all 4 industrial communication module circuits to communication.kicad_sch:
    - U12 ATWINC1500 WiFi (SPI3): QFN-28, J18 SMA antenna, C28/C29 decoupling
    - U13 RN4870 BLE (USART3): UART module, C30/C31 decoupling
    - U14 W5500 Ethernet (SPI2): LQFP-48, Y2 25MHz crystal + C32/C33 load caps,
    J19 RJ45 Magjack, C26/C34 decoupling
    - U15 SIM7600E-H Cellular (UART4): LTE Cat-4, U16 TPS7A2033 3.8V LDO,
    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
    [communication.kicad_sch]
2026-03-20 feat: add manufacturing-ready PCB layout with 80+ component footprints
    Generate WeatherStation_mfg.kicad_pcb with complete component placement:
    MCU & Control:
    - U10 STM32F407VGT6 (LQFP-100) with 100 pads, all net assignments
    - Y1 8MHz crystal + C20/C21 load caps + 4x decoupling caps
    - U11 MAX3485 RS485 + J16 Phoenix terminal + D10 TVS
    Communication Modules:
    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
    [WeatherStation_mfg.kicad_pcb]
2026-03-20 fix: add 3 missing BOM components to manufacturing PCB
    Add U2A (DW01A battery protection IC), Q1 (FS8205A dual N-MOSFET
    for battery protection), and C4 (1uF AS5600 decoupling cap) that
    were missing from the PCB layout. All BOM components now have
    corresponding footprints in the manufacturing PCB.
    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
    [WeatherStation_mfg.kicad_pcb]
2026-03-20 fix: correct connector pin counts, capacitor size, and add R6d
    Fixes from detailed BOM cross-reference audit:
    - J12 (Pyranometer): Changed from 3-pin to 4-pin JST (B4B-PH-K)
    per BOM spec (V+/GND/OUT/EN)
    - J15 (Power Pulse): Changed from 3-pin to 2-pin JST (B2B-PH-K)
    per BOM spec (SIG/GND, S0 pulse interface)
    - C30 (W5500 bulk decoupling): Fixed from 0402/100nF to 0805/10uF
    per BOM specification
    - R6d: Added 4th 1k LED series resistor (BOM Qty=4, only 3 existed)
    All 124 component references now match BOM specifications.
    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
    [WeatherStation_mfg.kicad_pcb]
2026-03-20 style: apply P9E 3-line label format on front and back silkscreen
    Front silkscreen (F.SilkS) — 3-line P9E label block:
    Line 1: P9E (3.5mm bold, company mark)
    Line 2: P9E Microsystems Pvt Ltd (1.2mm bold, full name)
    Line 3: www.p9e.in (1.0mm, website)
    Product info kept separate below the label block:
    Weather Station v2.0 | STM32F407VGT6 | Industrial -40C/+105C
    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
    [WeatherStation.kicad_pcb, WeatherStation_mfg.kicad_pcb]
2026-03-20 fix: remove ;; comments from kicad_pcb files (invalid S-expression syntax)
    KiCad PCB files use S-expression format which does not support ;; comments.
    The comment lines caused a parse error at line 102 when opening in KiCad.
    Removed all standalone comment lines from both PCB files.
    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
    [WeatherStation.kicad_pcb, WeatherStation_mfg.kicad_pcb]
2026-03-20 fix: remove ;; comments from communication.kicad_sch (KiCad parse error)
    Same issue as the PCB files — KiCad S-expression format does not support
    ;; comments. Removed 46 comment lines causing parse error at line 2022.
    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
    [communication.kicad_sch]
2026-03-20 fix: correct net_label→label and comma in coordinates for KiCad
    - communication.kicad_sch: replaced 12 instances of invalid `net_label`
    keyword with `label` (valid KiCad schematic syntax)
    - WeatherStation_mfg.kicad_pcb: fixed `(at 22, 58)` → `(at 22 58)`,
    commas are not valid separators in S-expressions
    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
    [WeatherStation_mfg.kicad_pcb, communication.kicad_sch]
2026-03-20 fix: remove invalid 'justify center' from PCB files
    KiCad PCB format only accepts left/right/top/bottom/mirror for justify.
    Center is the default, so (justify center) is removed entirely and
    (justify center mirror) becomes (justify mirror).
    Fixed in both WeatherStation.kicad_pcb and WeatherStation_mfg.kicad_pcb.
    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
    [WeatherStation.kicad_pcb, WeatherStation_mfg.kicad_pcb]
2026-04-19 Fix 1: sensors.kicad_sch — add BME280 CSB→VCC, SDO→GND; AS5600 DIR→GND, OUT/PGO no-connect; BH1750 ADDR→GND
    Agent-Logs-Url: https://github.com/ppusapati/weather/sessions/bf78e071-0670-4802-a032-1f4282b37237
    [sensors.kicad_sch]
2026-04-19 Fix 2: WeatherStation.kicad_sch — remove ESP32-S3, add STM32F407 sub-sheet, fix title/pin annotations
    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
    [WeatherStation.kicad_sch]
2026-04-19 Fix 3: stm32_scada.kicad_sch — remove ESP32 bridge J17/R23/R24, remove ESP32_BRIDGE labels, update DESIGN NOTES
    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
    [stm32_scada.kicad_sch]
2026-04-19 Fix 4: power_supply.kicad_sch — fix AMS1117 cap note, add VBAT cap, fix battery label, update power budget
    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
    [power_supply.kicad_sch]
2026-04-19 Fix 5: circuit_diagram.md — add I2C pin connection table, update power supply decoupling notes
    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
2026-04-19 Fix review comments: clarify battery voltage spec and AMS1117 capacitor type notes
    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
    [power_supply.kicad_sch]
